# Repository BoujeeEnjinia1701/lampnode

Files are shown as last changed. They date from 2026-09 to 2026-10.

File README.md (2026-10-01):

# LampNode

     

**Area:** Smart Cities · **TRL:** 3 of 9 (proof of concept on paper) · **Value-engineering target:** about $150 USD · **Difficulty:** 3 of 5

An open streetlight controller that dims LED streetlights by schedule and presence, reports faults and hosts other city sensors on the lamp pole.

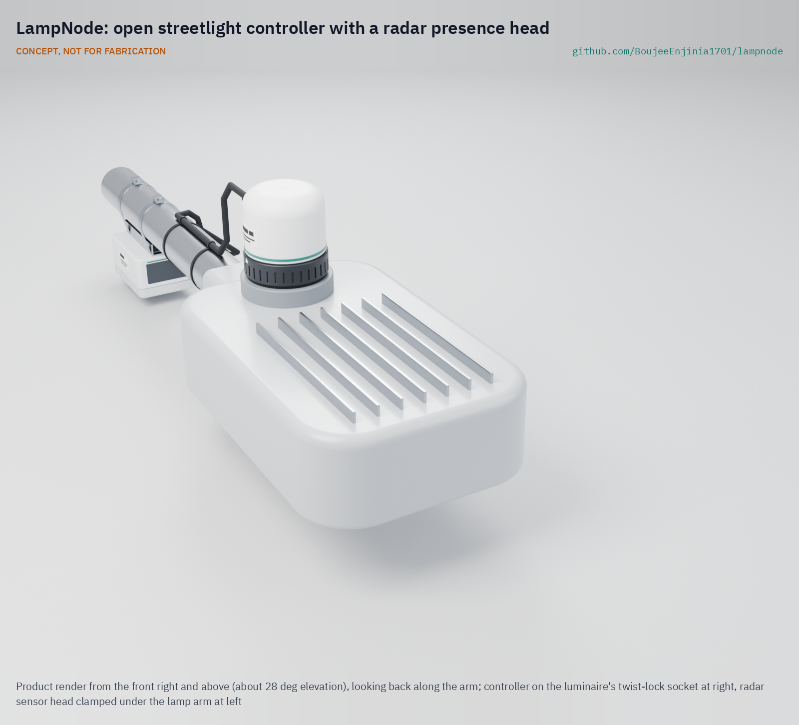
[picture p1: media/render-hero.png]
LampNode: open streetlight controller with a radar presence head, product render


[Exploded render](media/render-exploded.png) · [Detail render](media/render-detail.png) · [Interactive 3D model](media/viewer.html) · [Concept blueprint (PDF)](media/concept-blueprint.pdf) · [General arrangement LPN-DWG-001 (PDF)](cad/drawings/LPN-DWG-001.pdf) · [Sizing calculations](docs/04-calcs/01-sizing.md) · [Prototype build plan](docs/05-build-plan.md) · [Design decisions](docs/06-design-decisions.md) · [Review note](docs/REVIEW.md)

## Concept rationale

Many LED streetlights already have a twist-lock socket on top, built for a photocell, and the D4i driver standard supports both the NEMA/ANSI C136.41 and the Zhaga Book 18 sockets ([DALI Alliance](https://www.dali-alliance.org/d4i/)). A controller that plugs into that socket can dim the lamp, measure its energy and report faults without anyone opening the luminaire or the pole. LampNode uses that socket, the 0 to 10 V dimming input most LED drivers already have, and a small radar head under the arm that raises the light only when someone is coming. Because the controller already has mains power and a radio on the pole, the same head offers two powered ports for other city sensors, so a street can gain air, noise or traffic sensing without new wiring.

It is open and garage-buildable because the main problem with smart streetlights is not the electronics but lock-in: the controller, network and software usually come from one supplier. LampNode uses a standard socket, the same LoRaWAN radio as the lab's FieldNode, and a published message format, so a city, a utility or a campus can build, inspect or replace any part of it and read its data with any LoRaWAN server, including TwinKit and CityTwin.

## Burning platform

Streetlights mostly burn at full power all night, and cities often cannot see what they use: the US Energy Information Administration says it has no estimate of electricity use for public street and highway lighting ([EIA](https://www.eia.gov/tools/faqs/faq.php?id=99&t=3)). Yet the savings from dimming are large. On 14 LED-lit Swedish roads, a dimming schedule alone could save about 49 % of the energy ([Jägerbrand, 2016](https://www.mdpi.com/1996-1073/9/5/357)). Meanwhile citizen observations from 2011 to 2022 are consistent with the night sky brightening by 7 to 10 % per year ([Kyba et al., 2023, via GFZ](https://www.gfz.de/en/press/news/details/citizen-scientists-report-global-rapid-reductions-in-the-visibility-of-stars-from-2011-to-2022)).

Faults are still found by people. New York City maintains nearly 400,000 streetlights and asks residents to call 311 to report problems ([NYC DOT](https://www.nyc.gov/html/dot/html/infrastructure/streetlights.shtml)). Networked controllers exist, but the industry's own interoperability body describes its protocol as a way to "avoid vendor-lock-in" ([TALQ](https://www.talq-consortium.org/)), which is why an open device matters.

## Where it could be used

### By industry

| Industry | Use |
| --- | --- |
| Municipal street lighting and public works | Night dimming, fault lists for crews, and energy data per lamp on residential and collector roads |
| Electric utilities that own streetlights | Day-burner detection, measured energy per lamp, remote switching during grid events |
| Road and highway authorities | Adaptive lighting on low-traffic roads within the lighting class they set |
| Campuses, ports, car parks and industrial sites | Presence dimming on private roads and yards with their own LoRaWAN gateway |
| Smart city sensing | A powered, networked mount for air, noise and traffic sensors (AirStreet, NoiseMap, CurbCount) |
| Housing associations and private estates | Lower lighting bills and fault reports on private streets |

### By country or region

| Country or region | Why it matters there |
| --- | --- |
| United States | Large networks with faults still reported by residents: New York City maintains nearly 400,000 streetlights and asks residents to call 311 about problems ([NYC DOT](https://www.nyc.gov/html/dot/html/infrastructure/streetlights.shtml)); LampNode targets the NEMA/ANSI C136.41 socket, which D4i drivers also support ([DALI Alliance](https://www.dali-alliance.org/d4i/)) |
| Sweden and the Nordic countries | Long winter nights; a dimming schedule could save about 49 % on the Swedish roads studied ([Jägerbrand, 2016](https://www.mdpi.com/1996-1073/9/5/357)) |
| European Union | Luminaires with Zhaga Book 18 sockets and D4i drivers can power and host a module with no rewiring ([DALI Alliance](https://www.dali-alliance.org/d4i/)); a Zhaga variant of LampNode is an open question |
| India | By June 2024 the Street Lighting National Programme had installed more than 13 million LED streetlights in 29 states and union territories, saving an estimated 8,806 GWh a year ([PIB, 2024](https://www.pib.gov.in/PressReleasePage.aspx?PRID=2040102&reg=48&lang=2)); a retrofit controller could add presence dimming and fault reports to that installed base |
| Philippines | In Quezon City, street lighting made up 65 % of the city's electricity costs and 5 % of its overall budget ([World Bank, 2017](https://blogs.worldbank.org/en/energy/led-street-lighting-unburdening-our-cities); [case study](https://documents.worldbank.org/curated/en/842031477930270833/)), so every hour of dimming shows up in the city's accounts |
| Brazil | Public lighting uses about 4 % of the country's electricity and 10 to 40 % of municipal energy budgets; Belo Horizonte is upgrading 178,000 streetlights to LED under a 20-year PPP contract ([ESMAP](https://www.esmap.org/node/57541)), a term over which open, multi-vendor controllers would let a city change suppliers |

## What sparked the idea

The starting point was Detroit. By mid-2013 more than half of the city's 88,000 streetlights were estimated to be out; the relighting that began in April 2014 replaced them with 65,000 LED lights for $185 million ([US Department of Energy](https://www.energy.gov/eere/ssl/articles/detroit-street-lighting-report)) and was finished in December 2016 ([Michigan Public, 2016](https://www.michiganpublic.org/news/2016-12-16/detroit-celebrates-65-000-new-led-streetlights)). In May 2019 the city's Public Lighting Authority sued the manufacturer over about 20,000 of those fixtures, a third of the new system, that were dimming and burning out early ([Michigan Public, 2019](https://www.michiganpublic.org/law/2019-05-07/some-of-detroits-new-led-streetlights-are-burning-out-city-sues-manufacturer)). Even a brand-new, efficient network could degrade at scale before its owner had the data to see it. A small controller on each lamp that measures its power and reports a lamp that is out, cycling or drawing the wrong power would let the owner see such faults as they develop, and an open design would let any city fit, inspect and repair it without tying the network to one supplier.

## Problem

Streetlights burn at full power all night, faults are reported by residents, and proprietary controllers lock cities into one vendor.

## Concept

An open streetlight controller that dims LED streetlights by schedule and presence, reports faults and hosts other city sensors on the lamp pole.

A twist-lock controller replaces the photocell on the luminaire and drives its 0 to 10 V dimming input; a sensor head clamped under the arm carries a 24 GHz radar for presence and two powered M12 ports for other sensors; status and faults go out every 15 min over LoRaWAN.

TRL 3 calculations ([LPN-CAL-001](docs/04-calcs/01-sizing.md)) put a 100 W luminaire at 40° N at about 432 kWh a year under a photocell and 275 to 285 kWh with the reference presence profile, a saving of 34 to 36 % against a 35 % target. The controller draws 0.68 W on average, and the parts of the constructable design are estimated at USD 143, USD 7 under the USD 150 value-engineering target. No requirement is clearly missed, but four are at risk on paper: relay inrush, presence detection in rain and wind, the energy saving (kept at a 35 % target with the risk accepted) and the temperature margin in full sun. Power for hosted sensors is met on paper because the firmware limits the ports to 2.5 W above 50 °C inside. 347 V and 480 V circuits, DALI-2 D4i dimming and a TALQ bridge are later variants or sibling scope. The design choices were decided by Amish on 2026-09-25 ([LPN-DDR-001](docs/decisions/0001-trl2-review-decisions.md), [LPN-DDR-002](docs/decisions/0002-recommendations-accepted.md)); only the first co-design partner is still open. See the [requirements](docs/03-requirements.md).

Full design precis: [docs/02-concept.md](docs/02-concept.md)

## Key components

- Twist-lock base for the ANSI C136.41 7-contact receptacle
- 385 V class surge stage, isolated 12 V power supply and a normally closed (fail-on) relay closed at the voltage zero crossing
- Energy metering (indicative, not revenue grade), calibrated once at build
- STM32WL-class controller with LoRaWAN radio (shared with FieldNode), TCXO clock and tilt sensor
- 0 to 10 V dimming output and ambient light sensor
- Sensor head under the arm with a 24 GHz radar presence sensor with direction (I/Q) output
- Two sealed 5-pole M12 expansion ports, 12 V SELV, 3 W total (2.5 W above 50 °C inside)

The parametric model is in [cad/src/model.py](cad/src/model.py), with STEP and STL exports in `cad/step/` and `cad/stl/`. The working bill of materials is in [bom/bom.csv](bom/bom.csv).

## Building the prototype

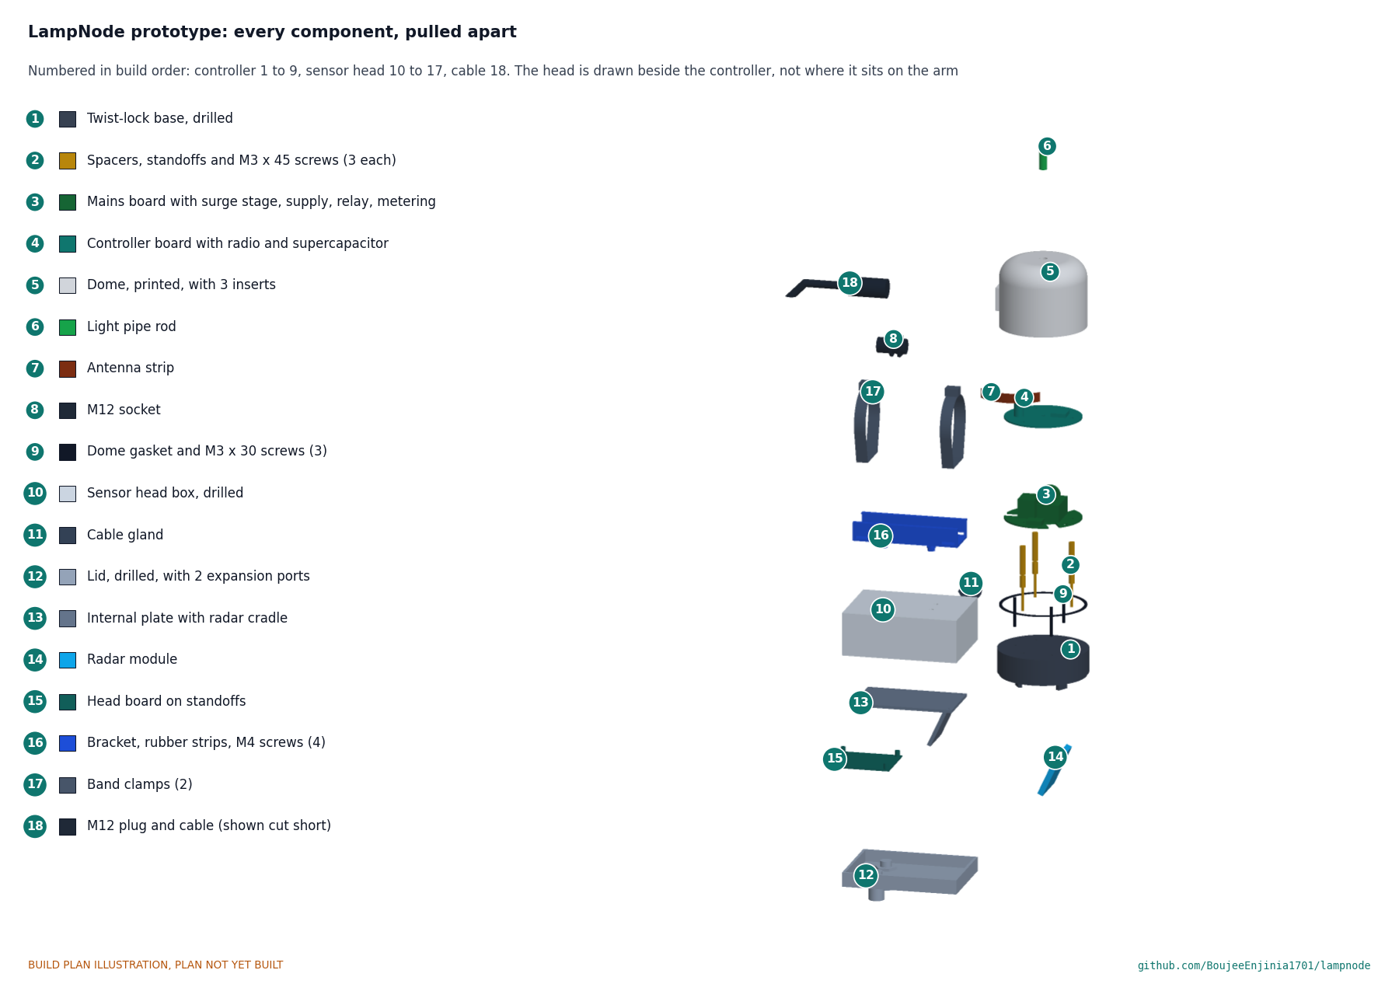
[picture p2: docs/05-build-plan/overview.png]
LampNode prototype: every component pulled apart and numbered in build order


The [prototype build plan](docs/05-build-plan.md) (LPN-BLD-001) shows, in pictures, how to make each of the eighteen components and put them together in eleven steps on a bench mock-up of a streetlight; nothing has been built yet. The made parts are a drilled twist-lock base, two round prototype boards, a printed dome with a light-pipe rod, a drilled sensor head box, a printed internal plate with a radar cradle and a folded aluminium bracket; the electronics are bought modules wired at block level. Writing the plan made the design buildable: the parts inside the controller and the head now sit on spacers, standoffs and bosses, the dome screws to the base, the M12 socket moved to a flat pad on the dome, and the bracket became a folded channel that the band clamps pass through (LPN-DDR-003, open for Amish's review). Every picture is drawn from the model, and the model checks that each part touches what it should and clears what it should not.

## Safety

> Mains wiring must be done or checked by a qualified electrician and follow local electrical code. LampNode connects to up to 277 V AC in the luminaire socket; a prototype must not go on a public lighting network until it has passed the tests the asset owner requires. Street furniture and pole mounts must be installed only with the asset owner's permission, by trained crews, with fall protection and traffic management as local rules require.
>
> A controller fault must never leave a street dark: the relay fails on, and light levels are set by the road owner, not by LampNode. The socket has no earth contact, so surge protection is line to neutral only. Privacy by design: the radar reports motion only; no images, audio recordings or personal identifiers leave the device.

## Repository layout

| Folder | Contents |
| --- | --- |
| `docs/` | Problem, concept, requirements, calculations and design decisions |
| `cad/src/` | build123d Python source, the source of truth for all geometry |
| `cad/step/`, `cad/stl/` | Exported models for FreeCAD, other CAD tools and printing |
| `cad/drawings/` | 2D sketches and dimensioned drawings |
| `bom/` | Bill of materials |
| `electronics/` | KiCad schematics and PCB layouts |
| `firmware/` | Microcontroller code |
| `media/` | Renders, perspectives and photos |
| `build-log/` | Dated prototyping notes |

## Documentation

Controlled documents follow the portfolio [documentation standard](.kit/STANDARDS.md). Each carries a document ID (LPN-PRC-001 for the precis), a version and a revision history. Branded PDFs are built with `python .kit/render.py` and attached to GitHub Releases when a document is tagged, for example `LPN-PRC-001/v1.0`.

## Credits

Designed by Amish Chadha. See [CONTRIBUTORS.md](CONTRIBUTORS.md) for roles. To cite this design, use [CITATION.cff](CITATION.cff) (GitHub shows it as "Cite this repository").

AI assistance (Claude) was used to accelerate concept renders, prototype documentation and first-pass sizing calculations. Design direction and all decisions are Amish Chadha's, recorded in this repository's decision records (`docs/decisions/`).

## Licenses

- **Hardware** (CAD, drawings, BOM, electronics): [CERN-OHL-S v2](LICENSE)
- **Software** (firmware, scripts, notebooks): [MIT](LICENSE-SOFTWARE)

A project of the [Design Molecule](https://designmolecule.com) lab.

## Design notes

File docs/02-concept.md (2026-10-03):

---
doc_id: LPN-PRC-001
title: LampNode design precis
project: LampNode
doc_type: Design precis
version: "0.7"
status: Draft
date: '2026-10-02'
author: Amish Chadha
license: CERN-OHL-S-2.0
revisions:
- version: "0.1"
  date: '2026-09-25'
  author: Amish Chadha
  change: Initial scaffold
- version: "0.2"
  date: '2026-09-25'
  author: Amish Chadha
  change: Concept for TRL 2, main components, first-order numbers, design choices, safety and open questions
- version: "0.3"
  date: '2026-09-25'
  author: Amish Chadha
  change: TRL 3 update. Design choices adopted for TRL 3 under Amish's 2026-09-25 instruction, open for his review (LPN-DDR-001); numbers replaced by LPN-CAL-001; relay, clock, surge stage, radar and port changes; parametric model and drawing LPN-DWG-001
- version: "0.4"
  date: '2026-09-25'
  author: Amish Chadha
  change: Recommendations accepted by Amish (DDR-002)
- version: "0.5"
  date: '2026-10-01'
  author: Amish Chadha
  change: Design made constructable (LPN-DDR-003); component descriptions, mass and cost updated; budget treated as a value-engineering target
- version: "0.6"
  date: '2026-10-02'
  author: Amish Chadha
  change: 'Decisions of 2026-10-02 (LPN-DEC-001): first partner and band, port pinout proposed to FieldNode'
- version: "0.7"
  date: '2026-10-02'
  author: Amish Chadha
  change: 'US915 airtime limit (400 ms dwell) added to the key figures; figures and pictures regenerated; no requirement status changed'
---

# LampNode design precis

## Summary

LampNode is a twist-lock controller that replaces the photocell on top of an LED streetlight, plus a small sensor head clamped under the lamp arm. The controller switches and dims the luminaire over its standard 0 to 10 V input, follows a night schedule held on the device, raises the light when the sensor head's radar sees someone approaching, measures the lamp's energy and reports faults over LoRaWAN. The sensor head also offers two powered, sealed ports for other city sensors.

The TRL 3 calculations (LPN-CAL-001) put the energy of a 100 W luminaire at 40° N at about 432 kWh a year under a photocell and about 275 to 285 kWh with the reference presence profile, a saving of **34.1 to 36.4 %** against the 35 % target of R7. The TRL 2 estimate of about 41 % assumed nights that were too uniform. The controller draws 0.68 W on average, and the parts are estimated at USD 143.00 against a USD 150 value-engineering target (USD 7.00 under it). Four requirements are at risk on paper (R3, R6, R7, R11); none is clearly not met. R13 is met on paper once the firmware limits the hosted ports to 2.5 W above 50 °C inside. The design choices below were decided by Amish on 2026-09-25 (LPN-DDR-001, LPN-DDR-002).

Figure 1 (`media/hero.png`) shows LampNode on a 7.8 m street pole with a 1.75 m person for scale; Figure 2 (`media/exploded.png`) numbers the parts to match `bom/bom.csv`; Figure 3 (`media/cutaway.png`) shows the inside of the controller; Figure 4 (`media/flow.png`) shows the annual energy; Figure 5 (`cad/drawings/LPN-DWG-001.pdf`) is the general arrangement at Rev P4, generated from `cad/src/model.py`. The design was made constructable on 2026-09-30 (LPN-DDR-003); how each part is made and fitted is in the prototype build plan, LPN-BLD-001 (`docs/05-build-plan.md`).

## How it works

1. **At dusk** the light sensor sees the light level fall below a set threshold, or the astronomical clock reaches dusk. The controller treats it as day only when both the clock and the light sensor say day, so a failed sensor or a wrong clock leaves the lamp on. The lamp starts at the level the road owner set; the default is full output.
2. **During the night** the controller steps the 0 to 10 V output through the road owner's schedule, for example full output until 22:00, then a lower floor.
3. **When someone approaches** the radar in the sensor head sees motion toward the lamp. The radar has I/Q (direction) output, so rain, which always moves away from a downward-looking beam, is ignored. The head tells the controller over the M12 cable, and the controller ramps the lamp to full output in about 0.63 s, holds it for a set time and ramps back down.
4. **Every 15 min** the controller sends a 24-byte LoRaWAN status message: energy, power, voltage, dimming level, presence count and fault flags. Schedules and settings come back as downlinks, and the network also sets the clock, but the lamp never depends on the network to run. A TCXO real-time clock keeps drift under 10 s a month without the network.
5. **When something goes wrong** the controller sends a fault message at once: lamp out, lamp burning in daylight, cycling, pole tilted or knocked down, or mains lost (a 0.22 F supercapacitor holds about 9 times the energy of a last message). A gateway such as TwinKit, or any LoRaWAN network server, flags a node that goes silent.
6. **When the dome gets hot** the controller limits the two expansion ports to 2.5 W in total while its interior is above 50 °C, so the 5 W supply stays within its derated output (LPN-DDR-002). Hosted sensors must tolerate the lower allowance.
7. **If the controller fails** the relay closes and the lamp stays on. The relay coil is driven through a charge pump that needs a toggling signal from the controller, so a stopped or hung controller drops the coil. An open 0 to 10 V line leaves typical drivers at full output.
8. **When the relay switches** it closes at a zero crossing of the mains voltage, timed from the metering IC, which cuts the LED driver inrush from about 72 A to about 20 A.

## Main components

Numbers match Figure 2 and `bom/bom.csv`.

| No. | Component | Role |
| --- | --- | --- |
| 1 | Twist-lock base, 7-contact | ANSI C136.41 plug: line, neutral and switched load blades; four low-voltage contacts for dimming and two auxiliary lines. There is no earth contact. Six countersunk screws from underneath hold the dome and the board stack |
| 2 | Dome cover | UV-stabilized ASA, 90 mm diameter, 72 mm tall on a 1 mm gasket, 97 mm tall with the base; three screw bosses, a flat pad for the M12 socket and an 8 mm light-pipe hole |
| 3 | Surge protection and fuse | Thermal fuse and a thermally protected 20 mm, 385 V class varistor line to neutral; TVS diodes on the low-voltage leads |
| 4 | Isolated power supply | 85 to 305 V AC in, 12 V out, 5 W; creates the SELV side that feeds the electronics, the dimming output and the expansion ports |
| 5 | Fail-on relay | Normally closed, 16 A, rated for 80 A inrush or better; coil (about 0.4 W) energized in daytime only |
| 6 | Energy metering | Single-phase metering IC with a 2 mΩ shunt on the mains side, linked to the controller through a digital isolator; one-point calibration at build |
| 7 | Controller and LoRaWAN radio | STM32WL-class module shared with FieldNode, TCXO real-time clock, accelerometer, 0 to 10 V output stage, charge-pump coil drive, 0.22 F supercapacitor for the last message |
| 8 | Antenna | Sub-GHz antenna inside the dome, above the luminaire's metal body |
| 9 | Light sensor and pipe | Ambient light sensor under a clear 8 mm rod sealed through the dome top, for dusk and dawn and for day-burner checks |
| 10 | M12 port and cable | 5-pole M12 socket in a flat pad on the pole side of the dome and about 1 m of cable along the arm to the sensor head: 12 V and a two-wire serial link |
| 11 | Sensor head enclosure | IP66 box 120 x 90 x 60 mm clamped under the arm, 470 mm from the receptacle toward the pole |
| 12 | 24 GHz radar presence sensor | Doppler module with I/Q output, tilted 25° below horizontal along the street; motion, speed and direction only |
| 13 | Sensor head board | Small microcontroller that turns the radar signal into presence events, and switches power to the expansion ports |
| 14 | Expansion ports (2) | Sealed 5-pole M12 sockets with the pinout proposed to FieldNode (pin 1 supply, pin 3 ground, pins 2 and 4 RS-485, pin 5 wake), 12 V SELV, 3 W total |
| 15 | Arm band clamps | Two stainless band clamps for 50 to 80 mm arms through slots in a folded aluminium bracket, with rubber strips where the arm rests; no drilling of the arm |
| 17 | Controller boards and fixings | Round mains board on three spacers carrying items 3 to 6, standoffs to the controller board, screws, inserts and the dome gasket |
| 18 | Head internal plate | Printed plate on the box bosses, carrying the head board and a 25° cradle for the radar |

The luminaire, its receptacle, the arm and the pole are existing street furniture and are not part of LampNode. The model shows the receptacle and a length of arm as grey reference parts.

## Numbers at TRL 3

All values come from LPN-CAL-001 and `docs/04-calcs/sizing.py`. They are calculations with typical part values, not measurements.

*Table 1. Annual energy for one 100 W luminaire at 40° N (4,323 h a year).*

| Case | Energy per year | Saving |
| --- | --- | --- |
| Photocell, full power | 432 kWh | |
| Schedule only (50 % from 23:00 to 05:00) | 324 kWh | 25.0 % |
| Reference presence profile with controller use, ideal driver | 275 kWh | 36.4 % |
| Same, dimmed driver model | 285 kWh | 34.1 % |

The saving depends mostly on traffic. With the dimmed driver model it is 40.4 % with no traffic, 34.4 % at 8 isolated passes an hour and 22.0 % at 30. At 60° N it falls to 31.8 %. The saving is of the same order as the 49 % that Jägerbrand estimated for a dimming schedule on Swedish roads ([Jägerbrand, 2016](https://www.mdpi.com/1996-1073/9/5/357)).

*Table 2. Other key figures.*

| Quantity | Value | Requirement |
| --- | --- | --- |
| Average draw from the mains | 0.68 W | R10 met |
| 12 V peak, ports limited to 2.5 W above 50 °C inside | 3.40 W against 3.57 W available at 64 °C (3.90 W against 3.55 W without the limit) | R13 met on paper |
| Inrush, 100 W driver at 277 V | 72 A at random closing, about 20 A at zero-cross closing | R3 at risk |
| Clock drift without the network, 30 days | 9.1 s with the TCXO clock (160 s at -10 °C with a plain crystal) | R5 met on paper |
| Radar | Beam covers 7.5 to 47.9 m for a walking person; 36 dB signal to noise at 15 m; 0.63 s to full | R6 at risk |
| Metering error | 1.65 % worst case with a one-point calibration | R8 met on paper |
| Status airtime | 267 ms per message, 25.7 s a day at SF9 (US915: inside the 400 ms dwell limit; SF9 or faster) | R15 |
| Interior temperature at 45 °C in sun | 63 to 65 °C | R11 at risk |
| Varistor energy at 5 kA | 118 J | R11 |
| Mass | Controller 0.33 kg; head with clamps and cable 0.42 kg | |
| Parts cost | USD 143.00 (controller USD 75.00, head USD 61.00, hardware USD 7.00) against the USD 150 value-engineering target | R16: USD 7.00 under the target |
| Payback on parts | 3.9 to 9.7 years at USD 0.25 to 0.10 per kWh, before labor | |

## Key design choices

Each choice below is **Decided by Amish, 2026-09-25: go with recommendation** (LPN-DDR-001, LPN-DDR-002).

1. **Socket:** ANSI C136.41 7-contact first, since it is the photocontrol socket widely used on existing roadway luminaires in North America and suits retrofits; a Zhaga Book 18 variant later for newer D4i luminaires.
2. **Presence sensor:** 24 GHz Doppler radar, which senses motion through a plastic cover, is not blinded by heat and cannot form an image; schedule-only operation stays as a firmware mode.
3. **Sensor head link:** a cable from the controller to a head under the arm, so one mains connection powers both.
4. **Radio:** LoRaWAN on the STM32WL-class module shared with FieldNode and TwinKit.
5. **Dimming:** 0 to 10 V only; DALI-2 D4i on the auxiliary contacts only if a partner's stock needs it.
6. **Fail-on relay:** normally closed contact, energized to turn the lamp off in daytime.
7. **Hosted sensor power:** 12 V SELV, 3 W total on two ports, limited by firmware to 2.5 W above 50 °C inside, whenever the luminaire feed is live. Sibling sensors such as AirStreet and NoiseMap stay on FieldNode solar and may use LampNode power as an option.
8. **Default policy:** the controller ships with photocell-equivalent behavior (full output all night); any dimming profile is set by the road owner.
9. **Mains range:** 120 to 277 V; a 347 V and 480 V variant later if a partner needs it.
10. **Interoperability:** open LoRaWAN and a published payload; a TALQ bridge belongs to CityTwin.

The TRL 3 calculations added engineering changes, also decided by Amish on 2026-09-25 (LPN-DDR-001 O4 to O8): the TCXO clock, the high-inrush relay with zero-cross closing, the 385 V surge stage without a gas discharge tube, the charge-pump coil drive and two-signal day logic, the I/Q radar and 5-pole M12 ports to match FieldNode. Amish also decided to keep R7 at 35 % with the reference profile and accept the risk until real traffic counts exist (O2), and to meet R13 at high temperature with the firmware port limit rather than a 10 W supply (O3).

## Safety

> **Safety:** LampNode connects to mains voltage (up to 277 V AC nominal, 305 V maximum) inside the luminaire's receptacle. Only qualified electricians may fit or remove it, with the circuit isolated where local rules require. The prototype must not be plugged into a public lighting network until it has passed the surge, insulation and safety tests that the asset owner requires.

> **Safety:** Work on streetlights is work at height beside traffic. Use a bucket truck or a suitable access platform, fall protection and traffic management as local rules require, and only with the asset owner's permission.

> **Safety:** A controller fault must never leave a street dark. The normally closed relay, the charge-pump coil drive and the open-line behavior of the 0 to 10 V driver must be checked on every driver model used. Light levels and dimming floors are the road owner's decision, not LampNode's.

> **Safety:** Surges on long street lighting feeders can destroy electronics and start fires. The socket has no earth contact, so LampNode clamps line to neutral only; the varistor must be thermally protected and fused, and the housing material flame-rated. Relay contacts welded by inrush would leave a lamp burning in daylight; the day-burner check must report it.

- **Privacy:** the radar reports motion, speed and direction only. No images, audio or personal identifiers are captured or leave the device. Check local data protection law before any deployment.
- **Radio:** 24 GHz radar and sub-GHz LoRa modules must be used within local radio regulations; use certified modules.
- **Expansion ports:** 12 V SELV only, fused per port, 2.5 W in total above 50 °C inside. Hosted devices must not connect to mains.
- **Heat:** in 45 °C sun the inside of the dome reaches about 65 °C; the supercapacitor and supply must be rated for it.

## Open questions after TRL 3

1. Radar false triggers from rain, wind-blown trees and passing traffic, and the real cross-section of a person seen from 7.7 m (R6). Needs a field trial.
2. A normally closed relay with an 80 A or better inrush rating, and the partner's driver inrush data (R3).
3. Surge level and test standard: ANSI C136.2 and the asset owner's specification (R11). The standard was not read in this session.
4. R7 shortfall: the risk is accepted by Amish's decision (LPN-DDR-002); real traffic counts from a first partner would settle it. The first partner is to be a US partner on the 915 MHz band; the first candidate to approach is a university campus or municipal utility in the Dallas-Fort Worth area that runs LED streetlights with ANSI C136.41 sockets (decided 2026-10-02, LPN-DEC-001).
5. Sensor port pinout: LampNode proposes to FieldNode pin 1 supply (12 V on LampNode), pin 3 ground, pins 2 and 4 a two-wire RS-485 pair, pin 5 a wake line; hosted sensors accept 5 to 12 V and regulate down themselves (decided 2026-10-02, LPN-DEC-001); FieldNode and the adopting teams still have to agree it (FieldNode O2).
6. Whether neighboring lamps should also brighten ahead of a pedestrian, which needs a lamp-to-lamp message path.
7. A DALI-2 D4i variant and a Zhaga Book 18 form, if a partner needs them.

## Key design decisions

Decisions are recorded in [decisions/](decisions/). [0001: TRL 2 review decisions](decisions/0001-trl2-review-decisions.md) (LPN-DDR-001) lists the TRL 2 recommendations and their status. [0002: Recommendations accepted](decisions/0002-recommendations-accepted.md) (LPN-DDR-002) records Amish's 2026-09-25 acceptance of every recommendation and the one item still open.

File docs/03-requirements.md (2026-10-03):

---
doc_id: LPN-REQ-001
title: LampNode requirements
project: LampNode
doc_type: Requirements
version: "0.7"
status: Draft
date: '2026-10-02'
author: Amish Chadha
license: CERN-OHL-S-2.0
revisions:
- version: "0.1"
  date: '2026-09-25'
  author: Amish Chadha
  change: Initial scaffold
- version: "0.2"
  date: '2026-09-25'
  author: Amish Chadha
  change: First measurable requirements for TRL 2, with status against the concept estimates
- version: "0.3"
  date: '2026-09-25'
  author: Amish Chadha
  change: R2, R4, R13 and R15 redefined per LPN-DDR-001 (adopted for TRL 3, open for Amish's review); reference case night hours from LPN-CAL-001; status column now gives the TRL 3 result
- version: "0.4"
  date: '2026-09-25'
  author: Amish Chadha
  change: Recommendations accepted by Amish (DDR-002)
- version: "0.5"
  date: '2026-10-01'
  author: Amish Chadha
  change: R16 reported against the value-engineering target for the constructable design (LPN-DDR-003)
- version: "0.6"
  date: '2026-10-02'
  author: Amish Chadha
  change: 'R13 states the port pinout proposed to FieldNode on 2026-10-02 (LPN-DEC-001); no status changed'
- version: "0.7"
  date: '2026-10-02'
  author: Amish Chadha
  change: R15 airtime restated for the US915 band (400 ms dwell limit; status at SF9 or faster); no status changed
---

# LampNode requirements

These are the requirements for the concept at TRL 3. Targets are proposals for review, not yet validated with a lighting authority or users, and will be revised after co-design (see LPN-PRB-001). R2, R4, R13 and R15 were redefined on 2026-09-25 to match the TRL 2 recommendations, which Amish accepted the same day (LPN-DDR-001, LPN-DDR-002). R13 was restated again to include the firmware port limit he decided (LPN-DDR-001 O3), and R7 is kept at 35 % with its risk accepted (O2). The status column gives the result of the TRL 3 calculations in LPN-CAL-001.

The **reference case** used throughout is a 100 W LED cobra-head luminaire with a 0 to 10 V driver, its arm about 7.8 m above a residential street at 40° N, lit from sunset to sunrise: 4,323 h a year, 11.84 h a night on average (LPN-CAL-001; TRL 2 assumed about 4,100 h).

Table 1. Requirements

| ID | Requirement | Target | Verification | TRL 3 status (LPN-CAL-001) |
| --- | --- | --- | --- | --- |
| R1 | Fit the existing socket | Plugs into an ANSI C136.41 7-contact twist-lock receptacle; replaces a photocontrol with no tools and no luminaire rewiring in 5 min or less at height | Dimensional check against the standard; fit trial on a donor luminaire | Not verifiable at TRL 3: representative base in the model |
| R2 | Mains supply range | 120 to 277 V AC nominal, 50 or 60 Hz, operating from 100 to 305 V. 347 V and 480 V circuits are a later variant, out of scope until a partner needs them (redefined, LPN-DDR-001 D9) | Power supply datasheet; design review | Met (design review): 85 to 305 V supply, 385 V class varistor |
| R3 | Switch the luminaire | Switch LED luminaire loads up to 400 W at 277 V, with a relay rated for the driver's inrush current, for 100,000 or more cycles | Relay datasheet against driver inrush data | **At risk:** 72 A inrush per 100 W driver at random closing; about 20 A with zero-cross closing |
| R4 | Dim the luminaire | 0 to 10 V dimming output, 10 to 100 % in 1 % steps, sinking at least 10 mA, isolated from mains. DALI-2 D4i is a later variant, added only if a partner's stock needs it (redefined, LPN-DDR-001 D5) | Circuit review; bench check at TRL 4 | Met (design review): 2.44 mV steps, 5 drivers per output |
| R5 | Schedule without the network | Astronomical clock (dusk and dawn from latitude and longitude) and at least 8 dimming steps per night; keeps running with no network for 30 days or more, clock drift 2 min or less | Firmware sketch review; clock drift calculation | Met on paper with the TCXO clock: 9.1 s in 30 days (a plain crystal drifts 160 s at -10 °C) |
| R6 | Detect presence | Detect a walking pedestrian at 15 m or more and a cyclist or car at 25 m or more along the street; raise the lamp to full within 1 s; hold for a set time (default 60 s) | Radar calculation; field trial | **At risk:** 36 dB signal to noise at 15 m and 0.63 s to full, but rain, trees and clutter unverified |
| R7 | Save energy | 35 % or more annual energy reduction versus photocell full-power operation in the reference case, controller use included. Target and reference profile kept, risk accepted until real traffic counts exist (LPN-DDR-002, O2) | Energy calculation (LPN-CAL-001) | **At risk:** 36.4 % with an ideal driver, 34.1 % with the dimmed driver model |
| R8 | Measure energy | Active power within ±2 % from 10 to 400 W; also voltage, current, power factor and cumulative energy; reported every 15 min | Error budget; calibration method | Met on paper: 1.65 % worst case, with a one-point calibration of each unit |
| R9 | Report faults | Detect lamp out, day burning, cycling, tilt or knock-down, and loss of mains; report within 30 min; the server flags a node silent for 1 h | Fault logic review; last-gasp energy | Met (design review): 1.32 J stored against 0.144 J needed |
| R10 | Low self-consumption | 1.0 W or less average from the mains, sensor head included, expansion ports unloaded | Power budget | Met on paper: 0.68 W |
| R11 | Survive the environment | IP66; operate from -30 to +70 °C; UV-stable housing; proposed surge target 10 kV / 5 kA combination wave, final level taken from ANSI C136.2 | Datasheets, thermal and surge calculations; tests at TRL 4 | **At risk:** 63 to 65 °C inside at 45 °C in sun; 118 J in the varistor at 5 kA; IP66 and surge need tests |
| R12 | Fail safe | Lamp on at night if the controller, firmware or network fails; lamp on within 2 s of power-up at dusk without the network; open 0 to 10 V line gives full output | Circuit and firmware review | Met (design review): normally closed relay, toggling coil drive; driver open-line behavior to be confirmed |
| R13 | Host other sensors | Two sealed 5-pole M12 expansion ports with the FieldNode sensor port pinout (as proposed to FieldNode on 2026-10-02, LPN-DEC-001: pin 1 supply, pin 3 ground, pins 2 and 4 a two-wire RS-485 pair, pin 5 a wake line; hosted sensors accept 5 to 12 V), 12 V SELV, 3 W total, limited by firmware to 2.5 W total when the controller interior is above 50 °C (LPN-DDR-002, O3), cable up to 10 m, whenever the luminaire feed is live. Hosted sensors that need power around the clock on cabinet-switched feeders bring their own storage, such as a FieldNode core (redefined, LPN-DDR-001 D7) | Power budget; design review | Met on paper with the firmware port limit: 3.40 W peak against 3.57 W at 64 °C (3.90 W against 3.55 W without it) |
| R14 | Privacy | Presence only: no images, audio or personal identifiers are captured or leave the device; optional 15 min presence counts | Design review; open firmware | Met (design review) |
| R15 | Secure and open | LoRaWAN 1.0.4 or later with AES-128 session keys; signed firmware; published payload format; works with any LoRaWAN network server. A TALQ bridge belongs to CityTwin, not to LampNode (redefined, LPN-DDR-001 D10) | Firmware sketch review | Met (design review): US915 band; 25.7 s of airtime a day at SF9, with every message inside the 400 ms dwell limit per channel (status at SF9 or faster) |
| R16 | Affordable | Controller and one sensor head $150 or less in parts at prototype quantities | Priced BOM (`bom/bom.csv`) | USD 143.00 for the constructable design, USD 7.00 under the USD 150 value-engineering target |

Summary: 0 not met, 4 at risk (R3, R6, R7, R11), 11 met on paper, by design review or under the value-engineering target, 1 not verifiable at TRL 3 (R1). The `budget_usd` figure behind R16 is a value-engineering target, not a spending limit.

## Requirements at risk

- **R3:** relay inrush. A normally closed relay with an 80 A inrush rating has to be found, and several drivers on one relay need zero-cross closing.
- **R6:** the signal budget and timing are met, but false triggers from rain, trees and traffic can only be settled in the field. The radar needs I/Q output to reject rain.
- **R7:** the saving sits close to the target and depends on traffic and driver behavior. Amish decided to keep the 35 % target and the reference profile and accept the risk until real traffic counts exist (LPN-DDR-002).
- **R11:** thermal margin in sun is about 5 to 7 K; surge and IP66 need tests.

## Assumptions

- Lit from sunset to sunrise at 40° N: 4,323 h a year (LPN-CAL-001 section 2). At 60° N it is 4,277 h. Photocells switch within minutes of sunset; the exact threshold changes the hours slightly.
- Luminaire power is either proportional to light output (ideal) or 6 % of rated plus 94 % times the light level (dimmed driver model). Real drivers vary.
- Reference dimming profile (for estimates only): full output from dusk to 22:00, then a 30 % floor with presence boosts to full from 22:00 to 06:00, and full output from 06:00 to dawn when dawn is later. Presence boosts are assumed to occupy 15 % of the dimmed hours, about 7.8 isolated passes an hour.
- For comparison, a schedule-only profile (full output except 50 % from 23:00 to 05:00) is also calculated in LPN-CAL-001.
- LampNode ships with photocell-equivalent full output (LPN-DDR-001 D8). The road owner sets the floor level and hold time. Nothing here proposes a light level for any road.

> **Safety:** LampNode connects to mains voltage and is installed at height beside traffic. Any requirement change that affects fail-safe behavior (R12) or light levels must be reviewed with the road owner.

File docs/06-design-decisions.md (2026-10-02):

---
doc_id: LPN-DEC-001
title: LampNode design decisions register
project: LampNode
doc_type: Design decisions register
version: "0.2"
status: Draft
date: '2026-10-02'
author: Amish Chadha
license: CERN-OHL-S-2.0
revisions:
  - version: "0.1"
    date: '2026-10-01'
    author: Amish Chadha
    change: Register opened with the open decisions, items to confirm, value engineering and decisions made; budget treated as a value-engineering target
  - version: "0.2"
    date: '2026-10-02'
    author: Amish Chadha
    change: 'Amish approved the recommendations for all six open decisions on 2026-10-02 (LPN-DDR-003 accepted); moved to decisions made; tables renumbered'
---

# LampNode design decisions register

Every design decision still to be made, and every decision made, in one place. Each decision is argued in full in its decision record under `docs/decisions/`; this register is the index Amish works from. The build plan (`docs/05-build-plan.md`) describes the design as it stands and does not list open decisions.

## Open decisions

None. All open decisions were decided on 2026-10-02.

## To confirm when parts are bought

*Table 1. Assumed sizes and ratings to check against the real parts.*

| # | What to confirm | Why it matters | Source |
| --- | --- | --- | --- |
| 1 | The base kit has solid material or bosses at the six screw positions on the 60 mm circle, and its blades have crimp or solder terminals inside | The dome and board stack screw through it | LPN-DDR-003, P2, P7 |
| 2 | The head box's four internal bosses are 94 x 54 mm apart and 6 mm long, and its lid is 15 mm deep | They set the internal plate holes and the radar height | LPN-DDR-003, P8 |
| 3 | The supply module fits 23 x 38 x 18 mm and the relay 18 x 24 x 20 mm, with an inrush rating of 80 A or more | The mains board layout and the notches depend on these sizes; R3 needs the rating | LPN-DDR-003, P6; LPN-CAL-001 |
| 4 | The M12 panel socket's thread suits a 6 mm wall and a 16.2 mm hole | The dome pad is 6 mm thick | LPN-DDR-003, P3 |
| 5 | The radar module fits 50 x 44 mm and has two mounting holes | The cradle holes are drilled to suit | LPN-DDR-003, P8 |
| 6 | The band clamp size: the band loop is about 190 mm for a 50 mm arm, 220 mm for a 60 mm arm and 280 mm for an 80 mm arm (worm-drive clamps of about 60 to 90 mm nominal range) | One clamp size may not cover 50 to 80 mm arms | LPN-DDR-003, P10 |
| 7 | The flexible antenna's datasheet allows sticking it to 3 mm of plastic | Range and tuning | LPN-DDR-003, P5 |
| 8 | The driver model's inrush and its open-line dimming behaviour (full output with the 0 to 10 V line open) | Fail-on behaviour (R12) and relay sizing (R3) | LPN-CAL-001; LPN-PRC-001 |

## Value engineering

Value-engineering target: USD 150 (a hypothetical control target, not a limit). Estimated cost of the constructable design: USD 143.00 (USD 7.00 under the target). Main cost drivers and savings worth trying:

- The largest lines are the controller board with its LoRaWAN module, clock and coil drive (USD 25), the 24 GHz radar (USD 18), the twist-lock base kit (USD 10), the M12 socket and cordset (USD 10), and the supply and head board (USD 8 each).
- Making the design constructable added line 17, the controller boards and fixings (USD 7), and line 18, the printed head plate (USD 4), and raised lines 15 and 16 by USD 1 each; the total rose from USD 130 to USD 143.
- Savings worth trying: one laid-out board carrying both the mains and controller sides would replace two prototype boards, the harness and most of line 17; a cable glanded straight into the dome would save the M12 socket and plug (about USD 6) but make the head harder to swap; radar module prices fall steeply above prototype quantities.

## Decisions made

*Table 2. Decisions made, with Amish's words where recorded.*

| Date | Decision | Decided by | Record |
| --- | --- | --- | --- |
| 2026-09-25 | TRL 2 review items D1 to D10: ANSI C136.41 socket first, 24 GHz Doppler radar, cable to a head under the arm, LoRaWAN on the STM32WL-class module, 0 to 10 V dimming, fail-on normally closed relay, sibling sensors on FieldNode solar, photocell-equivalent default, 120 to 277 V, TALQ bridge in CityTwin | Amish: "i accept all your recommendations, go with them across all repos." | LPN-DDR-001, LPN-DDR-002 |
| 2026-09-25 | R7 kept at 35 % with the reference profile and its risk accepted (O2); firmware port limit of 2.5 W above 50 °C inside (O3) | Amish, same instruction | LPN-DDR-002 |
| 2026-09-25 | Engineering changes O4 to O8: TCXO clock, 80 A inrush relay with zero-cross closing, 385 V surge stage without a gas discharge tube, charge-pump coil drive and two-signal day logic, I/Q radar, 5-pole M12 ports | Amish, same instruction | LPN-DDR-002 |
| 2026-09-30 | Make the design physically buildable while drawing the build plan | Amish: "If you are realising that the design cannot be built as per concept - fix the design assumptions to match and be physically feasible as you draw the illustrations." | LPN-DDR-003 (accepted on 2026-10-02, below) |
| 2026-10-01 | `budget_usd` is a value-engineering target, not a limit | Amish: "the budgets are a hypothethical control target to ensure we are thinking along a value engineering lens. its ok to ensure wording reflects that the hypothesis budget was x - the real cost being accrued is y" | This register; LPN-CAL-001 v0.3 |
| 2026-10-02 | Design for construction accepted: the changes P1 to P11 and their knock-on changes, as made | Amish: "i approve your recommendations for all 555 open decisions." | LPN-DDR-003 |
| 2026-10-02 | Mains board of the first prototype: hand-wired boards (option a) on strict terms: bench only, powered only through an isolating transformer and an RCD with the dome on, the 6 mm gap between mains and low voltage checked before first power, and a laid-out board before any outdoor or luminaire-powered test | Amish: "i approve your recommendations for all 555 open decisions." | LPN-DDR-003, A1 |
| 2026-10-02 | M12 socket on the dome pad accepted (option a); the appearance model and renders are to be updated on Amish's Mac | Amish: "i approve your recommendations for all 555 open decisions." | LPN-DDR-003, A2 |
| 2026-10-02 | First co-design partner and region: a US partner on the 915 MHz band; first candidate to approach: a university campus or municipal utility in the Dallas-Fort Worth area that runs LED streetlights with ANSI C136.41 sockets | Amish: "i approve your recommendations for all 555 open decisions." | LPN-DDR-001, O1 |
| 2026-10-02 | Sensor port pinout proposed to FieldNode: pin 1 supply (12 V on LampNode), pin 3 ground, pins 2 and 4 a two-wire RS-485 pair, pin 5 a wake line; hosted sensors accept 5 to 12 V and regulate down themselves | Amish: "i approve your recommendations for all 555 open decisions." | LPN-DDR-002 cross-repo actions; FieldNode O2 |
| 2026-10-02 | Appearance model: items 1, 5 and 6 accepted for the renders only; items 2, 3 and 4 (cable route, band clamps, bracket) are to be redrawn to the constructable design of P10 and P11 when the renders are next made | Amish: "i approve your recommendations for all 555 open decisions." | `docs/REVIEW.md`, session 2026-09-26 |

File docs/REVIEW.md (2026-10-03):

# Review note: LampNode

## Session 2026-10-01: build plan and design for construction (kit 1.7.0)

On 2026-09-30 Amish approved the build plan format and asked for it across all repos, with outstanding decisions kept in a separate design decisions register, and wrote: "If you are realising that the design cannot be built as per concept - fix the design assumptions to match and be physically feasible as you draw the illustrations." On 2026-10-01 he asked for budgets to be treated as value-engineering targets. This session ran the `/build-plan` work on LampNode. This section is placed at the top to keep this note's newest-first order.

### What was done

- Kit 1.7.0 installed (`.kit/`, `.claude/commands/`); `CLAUDE.md` now matches `.kit/CLAUDE.md`.
- Constructability review of every part with build123d: `cad/src/model.py` rebuilt as `build_components()` with every part as made or bought and fixed to its neighbours, and 80 constructability checks (`python cad/src/model.py --check`), all passing.
- `docs/decisions/0003-design-for-construction.md` (LPN-DDR-003 v0.1, Draft): the eleven changes below, made under Amish's 2026-09-30 instruction to make the design physically buildable; open for his review.
- `bom/bom.csv`: lines 17 (controller boards and fixings) and 18 (head internal plate) added; lines 15 and 16 repriced; specifications updated. `bom/bom-notes.md` updated.
- Calculations rerun: LPN-CAL-001 v0.3 (mass, cost and R16 against the value-engineering target); `docs/04-calcs/results.csv` regenerated. LPN-PRC-001 v0.5 and LPN-REQ-001 v0.5 updated to match.
- STEP and STL regenerated; general arrangement LPN-DWG-001 bumped to Rev P3; concept media regenerated (`media/hero.png`, `exploded.png`, `cutaway.png`, `flow.png`, `concept-blueprint.*`, `model.glb`).
- `cad/src/build_plan_media.py`: overview, eight making sketches (LPN-DWG-101 to 108), two layouts (base drilling, mains board), eight joint close-ups, eleven step pictures and a wiring diagram.
- `docs/05-build-plan.md` (LPN-BLD-001 v0.1) and `docs/06-design-decisions.md` (LPN-DEC-001 v0.1) written; both added to `trl_evidence`; `design_state: constructable` in `project.yaml`; README links and a "Building the prototype" section added.

### Design changes made for construction (LPN-DDR-003)

1. **P1, board stack.** The supply, relay, surge parts and controller board no longer float: an 80 mm mains board on three 12 mm spacers and an 80 mm controller board on three 30 mm standoffs, clamped by three M3 x 45 screws from under the base. Controller board centre 69.4 mm (was 66).
2. **P2, dome fixing.** Three printed bosses with M3 heat-set inserts, three M3 x 30 screws from under the base, a 1 mm EPDM gasket; the dome body is 71 mm on the gasket, so the controller stays 97 mm tall. The mains board is notched for the bosses.
3. **P3, M12 socket.** Moved from the curved side of the bought base to a flat printed pad on the pole side of the dome, between the boards.
4. **P4, light window.** An 8 mm clear rod sealed through an 8.2 mm hole replaces the open 16 mm window.
5. **P5, antenna.** A flexible strip stuck inside the dome wall replaces the rod on the board, matching BOM line 8.
6. **P6, part envelopes.** Supply 23 x 38 x 18 mm (a real 5 W module size); one standing 20 mm varistor with the thermal fuse.
7. **P7, base.** Six holes on a 60 mm circle between the blades, inside the gasket ring, countersunk from below.
8. **P8, sensor head inside.** Box and 15 mm lid; a printed internal plate on the four box bosses carrying the head board and a 25° radar cradle. Radar centre 34.2 mm below the box top (was 30).
9. **P9, ports and gland.** Ports through the lid with nuts inside and plug-in leads; an M16 cable gland on the side wall.
10. **P10, bracket.** A folded 2 mm aluminium channel 110 mm long (the concept block was 130 mm, longer than the box), rubber strips on the flanges, band slots; the bands pass over the arm, through the slots and across the web; four M4 screws with sealing washers into the box top.
11. **P11, cable route.** Level out of the dome, past the luminaire, along the top of the arm with ties; about 0.7 m of the 1 m cordset used.

### Key results

- Value-engineering target: USD 150. Estimated cost of the constructable design: USD 143.00 (USD 7.00 under the target); the concept was USD 130.00. `budget_usd` unchanged.
- Mass: controller 0.33 kg (was 0.34 kg); sensor head with clamps and cable 0.42 kg (was 0.45 kg).
- Requirement status unchanged: 0 not met, 4 at risk (R3, R6, R7, R11), 11 met on paper, by design review or under the value-engineering target, 1 not verifiable at TRL 3 (R1).
- Energy, power, inrush, radar, metering, surge and thermal results unchanged.

### Proposed, awaiting Amish

All open items are in the design decisions register (`docs/06-design-decisions.md`): accept LPN-DDR-003 (recommended); the hand-wired mains board for bench work only (A1, recommended); the M12 socket on the dome and the renders (A2, recommended); the first partner (O1, no recommendation); the port pinout with FieldNode; and the 2026-09-26 appearance-model differences.

### Stale media

The photoreal renders `media/render-*.png`, `media/card.png` and `media/social-preview.png`, and the appearance model `cad/src/product_model.py`, still show the concept: the M12 socket on the base, the solid bracket block and the 16 mm window. They are made on Amish's Mac and were not regenerated here. (The render files referenced by the README are not present in this cloud copy.)

### Safety

The design changes do not touch the fail-on relay, the surge stage or the isolation between the mains and 12 V sides. The build plan keeps the first prototype on the bench: unpowered checks, an insulation check, first power only through an isolating transformer and an RCD with the dome on, dummy loads only, and no street installation of the hand-wired board (safety stops S1 to S7).

### Recommended next step

Amish reviews LPN-DDR-003 and the register. TRL 4 (buying parts, building and testing to the plan) stays on hold.

## Session 2026-09-26: product appearance model and photoreal renders

Amish chose this repo for the first batch of product renders on 2026-09-26. This section is placed at the top to keep this note's newest-first order.

### What was added

`cad/src/product_model.py` exposes `product_parts()` (58 parts: 11 shell, 18 internal, 23 accessory, 6 context), `TITLE` and `RENDER_VIEWS` (hero from the front right looking back along the arm, exploded, and a detail view of the controller alone from the front left). It reuses PARAMS, LV_ANGLES, head_frame() and the reference receptacle from `cad/src/model.py`, in the same local frame; every main dimension and interface (twist-lock base, blades and contacts, gasket, dome, window, M12 socket position, board height, sensor head position and size, radar tilt, port pitch, clamp pitch) is as model.py. It adds:

- Controller base: fillets, grip grooves, a raised orientation mark, tin-plated power blades, gold low-voltage pads, a separate rubber gasket, and a hex M12 panel socket with a knurled plug and overmold.
- Dome: filleted top and foot, a teal accent band, a raised label with print, and a clear window over the light pipe.
- Controller internals in the model.py envelopes: surge carrier with two varistors and the thermal fuse; encapsulated supply with a label; fail-on relay with a label; metering carrier and IC; controller board with the shielded radio module, dimming stage and clock ICs, the supercapacitor with a sleeve band, the antenna, the light pipe and the light sensor.
- Sensor head: filleted housing with a parting line to a 15 mm lid (face down), a dark radar-transparent window on the +X face with a teal accent line, a label, four lid screws, the cable gland on the +Y side, the tilted radar module with patch antennas and front-end IC, the head board and components, two M12 expansion sockets with caps (one teal), a folded bracket with bolts, and two band clamps with rubber liners and worm housings.
- M12 cable along the arm with two cable ties.
- Context (existing street furniture, not in the BOM): a compact LED luminaire head with heat-sink fins and lens, the receptacle from model.py, and a 500 mm section of the lamp arm.

`README.md` now shows `media/render-hero.png` and links `media/render-exploded.png`; the orchestrator produces both files.

### Differences from model.py (Proposed, awaiting Amish)

1. **Luminaire head.** concept_media.py uses a 650 x 320 mm cobra head; the appearance model uses a compact 390 x 250 mm LED head with fins and a neck round the arm, so the 94 mm controller is not lost in the hero render. The receptacle position and height are unchanged. Proposed, awaiting Amish. Recommendation: accept for the product renders only; the concept media and drawing keep the reference head.
2. **M12 cable route.** model.py runs the cable diagonally from the socket face; here it leaves straight through the plug, drops to the arm, and wraps diagonally round to the +Y side before the drop to the head gland, instead of right-angle steps. The socket, gland side and end points are unchanged. Proposed, awaiting Amish. Recommendation: accept; the route is not fixed at TRL 3.
3. **Band clamps.** model.py shows each clamp as one 5 mm by 20 mm ring. The appearance model splits it into a 1.5 mm rubber liner (20 mm wide) and a 1.5 mm stainless band (14 mm wide) with a worm housing, as BOM line 15 describes. The outer radius is 2 mm smaller than the model.py envelope. Proposed, awaiting Amish. Recommendation: accept.
4. **Bracket.** model.py shows a solid 130 x 30 x 15 mm block; the appearance model is a folded channel with saddles under the clamps and four bolts, inside the same envelope. Proposed, awaiting Amish. Recommendation: accept, matching "folded aluminum bracket" on BOM line 15.
5. **Added appearance details.** Grip grooves, orientation mark, accent band and labels, the M12 plug, port caps and cable ties are not separate BOM lines; they fall under BOM lines 1, 2, 10, 14 and 16. No new BOM lines are implied. No lit indicator was added, because the design has none. Proposed, awaiting Amish. Recommendation: accept.
6. **Render groups.** The sensor head, bracket, clamps, plug and cable are in the "accessory" group so the detail view shows the controller alone. Rendering choice only.

### Status

This is an appearance model only: no tolerances, no fabrication detail, nothing past TRL 3. `trl: 3` and `trl_target: 3` are unchanged, and TRL 4 remains on hold. model.py, the BOM and the other documents were not edited.

## Session 2026-09-26: sources strengthened

Amish asked on 2026-09-26 to fix the weaker sources. README changes only; no controlled document changed.

| Where | Old source | New source |
| --- | --- | --- |
| What sparked the idea (Detroit relighting) | The Detroit News, 2016 | [US Department of Energy, Detroit street lighting report](https://www.energy.gov/eere/ssl/articles/detroit-street-lighting-report) and [Michigan Public, 2016](https://www.michiganpublic.org/news/2016-12-16/detroit-celebrates-65-000-new-led-streetlights) |
| What sparked the idea (2019 lawsuit) | WXYZ Detroit, 2019 | [Michigan Public, 2019](https://www.michiganpublic.org/law/2019-05-07/some-of-detroits-new-led-streetlights-are-burning-out-city-sues-manufacturer); the unverified "excessive number of calls" detail was removed, and "40 % dark" became the DOE figure of more than half of 88,000 lights out by mid-2013 |
| Country row: United States | LA Bureau of Street Lighting (link redirects, could not be verified) | Los Angeles figure removed; row now cites [NYC DOT](https://www.nyc.gov/html/dot/html/infrastructure/streetlights.shtml) and [DALI Alliance](https://www.dali-alliance.org/d4i/) |
| Country row: India and South Asia | None | Replaced by India, citing [PIB, 2024](https://www.pib.gov.in/PressReleasePage.aspx?PRID=2040102&reg=48&lang=2) (Street Lighting National Programme) |
| Country row: Sub-Saharan Africa | None | Replaced by Philippines (Quezon City), citing the [World Bank](https://blogs.worldbank.org/en/energy/led-street-lighting-unburdening-our-cities) and its [case study](https://documents.worldbank.org/curated/en/842031477930270833/) |
| Country row: Latin America | None | Replaced by Brazil (Belo Horizonte PPP), citing [ESMAP](https://www.esmap.org/node/57541) |

INSPIRATIONS.md line for LampNode updated to the new sources. No verified source for an African example was found within this session's search budget, so the region table no longer has an African row; worth adding one when a primary source is found.

## Session 2026-09-25: recommendations accepted

On 2026-09-25 Amish wrote: "i accept all your recommendations, go with them across all repos." Every LampNode item with a recommendation is now **decided by Amish, 2026-09-25: go with recommendation**, recorded in `docs/decisions/0002-recommendations-accepted.md` (LPN-DDR-002 v0.1). LPN-DDR-001 moved to v0.2 with the new status on D1 to D10 and O2 to O8.

### Decisions applied and what changed

- **D1 to D10** (socket, radar, head link, LoRaWAN, 0 to 10 V, fail-on relay, hosted power policy, default output, mains range, TALQ in CityTwin): decided. These were already built into the TRL 3 design, so only the status wording changed.
- **O2, R7 shortfall:** option (c). R7 stays at 35 % with the reference profile; the risk is accepted until real traffic counts exist. Numbers unchanged (34.1 to 36.4 %, at risk).
- **O3, R13 at high temperature:** option (a), firmware limits the two ports to 2.5 W in total above 50 °C inside the dome (no 10 W supply). 12 V peak against derated supply: before 3.90 W against 3.55 W at 65 °C (at risk); after 3.40 W against 3.57 W at 64.3 °C, margin 0.17 W (met on paper). R13 restated in LPN-REQ-001 v0.4; limited case added to `docs/04-calcs/sizing.py` and LPN-CAL-001 v0.2 section 11; firmware rule added to LPN-PRC-001 v0.4; drawing note changed, so LPN-DWG-001 moved from Rev P1 to P2 (geometry unchanged). No BOM change.
- **O4 to O7** (TCXO clock, 80 A inrush normally closed relay with zero-cross closing, 385 V varistor with TVS diodes and no gas discharge tube, charge-pump coil drive, two-signal day logic, I/Q radar): confirmed. Already in `bom/bom.csv`; wording updated in `bom/bom-notes.md`, LPN-PRC-001 and LPN-CAL-001. Checks on real parts (driver inrush, surge, fail-on behavior) are TRL 4 work, decided but on hold.
- **O8, 5-pole M12 ports:** confirmed; pinout is a cross-repo action with FieldNode.
- Budget: no recommendation touched it. `budget_usd` stays at 150; BOM $130.00. Pitch and problem unchanged.
- Documents bumped: LPN-DDR-001 v0.2, LPN-REQ-001 v0.4, LPN-PRC-001 v0.4, LPN-PRB-001 v0.4 (status wording), LPN-CAL-001 v0.2. README concept summary, key components and "What sparked the idea" updated. The new inspiration is Detroit: 40 % of its streetlights were dark before the 2014 to 2016 relighting, and in 2019 the city sued over about 20,000 early-failing LED fixtures first noticed through resident calls.
- All generated files re-rendered for the domain change (docs PDFs, LPN-DWG-001, all of `media/`), and model, sheet, media and CAL scripts re-run.

### Requirement status now (LPN-CAL-001 v0.2, Table 6)

0 not met, 4 at risk, 11 met on paper or by design review, 1 not verifiable at TRL 3 (before: 5 at risk, 10 met).

| ID | Status | Key number |
| --- | --- | --- |
| R3 Switch the luminaire | At risk | 72 A inrush per 100 W driver at random closing; about 20 A with zero-cross closing |
| R6 Detect presence | At risk | 36 dB signal to noise at 15 m; rain, trees and clutter need a field trial |
| R7 Save energy | At risk (accepted by Amish) | 34.1 to 36.4 % against 35 % |
| R11 Environment | At risk | 63 to 65 °C inside at 45 °C in sun against 70 °C; IP66 and surge need tests |
| R1 Fit the socket | Not verifiable at TRL 3 | Representative base only |
| R13 Host other sensors | Met on paper (firmware port limit) | 3.40 W peak against 3.57 W at 64 °C |
| R2, R4, R5, R8, R9, R10, R12, R14, R15, R16 | Met on paper or by design review | Unchanged from the TRL 3 session |

### Still awaiting Amish

1. **O1, first partner** (city, utility or campus) and region for co-design. No recommendation was made, so no choice is recorded.

### Cross-repo actions

Recorded here only; no other repo was edited.

- **FieldNode:** agree the 5-pole M12 port pinout (FieldNode O2) and the port supply voltage (FieldNode 3.3, 5 or 12 V at build; LampNode 12 V only).
- **AirStreet and NoiseMap:** mention LampNode 12 V ports as an optional power source, FieldNode solar staying the default (D7). Hosted sensors must accept 2.5 W total on hot days.
- **CityTwin:** add a TALQ bridge to CityTwin scope (D10).

### TRL 4

TRL 4 remains on hold by Amish's instruction. `trl: 3` and `trl_target: 3` unchanged. No part selection against datasheets, bench build, test, firmware beyond the documented rule, or purchasing was started.

## Session 2026-09-25: TRL 3

On 2026-09-25 Amish asked for this batch of repos to go through the usual process with the instruction "you know the drill, nothing gets past TRL 3". He has not reviewed LampNode's TRL 2 items one by one, so every item that carried a recommendation is adopted as recommended for TRL 3 under Amish's 2026-09-25 instruction, open for his review. Nothing is recorded as decided or approved by him. This session ran `/advance-trl3` on that basis and stopped at TRL 3.

### What was done

- `docs/decisions/0001-trl2-review-decisions.md` (LPN-DDR-001 v0.1, status proposed): ten items adopted as recommended for TRL 3 (D1 to D10), open for Amish's review, and eight left open (O1 to O8).
- `docs/04-calcs/01-sizing.md` (LPN-CAL-001 v0.1), `docs/04-calcs/sizing.py` and `docs/04-calcs/results.csv`: night hours and energy, self-consumption, relay inrush and zero-cross closing, 0 to 10 V output, clock drift, radar geometry, signal and Doppler, metering error budget, LoRaWAN airtime and last gasp, surge energy, dome temperature in sun, hosted power, mass and cost, with a status for every requirement (Table 6). The script imports the model, reads the BOM and `project.yaml`, and prints every number the note quotes.
- `cad/src/model.py`: parametric build123d model of the controller (base with three blades and four low-voltage contacts, gasket, dome with window, surge stage, supply, relay, metering, board with supercapacitor, antenna, light pipe, M12 port) and the sensor head (enclosure, tilted radar, board, two ports, band clamps and bracket, cable), with the receptacle and a length of arm as grey reference parts. Exports `cad/step/` and `cad/stl/` for `lampnode-assembly`, `lampnode-controller`, `lampnode-sensor-head` and `lampnode-installed-reference`; the clash check finds none.
- `cad/src/sheets.py` and `cad/drawings/LPN-DWG-001.svg`, `.pdf`, `.png`: general arrangement at Rev P1, 1:5, marked "CONCEPT, NOT FOR FABRICATION" and "PRELIMINARY, NOT FOR FABRICATION". LPN-DWG-001 was free because the concept blueprint is LPN-DWG-010.
- `bom/bom.csv` (16 lines, every line priced with a supplier or supplier type, $130.00 against the $150 budget) and `bom/bom-notes.md`.
- `cad/src/concept_media.py` now builds from the model. All of `media/` was re-rendered (hero, blueprint, cutaway, exploded, flow, `model.glb`, `viewer.html`) and every image checked; temporary `media/_views*` folders deleted. The controller internals were rearranged so the cutaway shows the surge stage and metering.
- LPN-PRB-001, LPN-PRC-001 and LPN-REQ-001 revised to v0.3 (R2, R4, R13 and R15 redefined per D9, D5, D7 and D10). `README.md` (TRL badge, links, TRL 3 summary, key components, safety) and `project.yaml` (`trl: 3`, `trl_target: 3`, evidence list) updated. Pitch, problem and `budget_usd` unchanged. PDFs rebuilt in `docs/pdf/`.

### Requirement status (LPN-CAL-001, Table 6)

0 not met, 5 at risk, 10 met on paper or by design review, 1 not verifiable at TRL 3.

| ID | Status | Key number |
| --- | --- | --- |
| R3 Switch the luminaire | At risk | 72 A inrush per 100 W driver at random closing, 289 A for four; about 20 A with zero-cross closing; a normally closed relay rated 80 A inrush still to be found |
| R6 Detect presence | At risk | Beam covers 7.5 to 47.9 m; 36 dB signal to noise at 15 m; 0.63 s to full; rain, trees and clutter need a field trial |
| R7 Save energy | At risk | 36.4 % with an ideal driver, 34.1 % with the dimmed driver model, target 35 % |
| R11 Environment | At risk | 63 to 65 °C inside at 45 °C in sun against a 70 °C rating; 118 J in the varistor at 5 kA; IP66 and surge need tests |
| R13 Host other sensors | At risk | 3.90 W peak against about 3.55 W from the 5 W supply at 65 °C |
| R1 Fit the socket | Not verifiable at TRL 3 | Representative base only |
| R2, R4, R9, R12, R14, R15 | Met (design review) | 85 to 305 V supply; 2.44 mV dimming steps; 1.32 J stored for a 0.144 J last gasp; toggling coil drive; 25.7 s airtime a day at SF9 |
| R5, R8, R10 | Met on paper | 9.1 s drift in 30 days with the TCXO clock; 1.65 % metering error with a one-point calibration; 0.68 W average |
| R16 Affordable | Met | $130.00 against $150 |

Corrections to TRL 2 numbers: lit hours 4,100 to 4,323 h a year at 40° N; photocell energy 410 to 432 kWh; presence saving about 41 % to 34.1 to 36.4 %; schedule-only saving 27 % to 25.0 %; self-consumption 0.6 to 0.68 W (coil 0.40 W, not 0.24 W); airtime 0.2 s to 267 ms per message and 20 to 25.7 s a day; controller mass 0.25 to 0.34 kg; parts $124 to $130; payback 3 to 7 years to 3.5 to 8.8 years. The TRL 2 plan to calibrate metering "possibly with CalRig" does not work: CalRig is a climate chamber for air sensors; a bench power meter is needed.

Design changes found by the calculations (engineering proposals, in the BOM, awaiting Amish's confirmation): TCXO clock (a plain crystal drifts 160 s in a cold month against 2 min); normally closed relay rated for 80 A inrush, closed at the zero crossing; 385 V class varistor with TVS diodes and no gas discharge tube (the socket has no earth contact); charge-pump coil drive and a day decision that needs both clock and light sensor; I/Q radar to reject rain; 5-pole M12 ports to match FieldNode.

### Decisions recorded (LPN-DDR-001)

*Status update, 2026-09-25: every item below that carries a recommendation is now decided by Amish, 2026-09-25: go with recommendation (LPN-DDR-002). Only the first partner (O1, item 11 at TRL 2) remains proposed, awaiting Amish.*

Adopted as recommended for TRL 3 under Amish's 2026-09-25 instruction, open for his review: D1 ANSI C136.41 socket first, Zhaga Book 18 later; D2 24 GHz Doppler radar, schedule-only as a firmware mode; D3 cable to a head under the arm; D4 LoRaWAN on the STM32WL-class module; D5 0 to 10 V only, D4i if a partner needs it; D6 fail-on normally closed relay; D7 siblings stay on FieldNode solar, LampNode power optional, hosted sensors on cabinet-switched feeders bring storage; D8 ships at photocell-equivalent full output; D9 120 to 277 V now, 347 V and 480 V later; D10 TALQ bridge is CityTwin scope. No budget, pitch or problem change was recommended, so none was made.

### Still awaiting Amish

*Status update, 2026-09-25: every item below that carries a recommendation is now decided by Amish, 2026-09-25: go with recommendation (LPN-DDR-002). Only the first partner (O1, item 11 at TRL 2) remains proposed, awaiting Amish.*

1. **O1, first partner** (city, utility or campus) and region. No recommendation was made.
2. **O2, R7 shortfall.** Options: relax R7 to 30 %; move the reference floor start to 21:00; or keep both and accept the risk until traffic counts exist. Recommendation: keep both and accept the risk. Not applied.
3. **O3, R13 at high temperature.** Options: firmware limits the ports to 2.5 W above 50 °C inside, or a 10 W supply (about +$3). Recommendation: the firmware limit. Not applied.
4. **O4 to O7, engineering proposals** listed above (TCXO clock, relay and zero-cross closing, surge stage, coil drive and day logic, I/Q radar). Applied in the BOM and precis for TRL 3 work, awaiting his confirmation.
5. **O8, 5-pole M12 ports** to match FieldNode; the pinout itself waits on FieldNode O2.

### Cross-repo consistency

- FieldNode (FND-DDR-001): STM32WL-class module, LoRaWAN, 15 min interval and TwinKit first all match. FieldNode uses two M12 5-pin ports; LampNode's 4-pole ports were changed to 5-pole to match (O8). Conflict noted, FieldNode not edited: FieldNode ports carry one of 3.3, 5 or 12 V chosen at build, while LampNode ports carry 12 V only, so a FieldNode-pinout sensor built for 3.3 or 5 V needs its own regulator on a LampNode pole. FieldNode's 100 to 115 mW sensor allowance is far below LampNode's 3 W, so no conflict there.
- TwinKit (TWK REVIEW): 8-channel LoRaWAN gateway; LampNode's 96 messages a day at 267 ms (SF9) are a light load. TwinKit's adaptive data rate proposal suits LampNode too. No conflict.
- CalRig (CLR REVIEW): a climate chamber for air sensors; it cannot calibrate power metering. LampNode no longer cites it.
- CityTwin: D10 puts a TALQ bridge in CityTwin scope, but CityTwin's review does not mention TALQ. Noted here; CityTwin not edited.
- AirStreet and NoiseMap stay on FieldNode solar (D7); NoiseMap's review already notes LampNode power as an option. No other repo was edited.

### Safety concerns

- Mains up to 277 V nominal (305 V maximum) in the receptacle; the socket has no earth contact, so LampNode clamps only line to neutral. The varistor must be thermally protected and fused; a failing varistor is a fire risk on the luminaire top.
- Fail-on behavior depends on the coil drive dropping out when the controller stops, and on each driver giving full output with an open 0 to 10 V line. Both need checking on real parts.
- Relay contacts welded by inrush would leave a lamp burning by day; the day-burner check must report it.
- About 65 °C inside the dome in 45 °C sun leaves little margin for the supercapacitor and the supply.
- Work at height beside traffic; radio compliance for the 24 GHz radar and the sub-GHz module; privacy (motion, speed and direction only).

### Gaps and notes

- Citations: the TRL 2 note flagged no unchecked citations (it left out figures from pages that could not be read). No WebFetch checks were run this session and no figure was added to the README. ANSI C136.2 surge levels and ANSI C136.10 and C136.41 dimensions were not read; the model's base geometry is representative.
- Assumptions only tests can settle: driver inrush and dimmed efficiency, radar false triggers, luminaire top temperature, supply derating, relay release-time spread.
- The kit's cutaway cutter is centered on X = Z = 0. The model's local frame already puts the controller at the origin, so no shift is needed any more; the street-scene hero places the model on the pole with a transform. The metering part (item 6) is small and sits under its callout in the exploded view.
- Existing material beyond TRL 3: `build-log/README.md` (scaffold) is present, untouched and not extended. `electronics/` and `firmware/` are empty. No test, build, purchasing or firmware material was created.

### Recommended next step

TRL 4 is on hold by Amish's instruction; this repo stops at TRL 3. The next step is Amish's review of LPN-DDR-001 (D1 to D10), a choice on O1 to O3 and confirmation of the engineering proposals O4 to O8, plus agreement of the port pinout with FieldNode. For the record only, TRL 4 would need: named parts with datasheets (normally closed relay with its inrush rating, supply with its derating curve, radar module, metering IC); a bench build of the controller on a donor luminaire; a lab test report (TST, `environment: lab`) covering fail-on behavior, zero-cross inrush, metering accuracy against a bench meter, dome temperature under a sun lamp and self-consumption; and build log entries. None of this has been started.

## Session 2026-09-25: /populate to a strong TRL 2

### What was done

- `docs/01-problem.md` (LPN-PRB-001 v0.2): problem with cited facts, users, operating environment, constraints, out of scope, prior work (ANSI C136.41, Zhaga Book 18, D4i, TALQ), open questions; co-design checklist kept.
- `docs/03-requirements.md` (LPN-REQ-001 v0.2): 16 measurable requirements (R1 to R16) with targets, verification and a TRL 2 status column, a reference case and assumptions.
- `docs/02-concept.md` (LPN-PRC-001 v0.2): how it works, 15 numbered components, annual energy, self-consumption, radio airtime, presence geometry, cost and payback, proposed design choices, safety, open questions.
- `cad/src/concept_media.py`: massing model of the twist-lock controller (base, dome, surge stage, power supply, relay, metering, controller board, antenna, light pipe) and the sensor head under the arm (enclosure, radar, board, two ports, clamps, cable), with the luminaire, arm and 7.8 m pole as grey context.
- `media/`: `hero.png` (street scene with the 1.75 m figure and a labeled close-up inset), `concept-blueprint` (PNG, PDF, SVG), `exploded.png` and `cutaway.png` with callouts matching the BOM, `flow.png` (annual energy, estimates), `model.glb` and `viewer.html` (controller, sensor head and luminaire head).
- `bom/bom.csv`: 16 lines with indicative USD prices, numbered to match the exploded view; `bom/bom-notes.md` updated.
- `README.md`: hero image and links line; Concept rationale, Burning platform, Where it could be used (6 industries, 6 regions), What sparked the idea, Concept and Key components expanded; Safety extended.
- `docs/pdf/`: branded PDFs of the three controlled documents.
- `project.yaml` unchanged: the pitch and problem still match the numbers found.

### Key results (estimates, to be checked at TRL 3)

| Quantity | Estimate | Requirement |
| --- | --- | --- |
| Annual energy, 100 W luminaire, photocell | about 410 kWh | |
| Schedule only (50 % from 23:00 to 05:00) | about 300 kWh (about 27 % saving) | |
| Schedule and presence (30 % floor 22:00 to 06:00), controller included | about 243 kWh (about 41 % saving, about 167 kWh per year) | R7 met |
| Controller self-consumption | about 0.6 W (0.8 W used with margin) | R10 met |
| LoRaWAN airtime, 96 status messages per day | about 20 s per day, about 0.02 % | R15 |
| Radar beam center on the ground | about 16.5 m along the street from 7.7 m height at 25° tilt | R6 at risk |
| Parts cost, controller and one sensor head | about $124 (controller about $62, head about $56) | R16 met, $150 budget |
| Payback on parts at $0.10 to $0.25 per kWh | about 3 to 7 years, before labor | |
| Mass | controller about 0.25 kg; head with clamps about 0.45 kg | |

Requirements not met or at risk:

- **R2 not met** for 347 V and 480 V lighting circuits (120 to 277 V only).
- **R4 partly met:** 0 to 10 V only; no DALI-2 D4i in the base design.
- **R6 at risk:** presence detection range and false triggers from 7.7 m are unverified.
- **R13 not met in daytime** on cabinet-switched feeders: hosted sensors lose power when the lamp circuit is off.
- **R15 partly met:** open LoRaWAN and payload, but no TALQ bridge.
- **R8 and R11 unverified:** metering accuracy at low dimmed power, and the surge level.

### Proposed, awaiting Amish

*Status update, 2026-09-25: every item below that carries a recommendation is now decided by Amish, 2026-09-25: go with recommendation (LPN-DDR-002). Only the first partner (O1, item 11 at TRL 2) remains proposed, awaiting Amish.*

1. **Socket.** Options: (a) ANSI C136.41 7-contact; (b) Zhaga Book 18; (c) both from the start. Recommendation: (a) first for retrofits, (b) as a later variant.
2. **Presence sensor.** Options: (a) 24 GHz Doppler radar; (b) PIR; (c) no presence, schedule only. Recommendation: (a), keeping (c) as a firmware mode.
3. **Sensor head link.** Options: (a) cable from the controller to a head under the arm; (b) Zhaga bottom-socket module; (c) solar FieldNode head linked by radio. Recommendation: (a).
4. **Radio.** Options: (a) LoRaWAN on the FieldNode STM32WL-class module; (b) an IEEE 802.15.4 mesh such as Wi-SUN. Recommendation: (a), for portfolio consistency with FieldNode and TwinKit.
5. **Dimming interface.** Options: (a) 0 to 10 V only; (b) 0 to 10 V plus DALI-2 D4i on the auxiliary contacts. Recommendation: (a) now, (b) at TRL 3 if a partner's stock needs it.
6. **Fail-on relay** (normally closed, coil energized in daytime), rather than a latching relay. Recommendation: fail-on, accepting about 0.13 W average coil power.
7. **Hosted sensor power.** LampNode would offer 12 V SELV, 3 W, from the luminaire socket. AirStreet and NoiseMap currently state that they run only on FieldNode solar and never tap pole mains. Options: (a) keep siblings on FieldNode, with LampNode power as an option for them; (b) make LampNode the default host; (c) drop the power ports and host by radio only. Recommendation: (a), and coordinate the wording with those repos rather than changing them here.
8. **Default policy.** Ship with photocell-equivalent full output; the 30 % floor profile is for estimates only. Recommendation: yes, the road owner sets any dimming.
9. **Mains range.** 120 to 277 V now; a 347 V and 480 V variant later. Recommendation: defer until a partner needs it.
10. **Interoperability.** Add a TALQ bridge in TwinKit or CityTwin at TRL 3, or leave it to users. Recommendation: note it as TRL 3 scope for CityTwin.
11. **First partner** (city, utility or campus) and region for co-design.

### Safety concerns

- Mains voltage (up to 277 V AC, 305 V maximum) in the receptacle; surges on long feeders; fire risk from a failed surge stage.
- Work at height beside traffic for fitting and removal.
- A failed controller or bad setting could leave a street dark; fail-on behavior must be checked on each driver model, and light levels stay with the road owner.
- Radio compliance for the 24 GHz radar and sub-GHz LoRa modules.
- Privacy: motion only, no images or audio; check local data protection law.

### Problems and notes

- The kit's `cutaway_parts()` builds its cutter around X = Z = 0, so parts 7.9 m up a pole were missed. `concept_media.py` shifts the parts to the origin before rendering. A kit fix may help other pole-mounted repos (suggestion only; `.kit/` not changed).
- `render_all()` frames the parts it is given, so the street-scene hero is composed separately in `make_hero()`; the cutaway is re-rendered with callouts.
- Sources: pages that could not be read this session (for example a Europe PMC query, which was rate limited, and several US DOE and ESMAP pages that returned errors) were left out. The India, sub-Saharan Africa and Latin America rows in the README carry no cited figures for that reason.
- The legacy `cad/src/model.py` placeholder is untouched (TRL 3 work).

### Recommended next step

Review this note and the media, then decide items 1, 2, 3 and 7. If approved, run `/advance-trl3` to check the energy, radar range, relay inrush, surge and thermal estimates by calculation and produce the parametric model and drawing sheet.

## Session 2026-09-27: kit 1.5.0 and image quality

- Kit 1.5.0 synced: STANDARDS v1.5 (sections 12 to 15: product renders, storefront images and image quality, public release, authorship and signing), `.kit/cards.py`, `.kit/image_qc.py`, `.kit/release_gate.py`, issue templates, and the `/render-product` and `/release` commands. `CLAUDE.md` now matches `.kit/CLAUDE.md`.
- Every `media/render-*.png` recaptioned from its original render with the new layout: the title, concept label and repository sit in a band above the render and the view note in a band below it, each line wrapped to the image width, so no text overlaps other text or the render or runs off the image. `media/card.png` and `media/social-preview.png` regenerated with the same rules.
- `python .kit/image_qc.py` and `python .kit/release_gate.py` pass. trl stays 3.

## Session 2026-10-02: open-decision recommendations approved

Amish, 2026-10-02: "i approve your recommendations for all 555 open decisions." This approves the recommendation for every open decision in the design decisions register. 6 decisions were recorded: each moved to Decisions made, dated 2026-10-02, with the approved recommendation and its record. trl stays 3; no build or test work was done, and the CAD model, BOM quantities and prices, and pictures were not changed.

### Documents changed

- `docs/06-design-decisions.md` (LPN-DEC-001 v0.2): the six open decisions moved to Decisions made; Open decisions now reads none; tables renumbered
- `docs/decisions/0003-design-for-construction.md` (LPN-DDR-003 v0.2): status accepted with Amish's words; A1 accepted on strict bench-only terms, A2 accepted; safety note updated
- `docs/decisions/0001-trl2-review-decisions.md` (LPN-DDR-001 v0.3): O1 (first partner and region) decided
- `docs/decisions/0002-recommendations-accepted.md` (LPN-DDR-002 v0.2): O1 decided; the FieldNode cross-repo action records the pinout LampNode proposes
- `docs/03-requirements.md` (LPN-REQ-001 v0.6): R13 states the pinout proposed to FieldNode; no status changed
- `docs/02-concept.md` (LPN-PRC-001 v0.6): expansion port pinout, first partner and band stated as decided
- `docs/01-problem.md` (LPN-PRB-001 v0.5): first partner and port pinout stated as decided
- `docs/05-build-plan.md` (LPN-BLD-001 v0.2): antenna band set to 915 MHz for the US partner; no design change
- `bom/bom-notes.md`: 915 MHz antenna and US915 band, and the port pinout, noted; no quantity or price changed
- PDFs regenerated with `python3 .kit/render.py`; superseded PDF versions removed by the render.

### Follow-up actions to carry approved decisions into the design

1. Decision 3 (pictures): Update `cad/src/product_model.py`, the photoreal renders, `media/card.png` and `media/social-preview.png` with the M12 socket on the dome pad (on Amish's Mac)
2. Decision 6 (pictures): When the renders are next made, redraw appearance items 2, 3 and 4 (cable route, band clamps, folded bracket with EPDM strips) to the constructable design of P10 and P11; items 1, 5 and 6 stay as render-only details
3. Decision 4 (bom): Change the description of BOM line 8 from "868 or 915 MHz" to a 915 MHz antenna, and set the LoRaWAN module order for US915
4. Decision 4 (calcs): Recheck the time on air and duty limits in LPN-CAL-001 for the US915 band (FCC dwell time of 400 ms per channel) instead of the EU868 duty cycle
5. Decision 5 (drawings): Mark the port pinout (pin 1 supply, pin 3 ground, pins 2 and 4 RS-485, pin 5 wake) on the block-level wiring diagram (build plan Figure 8) and the head board making sketch
6. Decision 5 (docs): Propose the pinout to FieldNode (its O2) in the FieldNode repo; it was not edited from here

### Points found in the review

- The render files referenced by the README are not present in this cloud copy. The appearance model and render scenes were updated later on 2026-10-02 (see "Approved follow-ups carried out" below); the photoreal renders themselves are still to be made on Amish's Mac.

## Session 2026-10-02: approved follow-ups carried out

Amish approved on 2026-10-02 that every follow-up action from the open-decision sign-off be carried out. trl stays 3; no build or test work was done. `budget_usd` is unchanged.

### Follow-ups

1. Done (decision 3, pictures): `cad/src/product_model.py` now shows the M12 socket in the flat pad on the pole side of the dome. The photoreal renders, `media/card.png` and `media/social-preview.png` are not regenerated here: they are made on Amish's Mac next from the exported scenes.
2. Done (decision 6, pictures): the appearance model redraws the cable route (P11), the folded bracket with band slots and rubber strips, and the band clamps through the slots (P10), using the model shapes. Items 1, 5 and 6 of the 2026-09-26 differences stay as render-only details.
3. Done (decision 4, BOM): `bom/bom.csv` line 8 is a 915 MHz antenna and line 7 is ordered for US915; prices unchanged, with the basis given in the notes.
4. Done (decision 4, calculations): LPN-CAL-001 section 9 and `sizing.py` now check the US915 400 ms dwell limit. Result: the 24-byte status message is inside the limit at SF9 (267 ms) or faster and over it at SF10 (494 ms, 94 ms over). The largest payload inside 400 ms is 11 bytes at SF10, 53 at SF9, 125 at SF8 and 242 at SF7. The 6-byte fault message is 330 ms at SF10. The last-gasp energy is unchanged. No requirement status changed.
5. Done (decision 5, drawings): the pin numbers are on the wiring figure (build plan Figure 8, with a pinout panel), in the notes of the lid sketch LPN-DWG-106 (Rev P2) and the head internal plate sketch LPN-DWG-107 (Rev P2), and in the general arrangement notes.
6. Not done here, cross-repo: propose the pinout to FieldNode (see Cross-repo actions).

### Results

- The model needed no change: it already carries the dome-pad socket, the folded bracket and the cable route; all 80 constructability checks still pass. STEP and STL regenerated.
- Cost: Value-engineering target: USD 150. Estimated cost of the constructable design: USD 143.00 (USD 7.00 under the target). Mass unchanged: controller 0.33 kg, head 0.42 kg.
- Requirement status changes: none (0 not met, 4 at risk: R3, R6, R7, R11; 11 met on paper; R1 not verifiable at TRL 3).
- Pictures regenerated: general arrangement LPN-DWG-001 (Rev P4), concept media (hero, exploded, cutaway, flow, concept blueprint, model.glb), wiring figure, and sketches LPN-DWG-106 and 107.
- Appearance model: 64 parts. Render scenes exported to `/home/claude/renders/lampnode` for the views hero, exploded and detail, with `lampnode__jobs.json`.

### Documents changed

- `docs/04-calcs/01-sizing.md` (LPN-CAL-001 v0.4), `docs/03-requirements.md` (LPN-REQ-001 v0.7), `docs/02-concept.md` (LPN-PRC-001 v0.7), `docs/05-build-plan.md` (LPN-BLD-001 v0.3), `bom/bom.csv`, `bom/bom-notes.md`, `docs/04-calcs/sizing.py`, `docs/04-calcs/results.csv`, `cad/src/sheets.py`, `cad/src/build_plan_media.py`, `cad/src/product_model.py`.

### Cross-repo actions

- FieldNode: publish the sensor port pinout (pin 1 supply, pin 3 ground, pins 2 and 4 RS-485, pin 5 wake; hosted sensors accept 5 to 12 V) as its O2 decision. FieldNode was not edited from here.
- Any repo that cites a LoRaWAN band or duty cycle for a US partner should use the US915 400 ms dwell limit; LampNode's status message needs SF9 or faster.

### Recommended next step

Render the three views on Amish's Mac, then run the card script.

## 2026-10-02: photoreal renders redone on the constructable design

Rendered with Blender Cycles on Amish's Mac from the updated appearance model; captioned with `.kit/photo_caption.py`; `media/card.png` and `media/social-preview.png` regenerated with `.kit/cards.py`. Views: hero, exploded, detail. image_qc passes. Appearance deviations are those logged above as proposed, awaiting Amish.

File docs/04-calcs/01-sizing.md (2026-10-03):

---
doc_id: LPN-CAL-001
title: LampNode sizing calculations
project: LampNode
doc_type: Calculation note
version: "0.4"
status: Draft
date: '2026-10-02'
author: Amish Chadha
license: CERN-OHL-S-2.0
revisions:
- version: "0.1"
  date: '2026-09-25'
  author: Amish Chadha
  change: First TRL 3 sizing note (energy, self-consumption, switching and inrush, dimming, clock, radar, metering, radio and last gasp, surge, temperature, hosted power, mass, cost) with a status for every requirement
- version: "0.2"
  date: '2026-09-25'
  author: Amish Chadha
  change: Recommendations accepted by Amish (DDR-002). Firmware port limit (2.5 W above 50 °C inside) added to section 11; R13 now met on paper; engineering changes confirmed
- version: "0.3"
  date: '2026-10-01'
  author: Amish Chadha
  change: Mass and cost updated for the constructable design (LPN-DDR-003); budget reported as a value-engineering target
- version: "0.4"
  date: '2026-10-02'
  author: Amish Chadha
  change: Radio section rechecked for the US915 band decided on 2026-10-02 (400 ms dwell limit per channel instead of the EU868 duty cycle); SF12 row replaced by SF8; no requirement status changed
---

# LampNode sizing calculations

On paper, LampNode meets eleven of its sixteen requirements, and none is clearly not met. Four are **at risk**: R3 (relay inrush), R6 (presence detection), R7 (energy saving) and R11 (environment). R13 (hosted sensor power) moved from at risk to met on paper with the firmware port limit decided by Amish on 2026-09-25 (LPN-DDR-002). R1 (socket fit and a 5 min change at height) cannot be verified until a base is tried on a real receptacle.

The largest correction to TRL 2 is the energy saving. Integrating the reference profile over real night lengths at 40° N gives **34.1 to 36.4 %**, not about 41 %, against the 35 % target of R7. The TRL 2 estimate assumed every night had 8 dimmed hours and 3.2 h at full output; in fact the dimmed window 22:00 to 06:00 averages 7.52 h a night, summer nights are shorter than it, and the photocell baseline runs 4,323 h a year, not 4,100 h. The calculations also found three design changes, now in `bom/bom.csv` and decided by Amish on 2026-09-25 (LPN-DDR-002): a temperature-compensated (TCXO) real-time clock, since an ordinary 32 kHz crystal drifts 160 s in a cold month against the 2 min limit of R5; a normally closed relay rated for 80 A inrush and closed at the voltage zero crossing; and a 385 V class surge stage without a gas discharge tube, because the twist-lock socket has no earth contact.

Every number here is printed by `docs/04-calcs/sizing.py` (run from the repo root: `python docs/04-calcs/sizing.py`), which also writes `docs/04-calcs/results.csv`. The script reads geometry and part volumes from `cad/src/model.py`, costs from `bom/bom.csv` and the budget from `project.yaml`. All values are first-principles estimates with typical part values; nothing is measured and no part has been chosen from a datasheet.

## 1. Assumptions

*Table 1. Inputs. All are assumptions for a paper design.*

| Input | Value | Basis |
| --- | --- | --- |
| Reference luminaire | 100 W LED cobra head, 0 to 10 V driver, arm at 7.80 m | LPN-REQ-001 reference case |
| Location and switching | 40° N; lamp on from sunset to sunrise (sun center at -0.833°); clock in local solar time | Mid-latitude city; photocells switch within minutes of sunset |
| Reference dimming profile | Full to 22:00, 30 % floor from 22:00 to 06:00 with full output 15 % of that time, full from 06:00 to dawn | LPN-REQ-001 assumptions (for estimates only; the road owner sets any profile) |
| Driver when dimmed | Ideal (input proportional to light), or input = 6 % of rated + 94 % x light level | Typical drivers lose efficiency when dimmed |
| 12 V loads | Controller, clock, accelerometer and light sensor 0.05 W; metering 0.05 W; relay coil 0.40 W by day only; radar 0.20 W and head board 0.03 W by night only | Typical parts |
| Power supply | 5 W module, 0.10 W no-load input, 72 % incremental efficiency at light load, 80 % near full load; full output to 50 °C, falling linearly to 60 % at 70 °C | Typical encapsulated 5 W modules |
| Hosted sensors | 3 W total on two ports, limited to 2.5 W above 50 °C inside; 0.40 W radio transmit transient | LPN-REQ-001 R13, LPN-DDR-002 |
| Driver inrush | 60 A cold-start peak at 230 V for a typical 100 W outdoor driver, 47 µF bulk capacitor | Typical driver datasheets; no driver chosen |
| Radar | 24.125 GHz; 8 dBm, 11 dBi each way; half-power elevation half-width 17°; walking person 0.5 m²; 35 dB effective noise figure at low Doppler, 10 Hz bins, 15 dB detection threshold | Typical low-cost K-band modules |
| Tariff | $0.10 to $0.25 per kWh | Typical public lighting rates |

## 2. Energy (R7)

At 40° N the lamp is lit **4,323 h a year** (11.84 h a night on average, from 8.99 h at midsummer to 14.68 h at midwinter). The 100 W lamp then uses **432 kWh a year** under a photocell.

*Table 2. Annual energy for one 100 W luminaire.*

| Case | Energy per year | Saving |
| --- | --- | --- |
| Photocell, full power | 432 kWh | |
| Schedule only (50 % from 23:00 to 05:00) | 324 kWh | 25.0 % |
| Reference presence profile, ideal driver, with 5.9 kWh of controller use | 275 kWh | **36.4 %** |
| Same, dimmed driver model | 285 kWh | **34.1 %** |

The dimmed window covers 2,745 h a year, 7.52 h a night on average. With an ideal driver R7 is met with 1.4 points to spare; with the dimmed driver model it is missed by 0.9 points. **R7 is at risk.** Amish decided on 2026-09-25 to keep the 35 % target and the reference profile and accept this risk until real traffic counts exist (LPN-DDR-002, from LPN-DDR-001 O2). The TRL 2 method, applied to the same inputs, reproduces its own 236 kWh, so the difference comes from the night lengths and not from an arithmetic slip. The energy saved is **148 kWh a year** with the dimmed driver model.

The presence assumption matters more than the driver. An isolated pedestrian keeps the lamp at full for about 70 s (8.6 s from detection at 15 m to the pole, a 60 s hold and 1 s of ramps), so the 15 % boost equals about 7.8 isolated passes an hour. With random arrivals and the dimmed driver model, the saving is 40.4 % with no traffic, 37.3 % at 4 events an hour, 34.4 % at 8, 29.3 % at 16 and 22.0 % at 30. At 60° N the lamp runs 4,277 h and uses 428 kWh, and the saving falls to 31.8 %, because long winter evenings before 22:00 stay at full output.

## 3. Self-consumption and supply loading (R10, R13)

The lamp is lit for 0.493 of the year. The relay coil averages 0.203 W, the radar and head board 0.113 W, and the 12 V side 0.416 W in all. The shunt adds 0.8 mW. From the mains LampNode draws **0.68 W** on average, against 1.0 W: R10 is met. The TRL 2 figure (about 0.6 W) used a 0.24 W coil; a typical 16 A relay coil is 0.40 W.

With both hosted ports at 3 W the 12 V side carries 3.50 W by day (coil on) and 3.33 W at night (radar on), or **3.90 W** at peak with a radio transmission: 78 % of the 5 W rating at 25 to 50 °C. Section 11 shows the problem at high temperature and the firmware port limit that solves it.

## 4. Switching and inrush (R3)

The steady current at 400 W, 100 V and PF 0.90 is 4.44 A (0.93 A for the reference lamp at 120 V), well inside a 16 A contact. The problem is inrush. A typical 100 W outdoor driver takes about 72 A for a few hundred microseconds when switched at a random point of the 277 V wave, and four such drivers on one relay would take about 289 A. Relays made for LED loads are rated for about 80 A inrush, and most are normally open; a normally closed contact with that rating must be found.

Closing at the voltage zero crossing cuts the inrush sharply. The metering IC gives the zero crossing; the relay release time is learned and the coil released early by that amount. With a 0.5 ms timing error the peak falls to about 17 A at 50 Hz and 20 A at 60 Hz for one driver. Contact life is not a concern: two switchings a day for 20 years are 14,600 cycles against 100,000. **R3 is at risk** until a normally closed relay with an 80 A or better inrush rating is found and the partner's driver inrush is known; 400 W from several drivers needs zero-cross closing.

## 5. Dimming output (R4)

A 12-bit PWM filtered to 0 to 10 V gives 2.44 mV steps against the 100 mV needed for 1 % steps. A 10 mA sink serves 5 drivers at 2 mA of control current, the high end for 0 to 10 V drivers, and dissipates at most 0.10 W. R4 is met by design review for 0 to 10 V; DALI-2 D4i is a later variant (LPN-DDR-001 item 5).

## 6. Clock without the network (R5)

A 32 kHz tuning-fork crystal (±20 ppm, falling 0.034 ppm/K² away from 25 °C) drifts 52 s in 30 days at 25 °C, **160 s at -10 °C** and 318 s at -30 °C (230 s at 70 °C). The 2 min limit of R5 is therefore not met in a cold month. A TCXO real-time clock (±3.5 ppm from -40 to 85 °C) drifts at most **9.1 s** in 30 days. The TCXO clock is now in `bom/bom.csv` line 7 (+$3), so R5 is met on paper; the change was decided by Amish on 2026-09-25 (LPN-DDR-002). When the network is up, the controller also sets its clock from the LoRaWAN network time.

## 7. Presence detection (R6)

**Geometry.** The model puts the radar 7.72 m above the road; tilted 25° down, its beam center reaches the road 16.6 m along the street. A pedestrian (target center 1.0 m up) at 15 m is 24.1° below horizontal and a car or cyclist (0.7 m) at 25 m is 15.7° below, both inside the half-power beam, which covers a walking person from 7.5 to 47.9 m along the street.

**Signal.** A walking person at 15 m is 16.4 m from the radar in a straight line. With the Table 1 values the echo is -93 dBm against a -129 dBm noise floor: **36 dB** of signal to noise. The 15 dB threshold is reached at 56 m on the beam axis, or 40 m at the beam edge. Range is therefore not limited by signal strength.

**Motion and clutter.** An approaching pedestrian at 1.4 m/s gives a 205 Hz Doppler tone, a cyclist at 5 m/s 774 Hz and a car at 50 km/h 2,151 Hz. Falling rain gives 136 Hz (drizzle, 2 m/s) to 476 Hz (heavy rain, 7 m/s), which overlaps walkers and cyclists. Because the beam points down, rain always moves away from the radar, while people coming toward the lamp move toward it, so a radar with I/Q (direction) output can ignore receding targets. `bom/bom.csv` line 12 now calls for I/Q output. Trees moving in wind produce echoes in both directions and cannot be rejected by direction alone.

**Timing.** Two 128 ms detection frames, the serial link, the 0 to 10 V output and a 0.3 s driver response give **0.63 s** to full output, inside 1 s. A pedestrian detected at 15 m reaches the pole 10.7 s later.

**R6 is at risk.** The signal budget and timing are met, but rain, wind-blown trees and the real radar cross-section of a person at this angle can only be settled in the field.

## 8. Metering (R8)

The current ranges from 66 mA (10 W at 305 V and PF 0.5) to 4.44 A (400 W at 100 V). A 2 mΩ shunt gives 0.131 mV at the low end, 169 times below the metering IC's full scale and inside its 1000:1 range; it dissipates 0.040 W at 4.44 A.

*Table 3. Active power error budget (percent of reading).*

| Term | Error |
| --- | --- |
| Metering IC over 1000:1 | 0.50 |
| Shunt temperature coefficient, 50 ppm/K over 50 K | 0.25 |
| Voltage divider temperature coefficient | 0.10 |
| Phase error of 0.1° at PF 0.5 | 0.30 |
| Bench reference used for a one-point calibration | 0.50 |
| **Worst-case sum (RSS 0.81)** | **1.65** |

With a one-point calibration at build the worst case is 1.65 %, inside ±2 %. Without it (1 % shunt and 0.2 % divider tolerances) the worst case is 2.35 %. **R8 is met on paper, provided each unit is calibrated once** against a bench power meter. CalRig, which the TRL 2 note suggested, is a climate chamber for air sensors and cannot do this.

## 9. Radio, faults and last gasp (R9, R15)

*Table 4. Time on air of a 24-byte status message (13 bytes of LoRaWAN overhead, 125 kHz, coding rate 4/5).*

| Spreading factor (US915 data rate) | Per message | 96 per day | Inside 400 ms dwell limit |
| --- | --- | --- | --- |
| SF7 (DR3) | 82 ms | 7.9 s | Yes |
| SF8 (DR2) | 144 ms | 13.8 s | Yes |
| SF9 (DR1) | 267 ms | 25.7 s | Yes |
| SF10 (DR0) | 494 ms | 47.4 s | **No**, 94 ms over |

The first partner is a US partner on the 915 MHz band (decided 2026-10-02), so the radio limits are those of the US915 plan, not the EU868 1 % duty cycle that this note used before. US915 has no duty cycle, but the FCC limits a transmission to 400 ms on one channel. The largest message that fits inside 400 ms is 11 bytes at SF10 (DR0), 53 bytes at SF9 (DR1), 125 bytes at SF8 and 242 bytes at SF7. The 24-byte status message therefore has to go at SF9 (DR1) or faster, where it takes 267 ms and 25.7 s of airtime a day (TRL 2 gave about 0.2 s and 20 s a day before the full 13 bytes of LoRaWAN overhead were counted). A lamp that can only reach its gateway at SF10 (DR0) cannot send the 24-byte status in one message: it would have to send a status of 11 bytes or fewer, or be given a closer gateway. The 6-byte fault message fits at every rate (330 ms at SF10). SF11 and SF12 do not exist at 125 kHz in US915. On a public network with a 30 s daily fair-use limit, lamps at SF10 or slower need a longer interval, as FieldNode found; on a private TwinKit gateway only the dwell limit applies. A 6-byte fault message takes 185 ms at SF9.

For the last message after mains loss, one transmission at SF10 and 22 dBm with two receive windows needs about 0.144 J. A 0.22 F supercapacitor discharged from 5.0 to 3.6 V gives 1.32 J, a margin of 9 times, and recharges in 55 s at 20 mA. R9 is met by design review. R15 is met by design review with the TALQ bridge moved to CityTwin (LPN-DDR-001 item 10).

## 10. Surge (R11)

The twist-lock socket has no earth contact, so LampNode can clamp only line to neutral; common-mode surges are the luminaire's job. A gas discharge tube to earth, as listed at TRL 2, has nowhere to connect and is dropped. An 8/20 µs surge carries 23.5 µs of charge per ampere of peak current. At 5 kA a 385 V class metal oxide varistor clamping at about 1,000 V absorbs **118 J**, within a 20 mm disc's single-surge rating; at 10 kA it absorbs 271 J, which is beyond it. The 320 V class chosen at TRL 2 has only 5 % of margin over the 305 V maximum line voltage; the 385 V class has 26 %. The surge level required by ANSI C136.2 was not read this session and stays to be confirmed. The surge part of R11 is not verifiable without tests.

## 11. Temperature in the sun (R11, R13)

At 45 °C ambient, with the sun 60° above the horizon, the dome and base present 99 cm² to the sun and absorb 3.46 W at an absorptance of 0.35. Their 338 cm² surface loses heat at 12.4 W/(m² K) in still air. With 0.79 W dissipated inside by day, and the luminaire top 20 K above ambient under the base, the shell rises 13.3 K; allowing 5 K from shell to parts, the inside reaches **63 °C** with the ports unloaded and **65 °C** with 3 W on the ports. That is inside the 70 °C rating, with little margin for a dark dome or a hotter luminaire. **R11 is at risk** (temperature margin, surge and IP66 all unverified).

At 65 °C the derated supply gives about 3.55 W, against the 3.90 W peak with both ports at 3 W, so without a limit R13 would be at risk at the hot end. Amish decided on 2026-09-25 (LPN-DDR-002, from LPN-DDR-001 O3) that the firmware limits the two ports to 2.5 W in total whenever the interior is above 50 °C, rather than fitting a 10 W supply. With the limit, the internal dissipation falls slightly and the interior reaches 64.3 °C; the derated supply gives 3.57 W against a 3.40 W peak, a margin of 0.17 W. **R13 is met on paper** with the firmware port limit. Hosted sensors must tolerate the lower allowance on hot days. The voltage drop is not a problem: one port at 3 W over 10 m of 0.34 mm² cable loses 0.25 V (2.1 %), and the 1 m cable to the head, at 0.27 A, loses 0.027 V.

## 12. Mass

*Table 5. Mass estimate for the constructable design (LPN-DDR-003).*

| Assembly | Mass | Basis |
| --- | --- | --- |
| Controller | 0.33 kg | Dome from the model volume in ASA (0.077 kg), base at 35 % of its solid envelope in PC plus brass blades (0.092 kg), mains board, spacers, standoffs and screws (0.033 kg), estimates for the parts inside |
| Sensor head with clamps and 1 m cable | 0.42 kg | Box and lid from the model volume in PC (0.156 kg); folded aluminium bracket, rubber strips and two band clamps (0.084 kg); printed internal plate at 60 % infill (0.018 kg); estimates for the rest |

TRL 2 gave 0.25 kg for the controller; the concept model gave 0.34 kg and 0.45 kg. The constructable design is a little lighter because the solid bracket block of the concept became a folded 2 mm channel and the power supply envelope is a real 5 W module size. No requirement sets a mass.

## 13. Cost (R16)

Value-engineering target: USD 150 (`budget_usd`, a hypothetical control target, not a limit). Estimated cost of the constructable design: USD 143.00 (USD 7.00 under the target). `bom/bom.csv` has 18 lines, all priced: USD 75.00 for the controller (items 1 to 9 and 17), USD 61.00 for the sensor head, cable and ports (items 10 to 15 and 18) and USD 7.00 of hardware. Making the design constructable added line 17, the controller boards and fixings (USD 7.00), and line 18, the printed head plate (USD 4.00), and repriced line 15, the folded bracket (USD 6.00 to 7.00), and line 16, sealing washers and cable ties (USD 6.00 to 7.00); the total rose from USD 130.00. At 148 kWh a year the parts pay back in 3.9 years at USD 0.25 per kWh and 9.7 years at USD 0.10 per kWh, before installation labor.

## 14. Results

*Table 6. Requirement status at TRL 3.*

| ID | Requirement | Result | Status |
| --- | --- | --- | --- |
| R1 | Fit the socket | Representative ANSI C136.41 base in the model; fit and a 5 min change cannot be checked on paper | Not verifiable at TRL 3 |
| R2 | Mains supply range | Supply 85 to 305 V; 385 V class varistor; scope 120 to 277 V (LPN-DDR-001 item 9) | Met (design review) |
| R3 | Switch the luminaire | 4.44 A steady at 400 W; inrush 72 A per 100 W driver, 289 A for four; about 20 A with zero-cross closing | **At risk** |
| R4 | Dim the luminaire | 2.44 mV steps; 10 mA sink serves 5 drivers | Met (design review) |
| R5 | Schedule without the network | Crystal 160 s at -10 °C and 318 s at -30 °C in 30 days; TCXO clock 9.1 s | Met on paper with the TCXO clock |
| R6 | Detect presence | Beam covers 7.5 to 47.9 m; 36 dB at 15 m; 0.63 s to full; rain, trees and cross-section unverified | **At risk** |
| R7 | Save energy | 36.4 % ideal driver, 34.1 % dimmed driver model, target 35 % | **At risk** |
| R8 | Measure energy | 1.65 % worst case with a one-point calibration (2.35 % without) | Met on paper, calibration required |
| R9 | Report faults | 0.144 J last gasp against 1.32 J stored | Met (design review) |
| R10 | Low self-consumption | 0.68 W average | Met on paper |
| R11 | Survive the environment | Inside 63 to 65 °C at 45 °C in sun (70 °C rating); 118 J in the varistor at 5 kA; IP66 and surge need tests | **At risk** |
| R12 | Fail safe | Normally closed relay; open 0 to 10 V line gives full output; coil drive needs a toggling signal; day needs both clock and light sensor | Met (design review) |
| R13 | Host other sensors | 0.25 V drop at 10 m; ports limited to 2.5 W above 50 °C inside: 3.40 W peak against 3.57 W at 64 °C (3.90 W against 3.55 W without the limit) | Met on paper (firmware port limit) |
| R14 | Privacy | Doppler radar, no image; presence counts only | Met (design review) |
| R15 | Secure and open | LoRaWAN 1.0.4, US915, published payload; 25.7 s a day at SF9, inside the 400 ms dwell limit; TALQ in CityTwin | Met (design review) |
| R16 | Affordable | USD 143.00 against the USD 150 value-engineering target | Under the target by USD 7.00 |

Summary: 0 not met, 4 at risk, 11 met on paper or by design review, 1 not verifiable at TRL 3.

## 15. Limits of this note

- No part is chosen. Every load, inrush, efficiency and derating figure is typical, and each must be replaced by datasheet values before TRL 4.
- The radar model says nothing about false triggers from trees, rain intensity or traffic. Only a field trial can settle R6.
- The thermal model is a single node with a fixed film coefficient; the luminaire top temperature is assumed.
- The energy results depend on the reference profile, which is an estimate only. LampNode ships with photocell-equivalent output (LPN-DDR-001 item 8); the road owner sets any dimming.

> **Safety:** LampNode connects to mains voltage (up to 277 V AC nominal, 305 V maximum) and is installed at height beside traffic. The fail-on behavior in R12 depends on the coil drive dropping out when the controller stops, and on each driver model giving full output with an open 0 to 10 V line; both must be checked on real parts. Relay contacts welded by inrush would leave a lamp burning in daylight, not dark, but the fault must still be reported. Only qualified electricians may fit or remove the controller.

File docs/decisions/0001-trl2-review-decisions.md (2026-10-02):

---
doc_id: LPN-DDR-001
title: LampNode TRL 2 review decisions
project: LampNode
doc_type: Design decision record
version: "0.3"
status: Draft
date: '2026-10-02'
author: Amish Chadha
license: CERN-OHL-S-2.0
revisions:
- version: "0.1"
  date: '2026-09-25'
  author: Amish Chadha
  change: Record the TRL 2 review recommendations adopted for TRL 3 work under Amish's 2026-09-25 instruction, open for his review, and the items that remain open
- version: "0.2"
  date: '2026-09-25'
  author: Amish Chadha
  change: Recommendations accepted by Amish (DDR-002)
- version: "0.3"
  date: '2026-10-02'
  author: Amish Chadha
  change: 'O1 (first partner and region) decided by Amish on 2026-10-02'
---

# 0001: TRL 2 review decisions

- **Date:** 2026-09-25
- **Status:** D1 to D10 and O2 to O8 decided by Amish, 2026-09-25: go with recommendation (see LPN-DDR-002). O1 had no recommendation; it was decided by Amish on 2026-10-02 as recommended in LPN-DEC-001.

## Context

The TRL 2 review note (`docs/REVIEW.md`, session of 2026-09-25) listed eleven LampNode design questions as "Proposed, awaiting Amish", ten of them with a recommendation. On 2026-09-25 Amish asked for this batch of repos to be taken through the usual process with the instruction "you know the drill, nothing gets past TRL 3". He has not reviewed the LampNode items one by one. Under that instruction, every item that carried a recommendation is adopted as recommended for TRL 3, open for his review. Items without a recommendation stay open. Later on 2026-09-25 Amish wrote "i accept all your recommendations, go with them across all repos", so every item below that carries a recommendation is now decided by Amish (LPN-DDR-002). TRL 4 is on hold by his instruction.

## Options considered

The options for each item are in `docs/REVIEW.md` (TRL 2 session) and LPN-PRC-001 v0.2. They are not repeated here.
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

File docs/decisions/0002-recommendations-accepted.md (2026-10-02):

---
doc_id: LPN-DDR-002
title: LampNode recommendations accepted
project: LampNode
doc_type: Design decision record
version: "0.2"
status: Draft
date: '2026-10-02'
author: Amish Chadha
license: CERN-OHL-S-2.0
revisions:
- version: "0.1"
  date: '2026-09-25'
  author: Amish Chadha
  change: Record Amish's acceptance of all recommendations in LPN-DDR-001 and docs/REVIEW.md, what changed in the repo, and the items still open
- version: "0.2"
  date: '2026-10-02'
  author: Amish Chadha
  change: 'O1 (first partner) decided and the pinout to propose to FieldNode recorded, 2026-10-02'
---

# 0002: Recommendations accepted

- **Date:** 2026-09-25
- **Status:** accepted. Every item with a recommendation is decided by Amish; one item without a recommendation stays open.
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

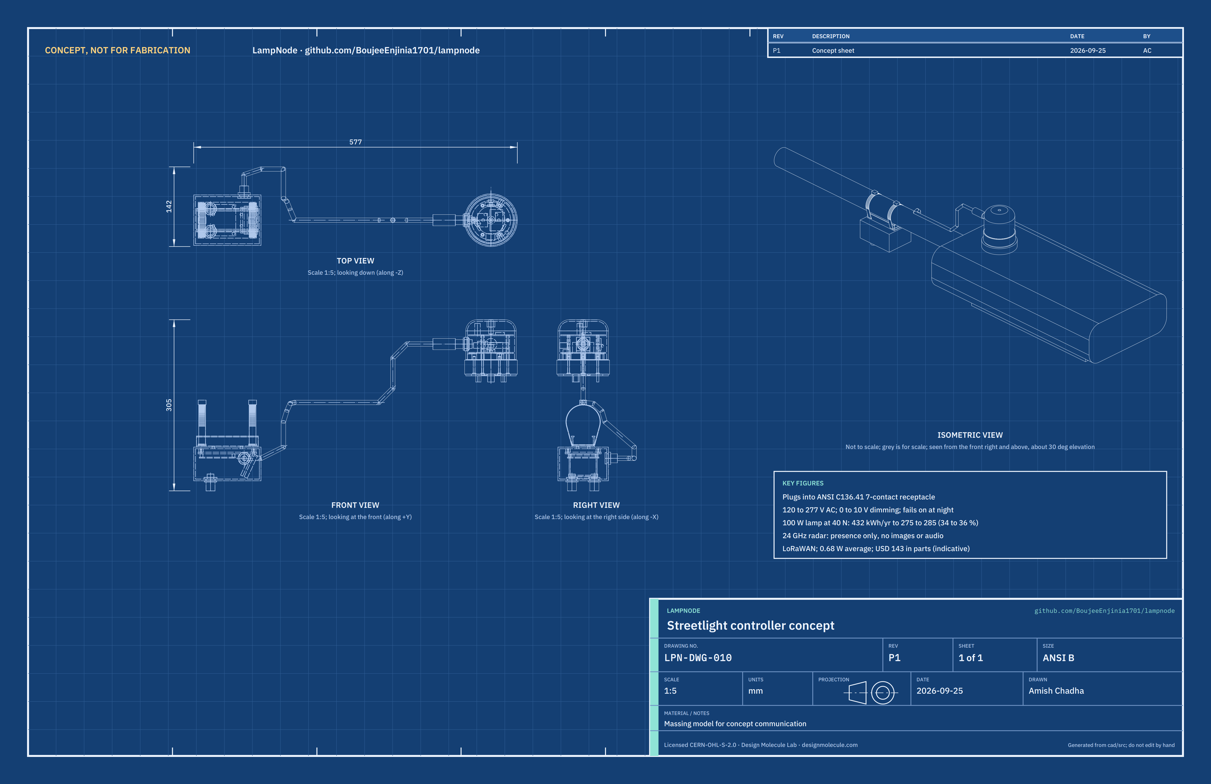
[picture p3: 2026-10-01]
media/concept-blueprint.png

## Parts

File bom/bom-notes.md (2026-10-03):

# BOM notes

- Item numbers match the callouts in `media/exploded.png` and `media/cutaway.png`. Item 16 has no callout. Item 6 (metering) is small and sits under its callout in the exploded view.
- All costs are indicative USD prices for single prototype quantities, with a supplier or supplier type on every line. No supplier quotes have been obtained; replace them before any purchase decision.
- Total for the constructable design: **USD 143.00** for 18 lines: controller (items 1 to 9 and 17) USD 75.00, sensor head, cable and ports (items 10 to 15 and 18) USD 61.00, hardware (item 16) USD 7.00. Value-engineering target: USD 150 (`budget_usd` in `project.yaml`, a hypothetical control target, not a limit, unchanged); the estimate is USD 7.00 under it. `docs/04-calcs/sizing.py` reads this file and checks the total (LPN-CAL-001 section 13).
- Changes for construction (LPN-DDR-003, from USD 130.00): line 17 controller boards and fixings added (USD 7.00), line 18 printed head internal plate added (USD 4.00), line 15 folded bracket with band slots and rubber strips (USD 6.00 to 7.00), line 16 sealing washers and cable ties (USD 6.00 to 7.00). Specifications of lines 1 to 4, 6 to 11 and 13 now match the model. Items 17 and 18 have callouts in the exploded view.
- Changes from TRL 2 ($124): TCXO real-time clock and charge-pump relay coil drive in line 7 (+$3); normally closed relay rated for 80 A inrush in line 5 (+$2); 385 V class varistor with TVS diodes and no gas discharge tube in line 3 (+$1), because the twist-lock socket has no earth contact. The M12 connectors in lines 10 and 14 are now 5-pole to match FieldNode (same price); the radar in line 12 now needs I/Q output (same price). These engineering changes from LPN-CAL-001 were decided by Amish on 2026-09-25 (LPN-DDR-001 O4 to O8, LPN-DDR-002). The firmware port limit decided under O3 needs no BOM change.
- The luminaire, its receptacle, the arm and the pole are existing street furniture and are not costed.
- Installation labor (bucket truck, electrician, traffic management) is not included.
- Metering is indicative, not revenue grade; each unit needs a one-point calibration against a bench power meter (R8).
- Decisions of 2026-10-02 (LPN-DEC-001): the first partner is in the US, so line 8 is the 915 MHz antenna and the LoRaWAN module is set up for the US915 band. The expansion port leads (line 14) are to be wired to the pinout proposed to FieldNode: pin 1 supply, pin 3 ground, pins 2 and 4 RS-485, pin 5 wake. No quantity or price was changed. Basis of the line 8 price: a 915 MHz flexible strip antenna at the usual indicative figure for a stick-on part; basis of the line 7 price: the US915 variant of the same STM32WL-class module, at the same indicative figure.

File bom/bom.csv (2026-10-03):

item | qty | spec | supplier | unit_cost_usd | make_buy | notes
1 Twist-lock base | 1 | ANSI C136.41 7-contact photocontrol base: three power blades, four low-voltage contact pads (dimming +, dimming -, two auxiliary), gasket; drilled through for six M3 countersunk screws on a 60 mm circle between the blades | Photocontrol component supplier (twist-lock base kits sold to controller makers) | 10.00 | buy | Indicative price; socket adopted for TRL 3 (LPN-DDR-001 item 1); dimensions to be checked against ANSI C136.10 and C136.41; drilled for the dome and board-stack screws (LPN-DDR-003)
2 Dome cover | 1 | UV-stabilized ASA dome, 90 mm diameter, 71 mm tall on a 1 mm gasket, 3 mm wall; three screw bosses with M3 heat-set inserts; flat pad 24 x 24 x 6 mm for the M12 socket; 8.2 mm hole and sleeve for the light pipe; printed for the prototype | Local 3D printing service | 4.00 | make | Indicative material cost; molded or bought housing later; bosses, pad and light-pipe sleeve added for construction (LPN-DDR-003)
3 Surge protection and fuse | 1 | Thermal fuse, thermally protected 20 mm class MOV line to neutral (385 V class, about 1,000 V clamp at 5 kA), standing on the mains board; TVS diodes on the dimming and auxiliary leads; no earth contact on the socket | Electronics distributor (for example Digi-Key or Mouser) | 5.00 | buy | Indicative price; was 320 V MOVs and a GDT at TRL 2; 10 kV / 5 kA target (LPN-CAL-001 section 9)
4 Isolated power supply | 1 | PCB-mount encapsulated AC/DC module about 23 x 38 x 18 mm, 85 to 305 V AC in, 12 V 5 W out, reinforced isolation, no-load input 0.1 W or less | Electronics distributor (for example Digi-Key or Mouser) | 8.00 | buy | Indicative price; derating above about 50 C puts R13 at risk (LPN-CAL-001 section 10)
5 Fail-on relay | 1 | Normally closed (form B) power relay about 18 x 24 x 20 mm, 16 A, 277 V AC, 12 V coil about 0.4 W, rated 80 A inrush or better; closed at the voltage zero crossing | Electronics distributor (for example Digi-Key or Mouser) | 6.00 | buy | Indicative price; was $4 for a general-purpose relay; inrush rating per driver model to be confirmed (R3)
6 Energy metering | 1 | Single-phase metering IC (1000:1 dynamic range class), 2 mOhm shunt, 0.1 % voltage divider, digital isolator; bought as a module about 16 x 12 mm for the prototype | Electronics distributor (for example Digi-Key or Mouser) | 5.00 | buy | Indicative price; indicative metering only; not revenue grade; one-point calibration at build (R8)
7 Controller and LoRaWAN radio | 1 | STM32WL-class LoRaWAN module (as FieldNode) ordered for the US915 band (902 to 928 MHz, 915 MHz antenna matching), TCXO real-time clock (3.5 ppm), 3-axis accelerometer, isolated 0 to 10 V output stage, charge-pump relay coil drive, 0.22 F 5.5 V supercapacitor, on an 80 mm round board (plated-hole prototype board for the prototype, 2-layer PCB later) | Electronics distributor and PCB service (for example JLCPCB) | 25.00 | buy | Indicative price (module about $10; PCB and parts about $15); was $22 before the TCXO clock and coil drive (R5 and R12); price unchanged for the US915 variant of the same module (indicative)
8 Antenna | 1 | 915 MHz (US915 band) flexible PCB antenna about 70 x 10 mm with adhesive back and u.FL lead, stuck inside the dome wall | Electronics distributor (for example Digi-Key or Mouser) | 3.00 | buy | Indicative price; basis: a 915 MHz flexible strip antenna at the usual indicative figure for a stick-on part; band set by the US partner decision of 2026-10-02 (LPN-DEC-001)
9 Light sensor and pipe | 1 | Ambient light sensor IC; 8 mm clear acrylic rod about 26 mm long as the light pipe, sealed into the dome top | Electronics distributor (for example Digi-Key or Mouser) | 2.00 | buy | Indicative price
10 M12 port and cable | 1 | 5-pole A-coded M12 panel socket (M16 thread, front mounting, for walls up to 6 mm) in the dome pad, and 1 m UV-rated single-ended M12 cordset to the sensor head | Industrial connector supplier (for example an M12 cordset maker's distributor) | 10.00 | buy | Indicative price; 5-pole to match FieldNode (FND-DDR-001 D5)
11 Sensor head enclosure | 1 | IP66 polycarbonate box 120 x 90 x 60 mm with a 15 mm deep lid, four moulded internal bosses and a radar-transparent end wall; one M16 nylon cable gland; drilled for the gland, four bracket screws and two ports in the lid | Electronics distributor (for example Digi-Key or Mouser) | 6.00 | buy | Indicative price
12 24 GHz radar presence sensor | 1 | 24 GHz Doppler radar module with I/Q (direction) output, about 34 degree elevation beam, motion and speed only | Sensor distributor | 18.00 | buy | Indicative price; I/Q output needed to reject rain (R6 at risk)
13 Sensor head board | 1 | Small microcontroller, IF amplifier, 12 V to 3.3 V regulator, two fused high-side switches for the ports; on a 65 x 56 mm board (prototype board with bought modules for the prototype) | Electronics distributor and PCB service (for example JLCPCB) | 8.00 | buy | Indicative price
14 Expansion ports | 2 | Sealed 5-pole A-coded M12 panel sockets with the sensor port pinout proposed to FieldNode on 2026-10-02 (pin 1 supply, pin 3 ground, pins 2 and 4 RS-485, pin 5 wake), 12 V SELV, PTC fused | Industrial connector supplier (for example an M12 cordset maker's distributor) | 4.00 | buy | Indicative price; FieldNode still has to agree the pinout (its O2)
15 Arm band clamps | 1 | Two stainless worm-drive band clamps, 12 mm band, sized for 50 to 80 mm arms; bracket folded from 2 mm aluminium sheet (110 mm channel, 40 mm web, two flanges with band slots); two EPDM strips 5 x 1.5 mm | Local hardware shop and sheet-metal fabricator | 7.00 | make | Indicative price; no drilling of the arm; was $6 for clamps and a solid bracket; bracket redesigned as a folded channel with band slots (LPN-DDR-003)
16 Hardware and consumables | 1 | Four M4 x 12 pan-head screws with bonded sealing washers and nuts (bracket), screws, conformal coating, potting compound, UV-stable cable ties | Local hardware shop | 7.00 | buy | Indicative price; no exploded-view callout; sealing washers and cable ties added (LPN-DDR-003)
17 Controller boards and fixings | 1 | Mains board: 80 mm round plated-hole FR4 prototype board with three notches; three 12 mm nylon spacers; three M3 x 30 female-female brass standoffs; three M3 brass heat-set inserts; three M3 x 30 and three M3 x 45 countersunk screws; 1 mm EPDM gasket ring for the dome; pluggable terminal blocks and wire for the board-to-board harness | Electronics distributor (for example Digi-Key or Mouser) and local hardware shop | 7.00 | buy | Indicative price; added for construction (LPN-DDR-003)
18 Head internal plate | 1 | Printed ASA plate 104 x 64 x 3 mm with a 25 degree radar cradle, on the four box bosses; M3 standoffs for the head board, nylon spacers for the radar, pluggable leads for the two ports | Local 3D printing service and electronics distributor | 4.00 | make | Indicative price; added for construction (LPN-DDR-003)

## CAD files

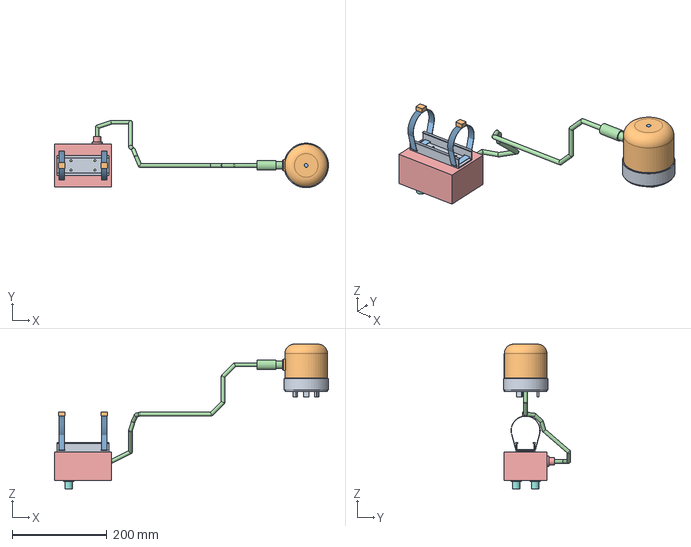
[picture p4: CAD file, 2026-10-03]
cad/step/lampnode-assembly.step
577.0 x 142.0 x 305.0 mm

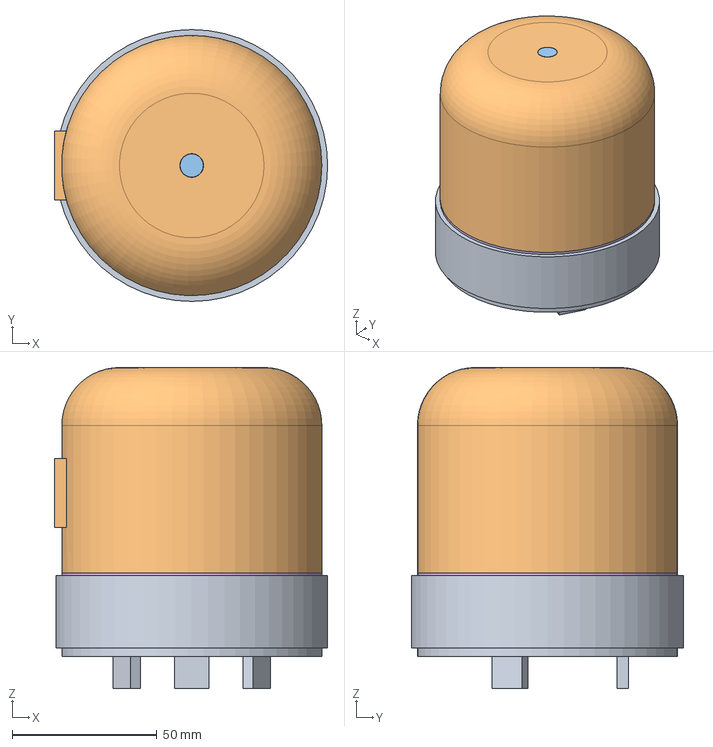
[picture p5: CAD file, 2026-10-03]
cad/step/lampnode-controller.step
94.5 x 94.0 x 111.0 mm

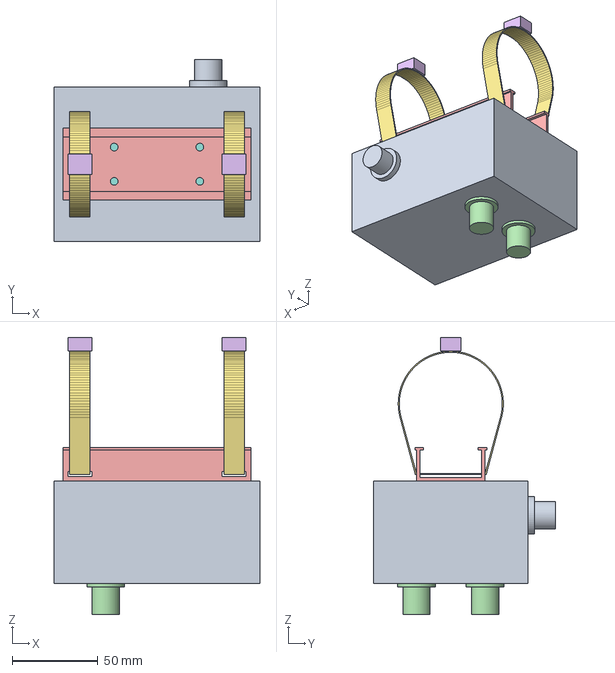
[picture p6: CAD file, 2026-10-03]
cad/step/lampnode-sensor-head.step
120.0 x 106.0 x 161.7 mm

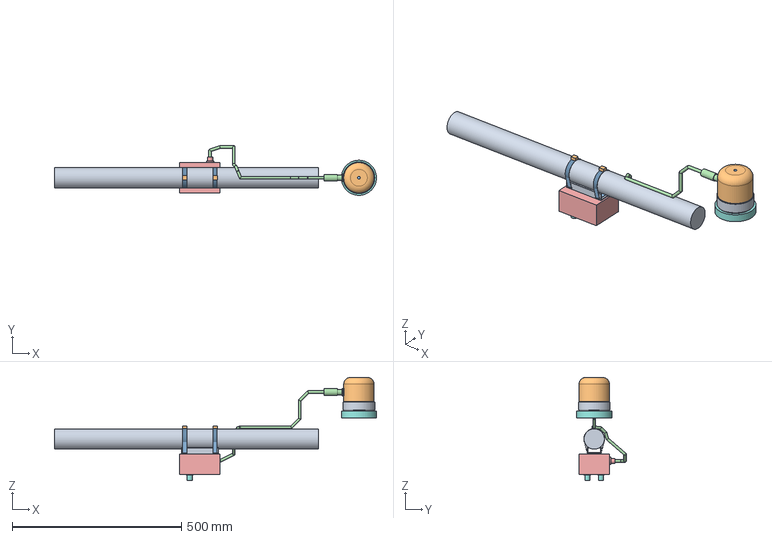
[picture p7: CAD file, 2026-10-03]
cad/step/lampnode-installed-reference.step
952.0 x 147.0 x 305.0 mm

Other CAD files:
cad/stl/lampnode-assembly.stl
cad/stl/lampnode-controller.stl
cad/stl/lampnode-installed-reference.stl
cad/stl/lampnode-sensor-head.stl

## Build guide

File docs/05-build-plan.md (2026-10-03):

---
doc_id: LPN-BLD-001
title: LampNode prototype build plan
project: LampNode
doc_type: Build plan
version: "0.3"
status: Draft
date: '2026-10-02'
author: Amish Chadha
license: CERN-OHL-S-2.0
revisions:
  - version: "0.1"
    date: '2026-10-01'
    author: Amish Chadha
    change: First build plan, with pictures by component and step; design made constructable (LPN-DDR-003)
  - version: "0.2"
    date: '2026-10-02'
    author: Amish Chadha
    change: 'Antenna band set to 915 MHz by the first-partner decision of 2026-10-02 (LPN-DEC-001); no design change'
  - version: "0.3"
    date: '2026-10-02'
    author: Amish Chadha
    change: 'M12 pin numbers added to the wiring figure and the head board steps; picture revision note (general arrangement Rev P4); no design change'
---

# LampNode prototype build plan

**Plan, not yet built.** How to build the first proof-of-concept prototype, component by component. Building and testing to it is TRL 4 work. Decisions still to be made are kept in the design decisions register ([docs/06-design-decisions.md](06-design-decisions.md)), not here.

## 1. What you are building

Figure 1. Every component, pulled apart and numbered in build order

*Figure 1. Every component pulled apart and numbered in build order: the controller (1 to 9), the sensor head (10 to 17) and the cable that joins them (18). The head is drawn beside the controller; on the street it hangs under the arm 470 mm toward the pole.*

The prototype is one LampNode on a bench mock-up of a streetlight: a twist-lock controller that plugs into a luminaire's photocontrol socket, and a small sensor head clamped under a short length of 60 mm tube that stands in for the lamp arm, joined by a 1 m cable. The controller is a bought twist-lock base with two round boards stacked on it and a printed dome over them; the head is a bought plastic box holding a printed plate with a radar module and a small board, screwed to a folded aluminium bracket. Figure 1 shows the 18 components in the order you make or fit them. Ten are made or worked in a small workshop: the drilled base, the two boards, the printed dome with its gasket and light pipe, the drilled box and lid, the printed internal plate, and the folded bracket with its rubber strips. Everything else is bought and fitted. The work is drilling plastic, cutting and folding thin aluminium sheet, two 3D prints, cutting prototype board and wiring bought modules onto it. The parts cost about USD 143 from the bill of materials.

> **Safety:** The controller works at mains voltage, up to 277 V AC nominal and 305 V at most. Build and check both boards unpowered. The first power-up is only through an isolating transformer and a residual current device, with the dome screwed on, at the safety stops of section 6. Never fit the prototype to a streetlight: that needs a laid-out circuit board, tests, a qualified electrician and the asset owner's permission. Cut aluminium and cut circuit board have sharp edges, and cutting circuit board makes glass-fibre dust: cut it wet or with extraction and wear a dust mask. Printing ASA gives off fumes; print in a ventilated space. Heat-set insert tools run at about 230 °C.

## 2. What changed to make it buildable

The concept showed what LampNode does; most of the parts inside it floated with nothing holding them, and some fixings could not be made as drawn. Each change below keeps what LampNode does, and all of them are recorded in decision record LPN-DDR-003, open for Amish's review.

*Table 1. Changes from the concept.*

| Component | The concept had | The buildable design has | Why |
| --- | --- | --- | --- |
| Parts inside the controller | Supply, relay and boards floating at different heights | Two round boards: the mains board on three 12 mm spacers carrying the surge parts, supply, relay and metering; the controller board on three 30 mm standoffs above it (Figure 7) | Every part now sits on something and is held |
| Dome to base | No fixing, no seal | Three bosses inside the dome foot with brass inserts, three screws from under the base, a 1 mm rubber ring under the dome (Figure 11) | No screw shows outside or passes through a seal |
| Base | Solid, undrilled | Six holes on a 60 mm circle between the blades, countersunk from below (Figure 3) | The only place inside the base gasket and clear of the contacts |
| M12 socket | On the curved side of the bought base | On a flat printed pad on the pole side of the dome (Figure 12) | A panel socket needs a flat face to seal on |
| Light window | An open 16 mm hole above the light pipe | An 8 mm clear rod sealed through the dome top, ending just above the light sensor (Figure 13) | One part is window and pipe, and rain stays out |
| Antenna | A rod standing on the board | A flexible strip stuck inside the dome wall (Figure 10) | Matches the part bought |
| Supply and surge parts | A large supply block and two small varistor discs | A real 5 W module size and one standing 20 mm varistor (Figure 6) | Room for the bosses, standoffs and socket |
| Inside the sensor head | A closed box with the board and radar floating | Box and lid; a printed plate on the box's own bosses, carrying the board and a 25° cradle for the radar (Figure 17) | Uses the bosses a stock box already has |
| Ports and gland | Hanging under the box, no holes or nuts | Ports through the lid and a gland in the side wall, each with a nut inside (Figure 17) | Every opening is sealed |
| Bracket and clamps | A solid block longer than the box, fused to two thick rings | A folded aluminium channel with rubber strips and band slots; the bands go over the arm and through the slots (Figure 19) | A channel centres itself on arms from 50 to 80 mm, and nothing is drilled in the arm |
| Cable route | Through the luminaire body and into the arm | Level out of the dome, past the luminaire, then along the top of the arm with cable ties | Clears everything, with a slack loop for the quarter turn |

## 3. Making the components

Make and check each component before the assembly step that needs it. Sizes are in millimetres. "Street side" means toward the luminaire end of the arm and "pole side" toward the pole; "left" and "right" are as seen standing at the pole looking along the arm. Angles round the controller are counted from the street side, anticlockwise seen from above. Workshop tolerance is 0.5 mm unless a step says otherwise; drawings do not carry tolerances before TRL 4.

### 3.1 Twist-lock base, drilled

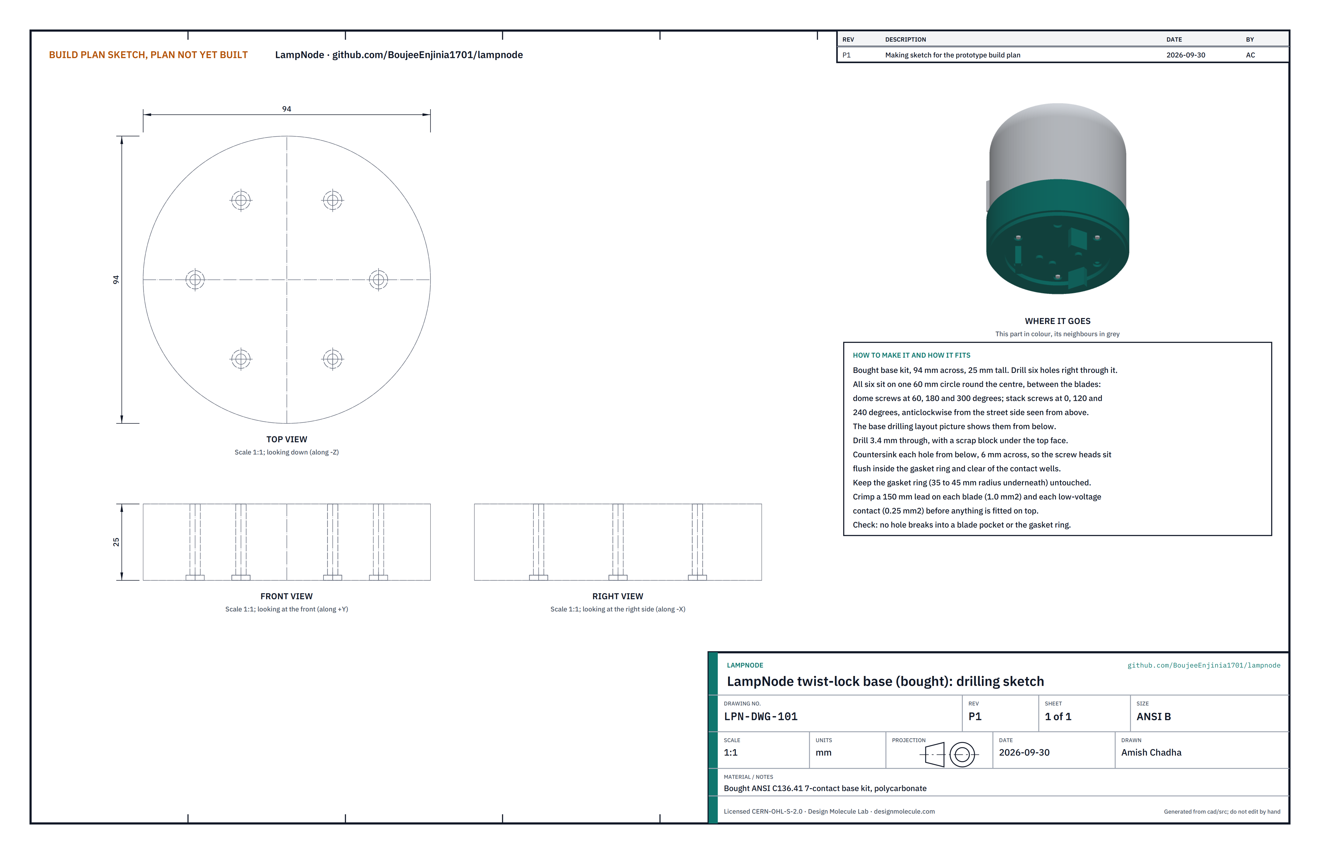
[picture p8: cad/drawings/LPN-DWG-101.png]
Figure 2. Drilling sketch of the twist-lock base


*Figure 2. Twist-lock base drilling sketch (LPN-DWG-101).*

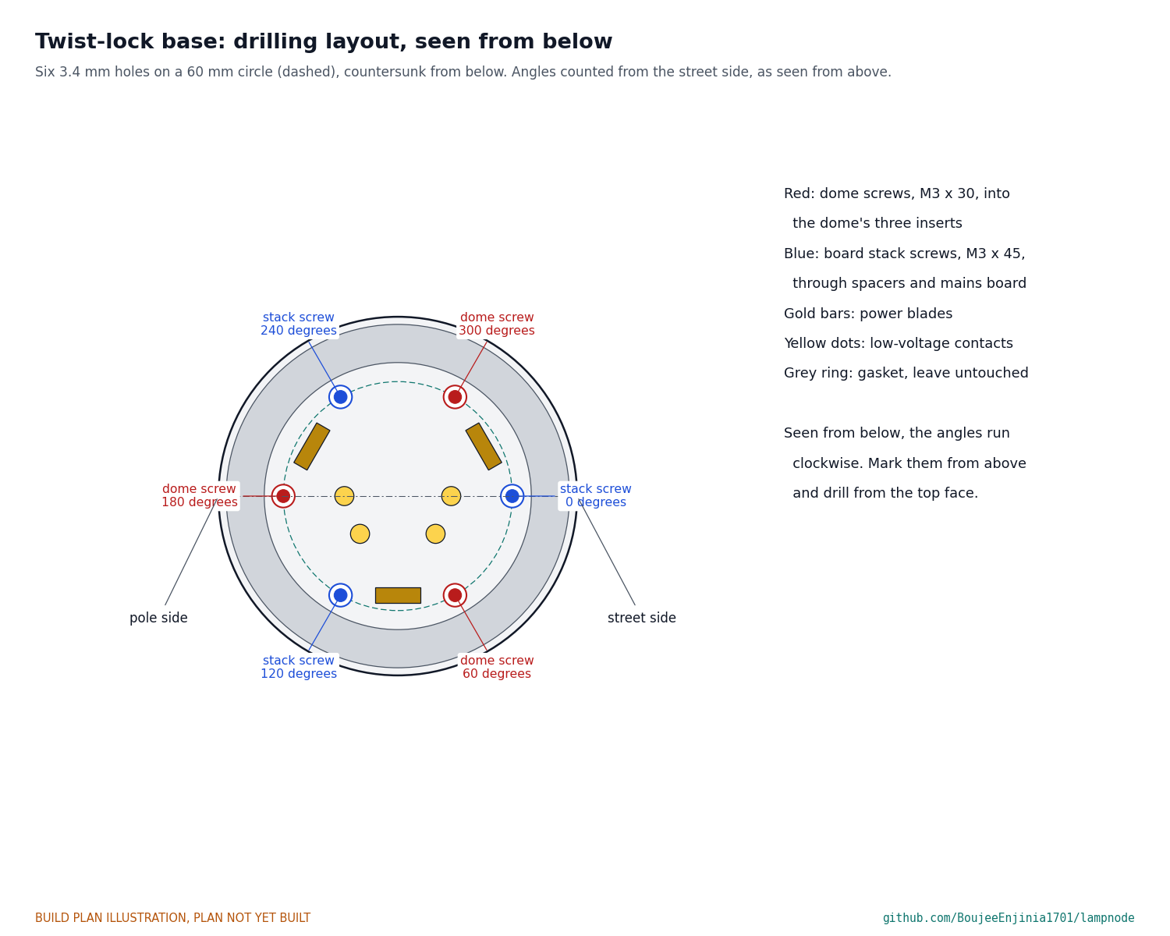
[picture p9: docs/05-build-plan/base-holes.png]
Figure 3. Base drilling layout, seen from below


*Figure 3. The six holes, seen from below: red for the dome screws, blue for the board stack screws.*

**What it is and what it is made from.** The bought plug that turns into the luminaire's socket: a polycarbonate disc 94 across and 25 tall, with three power blades, four low-voltage contact pads and a gasket on its underside. Six holes are drilled through it.

**How to make it.**

1. Mark a 60 mm circle on the top face, centred. Mark the pole side (the side the M12 socket will face) and call it 180°.
2. Mark six points on the circle: the dome screws at 60°, 180° and 300°, and the stack screws at 0°, 120° and 240°. Each lies half way between two blades.
3. Support the top face on a scrap block and drill 3.4 mm through at each point.
4. Turn the base over and countersink each hole to 6 mm across, so the screw heads sit flush. Do not touch the gasket ring, which runs from 35 to 45 mm out from the centre.
5. Crimp or solder a 150 mm lead to the inside terminal of each power blade (1.0 mm², 18 AWG) and of each low-voltage contact (0.25 mm², 24 AWG), and label them.

**How it fits the parts next to it.**

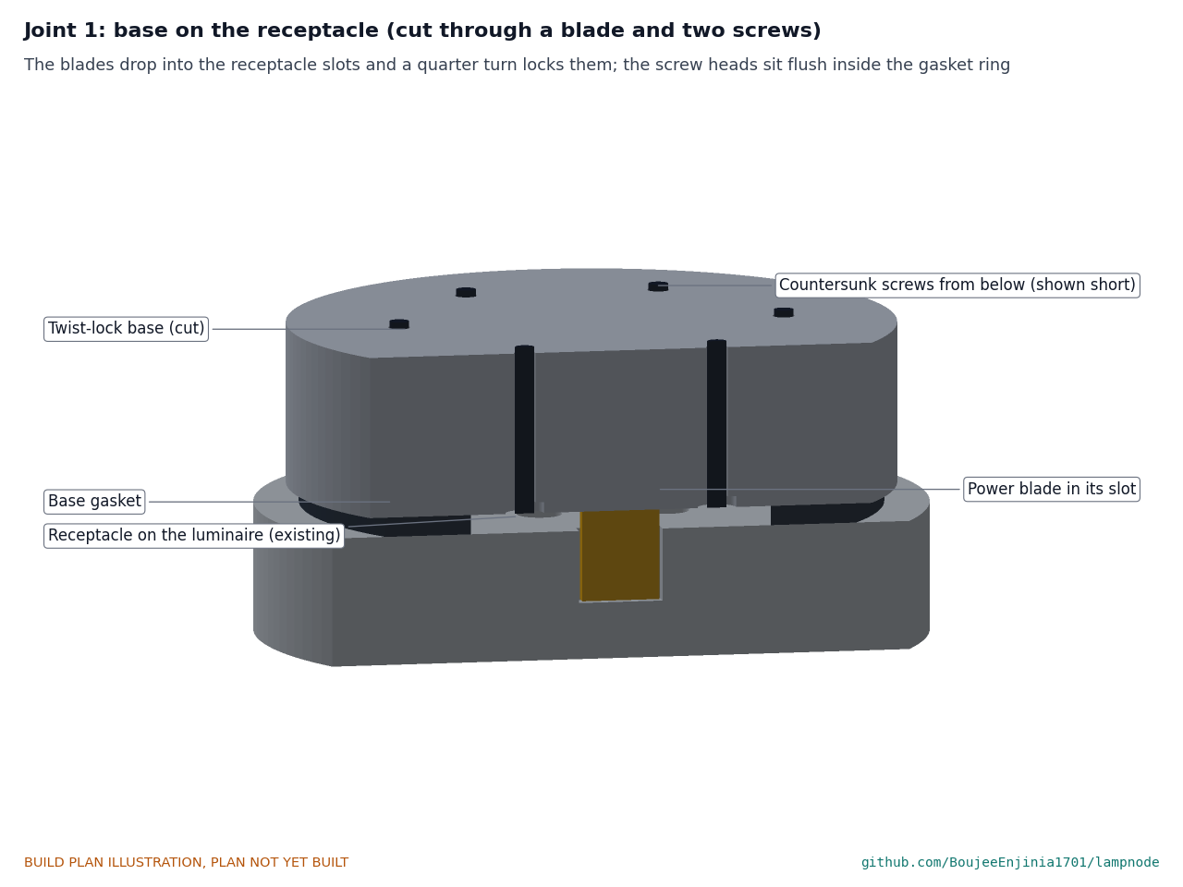
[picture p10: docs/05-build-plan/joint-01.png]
Figure 4. Joint 1: base on the receptacle


*Figure 4. The blades drop into the receptacle slots; a quarter turn locks them, and the base gasket seals against the receptacle top.*

The blades and contacts fit the luminaire's ANSI C136.41 receptacle with no change to it. The six countersunk heads sit inside the gasket ring, so the seal is untouched. The mains board stack and the dome screw onto the top face (Figures 7 and 11).

**Check before moving on.** No hole breaks into a blade pocket, a contact well or the gasket ring; every screw head sits flush or just below the underside.

### 3.2 Mains board

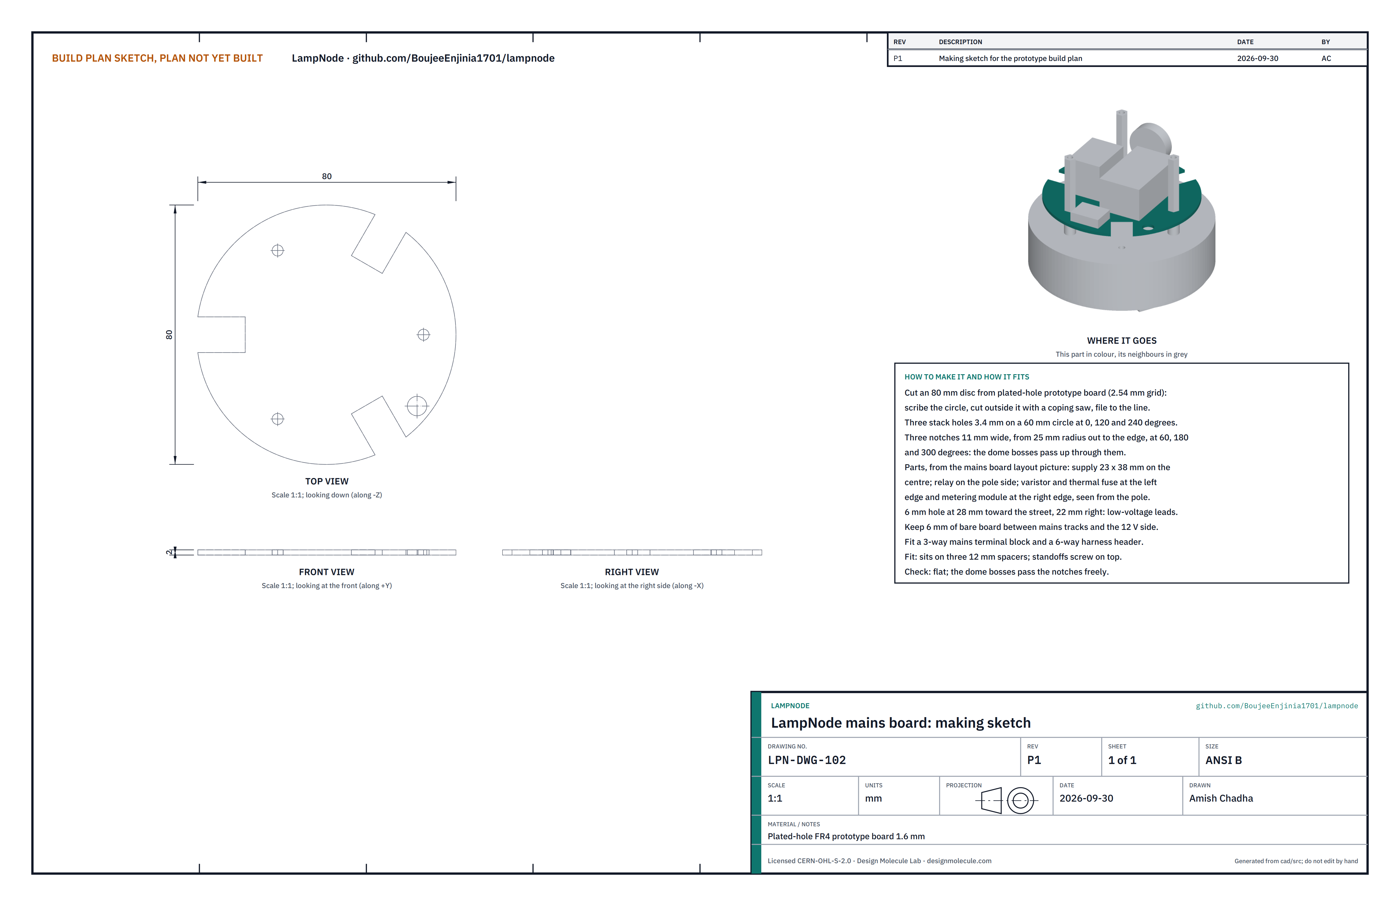
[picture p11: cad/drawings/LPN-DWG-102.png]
Figure 5. Making sketch of the mains board


*Figure 5. Mains board making sketch (LPN-DWG-102).*

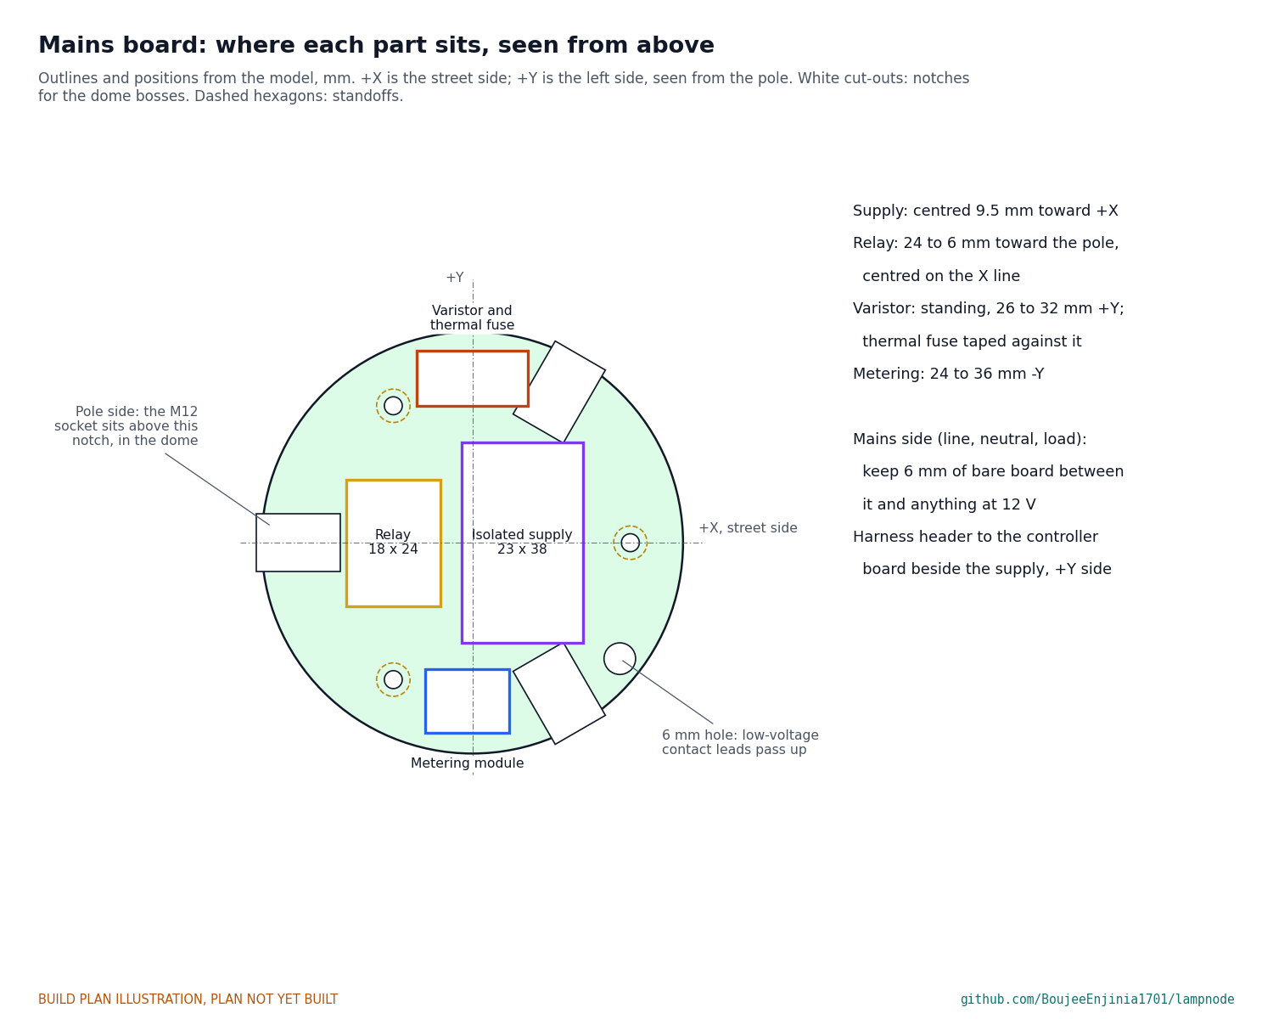
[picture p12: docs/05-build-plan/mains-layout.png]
Figure 6. Where each part sits on the mains board


*Figure 6. Parts on the mains board, seen from above, with the three notches and the three stack holes.*

**What it is and what it is made from.** The lower board, which carries everything at mains voltage: the thermal fuse and varistor, the relay that switches the lamp, the metering module, and the isolated supply that makes 12 V for everything else. An 80 mm disc of plated-hole glass-fibre prototype board, 1.6 mm thick.

**How to make it.**

1. Scribe an 80 mm circle on the board and cut just outside it with a coping saw, wet or with extraction. File to the line.
2. Drill the three stack holes 3.4 mm on a 60 mm circle at 0°, 120° and 240°.
3. Cut three notches 11 wide from 25 mm out to the edge at 60°, 180° and 300°: saw the sides and snap out the middle. The dome bosses pass up through them.
4. Drill a 6 mm hole 28 toward the street side and 22 to the right of centre, for the low-voltage contact leads to pass up to the controller board.
5. Place the parts as Figure 6 shows: the supply on the centre, the relay on the pole side, the varistor standing at the left edge with the thermal fuse taped against it, and the metering module at the right edge. Keep 6 mm of bare board between anything at mains voltage and anything at 12 V.
6. Fit a 3-way terminal block for the base leads (line, neutral, load) and a 6-way pluggable header for the harness to the controller board.
7. Wire the board as Figure 8 shows (section 3.2.1).

**How it fits the parts next to it.**

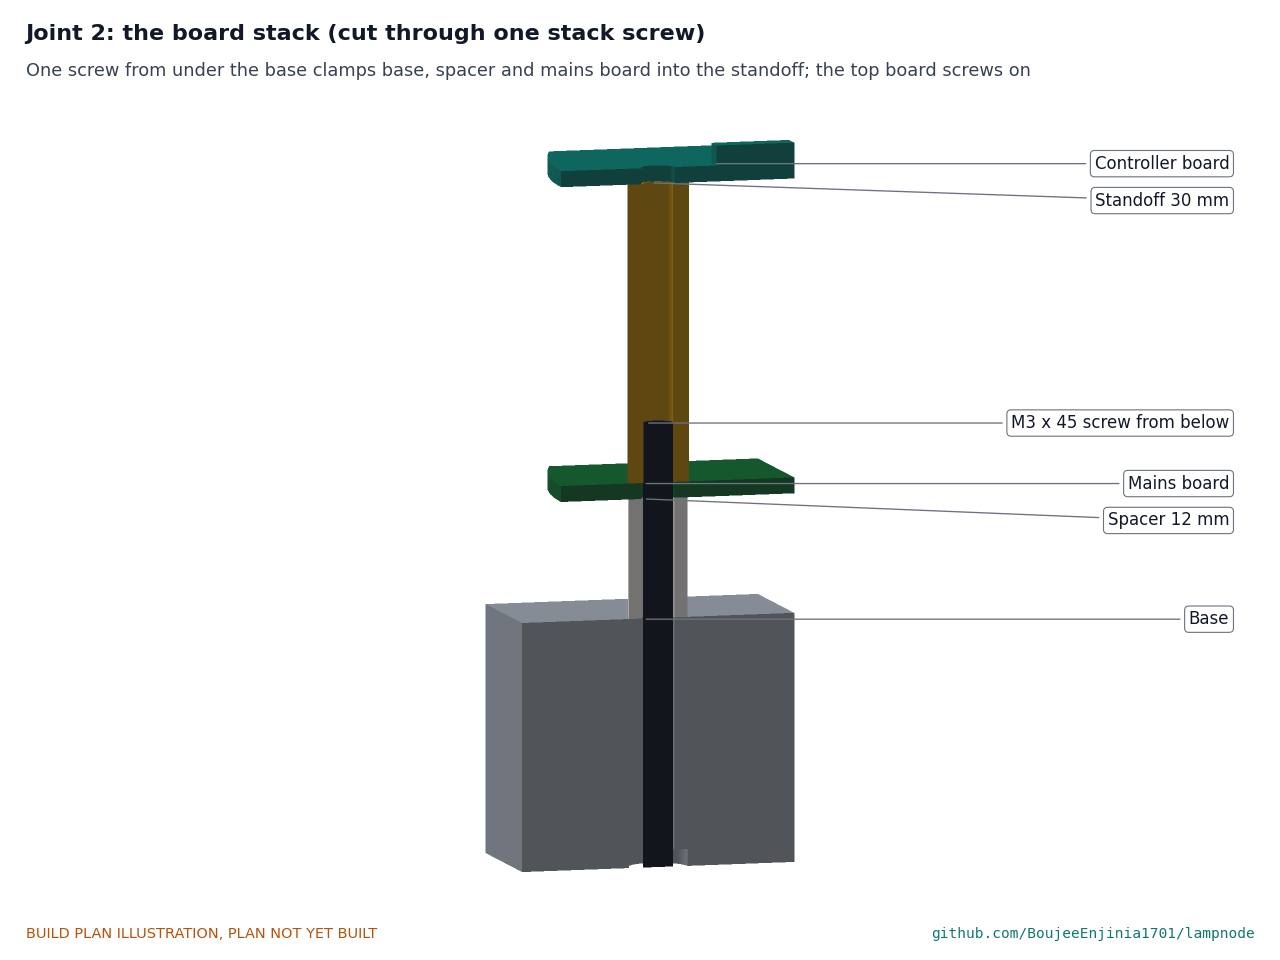
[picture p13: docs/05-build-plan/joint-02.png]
Figure 7. Joint 2: the board stack


*Figure 7. At each of the three stack points one screw from under the base clamps base, spacer and mains board into a standoff; the controller board screws on top.*

The board sits on three nylon spacers 12 tall, its underside 12 above the base. At each stack point an M3 x 45 countersunk screw goes up through the base, the spacer and the board into a 30 mm brass standoff. The dome bosses pass through the notches with 1 mm to spare.

**Check before moving on.** The board sits flat; the parts stand no taller than 22 mm; every mains joint is soldered and inspected under a lamp.

#### 3.2.1 Wiring

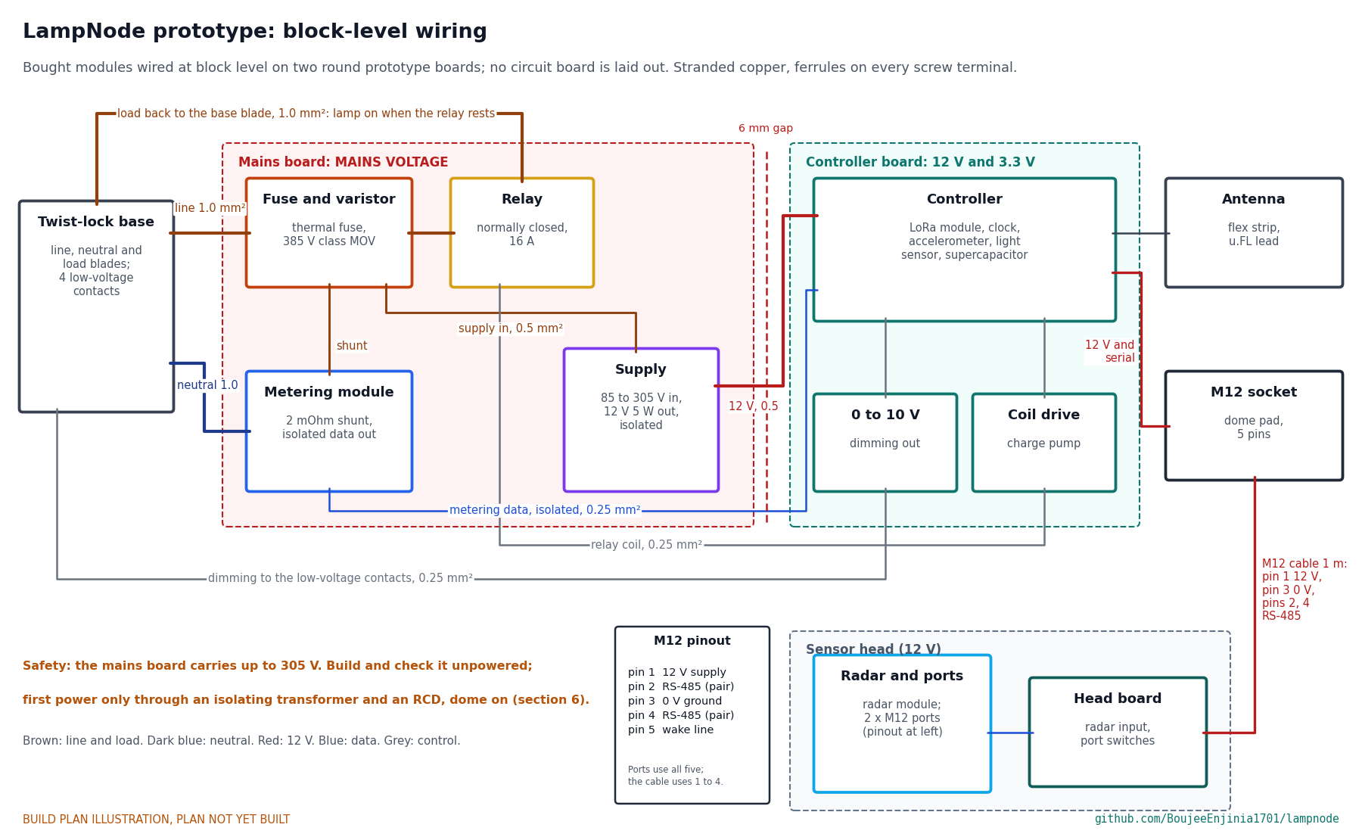
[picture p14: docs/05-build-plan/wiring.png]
Figure 8. Block-level wiring


*Figure 8. Block-level wiring with wire sizes, and the M12 pin numbers. No circuit board is laid out at this stage; bought modules on prototype board stand in for it.*

**M12 pin numbers.** Every M12 socket and plug in the prototype uses the same five pins. Pin 1 carries the 12 V supply, pin 3 is ground, pins 2 and 4 are the two wires of the serial data pair (RS-485), and pin 5 is a wake wire. The cable between the controller and the head uses pins 1 to 4 and leaves pin 5 spare. The two expansion ports on the head use all five. Number the pins on the lead plugs with a marker as you wire them, and check each one with a meter before the dome goes on.

The mains and controller circuits in the bill of materials will become laid-out boards at TRL 4. For this prototype, buy modules that meet this specification and wire them on the two round boards:

*Table 2. Modules for the two boards.*

| Module | What to buy |
| --- | --- |
| Supply | Encapsulated board-mount AC to DC module, 85 to 305 V AC in, 12 V 5 W out, reinforced isolation, no larger than 23 x 38 x 18 mm |
| Relay | Normally closed power relay, 16 A at 277 V AC, 12 V coil, rated for 80 A inrush or more, no larger than 18 x 24 x 20 mm |
| Surge parts | 20 mm class varistor of 385 V class with a thermal fuse, and transient voltage suppressor diodes for the low-voltage leads |
| Metering | Single-phase metering IC module with a 2 mΩ shunt and an isolated serial output, about 16 x 12 mm |
| Controller | STM32WL-class LoRaWAN module on its maker's breakout, temperature-compensated clock, accelerometer and ambient light sensor breakouts, a 0 to 10 V output stage, a charge-pump relay coil drive and a 0.22 F 5.5 V supercapacitor |

Wire it like this, with stranded copper and a ferrule on every screw terminal:

1. Base line lead to the terminal block, through the thermal fuse, to the varistor and the relay's common contact: 1.0 mm² (18 AWG).
2. Base neutral lead to the terminal block, the varistor and the supply input: 1.0 mm².
3. Relay normally closed contact back through the metering shunt to the base load lead: 1.0 mm². With the relay at rest the lamp is on.
4. Supply input from line and neutral after the fuse: 0.5 mm² (20 AWG).
5. Supply 12 V output to the harness header: 0.5 mm².
6. Metering module isolated data and the relay coil to the harness header: 0.25 mm² (24 AWG).
7. Low-voltage contact leads up through the 6 mm hole to the controller board's dimming output: 0.25 mm², twisted.
8. The antenna lead and the M12 socket leads plug into the controller board when the dome goes on (step 4).

**Check before moving on.** With nothing powered: every wire continues end to end; line, neutral and load read open to every 12 V point; the relay contact reads closed (lamp on) with the coil unpowered.

### 3.3 Controller board

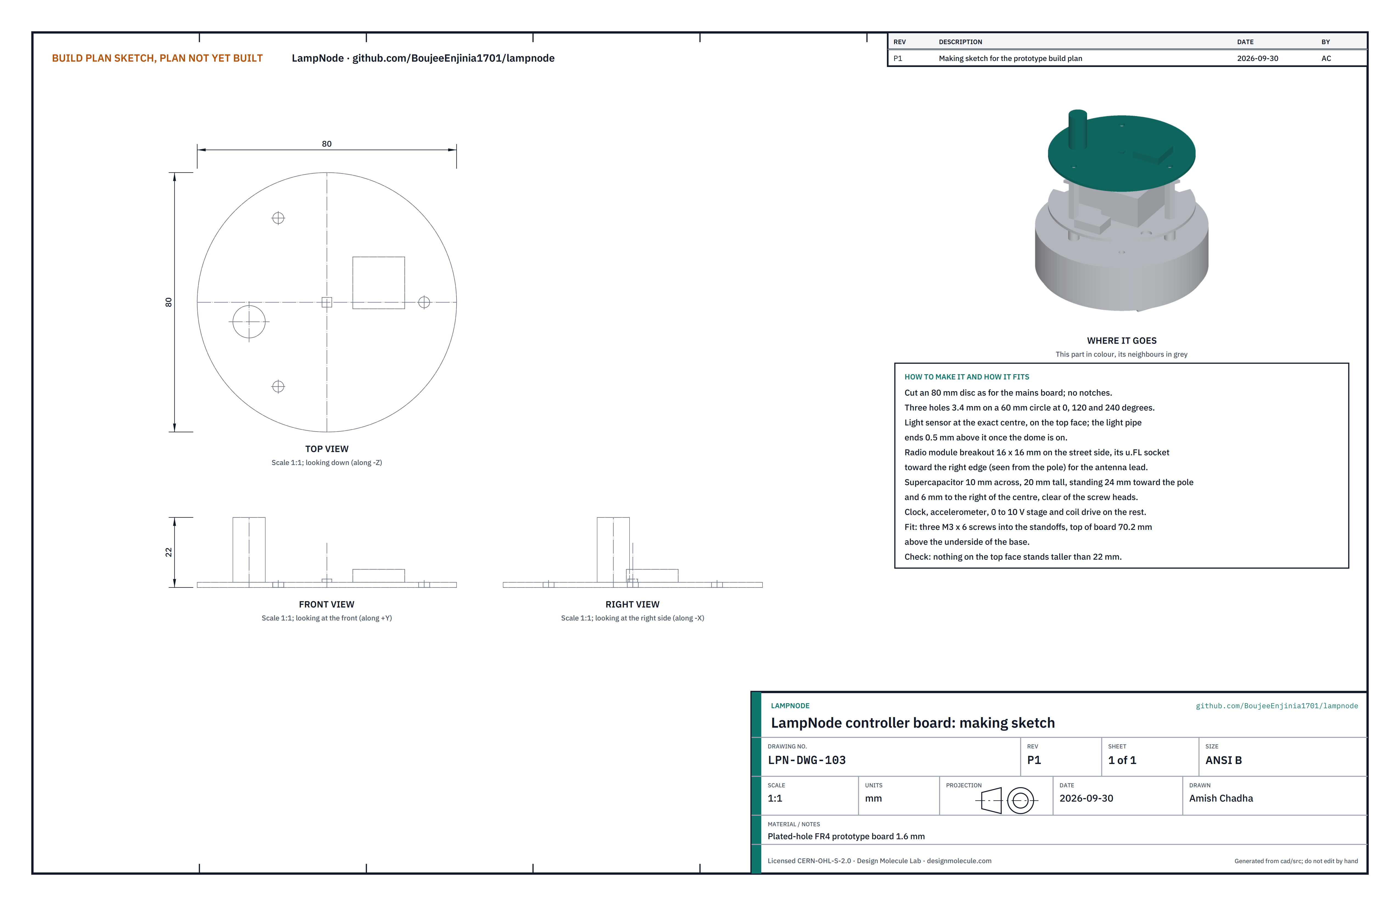
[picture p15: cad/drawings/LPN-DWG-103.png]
Figure 9. Making sketch of the controller board


*Figure 9. Controller board making sketch (LPN-DWG-103).*

**What it is and what it is made from.** The upper board: the radio, clock, light sensor, dimming output and relay drive, all at 12 V and below. An 80 mm disc of the same prototype board, with no notches.

**How to make it.**

1. Cut the disc as in section 3.2 and drill the three stack holes 3.4 mm at 0°, 120° and 240°.
2. Fit the light sensor at the exact centre of the top face. The light pipe will end 0.5 mm above it.
3. Fit the radio breakout on the street side, its antenna socket toward the right edge.
4. Stand the supercapacitor 24 toward the pole and 6 to the right of centre, clear of the screw heads.
5. Fit the clock, accelerometer, dimming stage and coil drive on the rest of the board, and the matching 6-way harness plug.

**How it fits the parts next to it.** Three M3 x 6 screws hold it on the standoffs, its top face 70.2 above the underside of the base and 23.8 below the inside of the dome top (Figure 7). Nothing on its top may stand taller than 22 mm.

**Check before moving on.** The harness plugs in without strain; the board drops onto the standoffs with the holes lined up.

### 3.4 Dome, with its gasket, light pipe, antenna and M12 socket

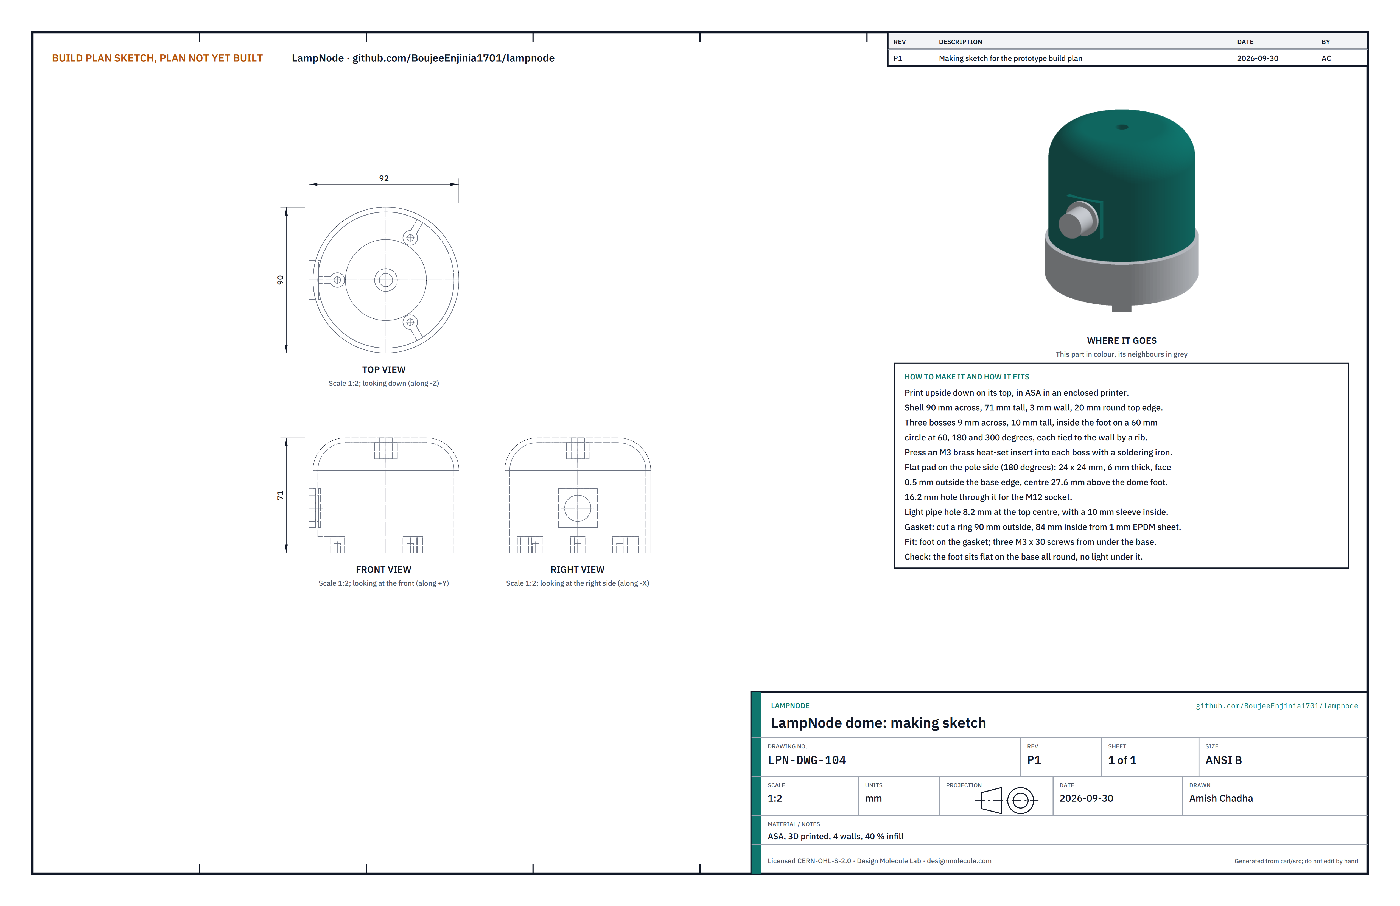
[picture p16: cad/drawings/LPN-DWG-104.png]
Figure 10. Making sketch of the dome


*Figure 10. Dome making sketch (LPN-DWG-104).*

**What it is and what it is made from.** The weatherproof cover: a printed shell 90 across and 71 tall in ASA, which resists sunlight. It carries the light pipe in its top, the antenna on its inside wall and the M12 socket in a flat pad on the pole side.

**How to make it.**

1. Print the dome upside down, standing on its top, in an enclosed printer: 4 walls, 40 % infill. Let it cool on the bed.
2. Press an M3 brass heat-set insert into each of the three bosses with a soldering iron and insert tip, square to the foot.
3. Cut the gasket: a ring 90 outside and 84 inside, from 1 mm EPDM rubber sheet, with a sharp knife against a printed or cut template.
4. Light pipe: cut 8 mm clear acrylic rod 25.3 long, polish both ends, push it into the hole in the top flush with the outside, and seal it with a thin bead of clear UV-stable silicone round the outside.
5. Antenna: clean the inside wall on the right side, between 20 and 30 above the foot, and stick the flexible antenna strip there, centred on the right-hand side, its lead pointing up.
6. M12 socket: fit it from outside through the 16.2 mm hole in the pad, with its seal outside and its nut inside, to the maker's torque. Solder a 120 mm lead set to it with a plug for the controller board.

**How it fits the parts next to it.**

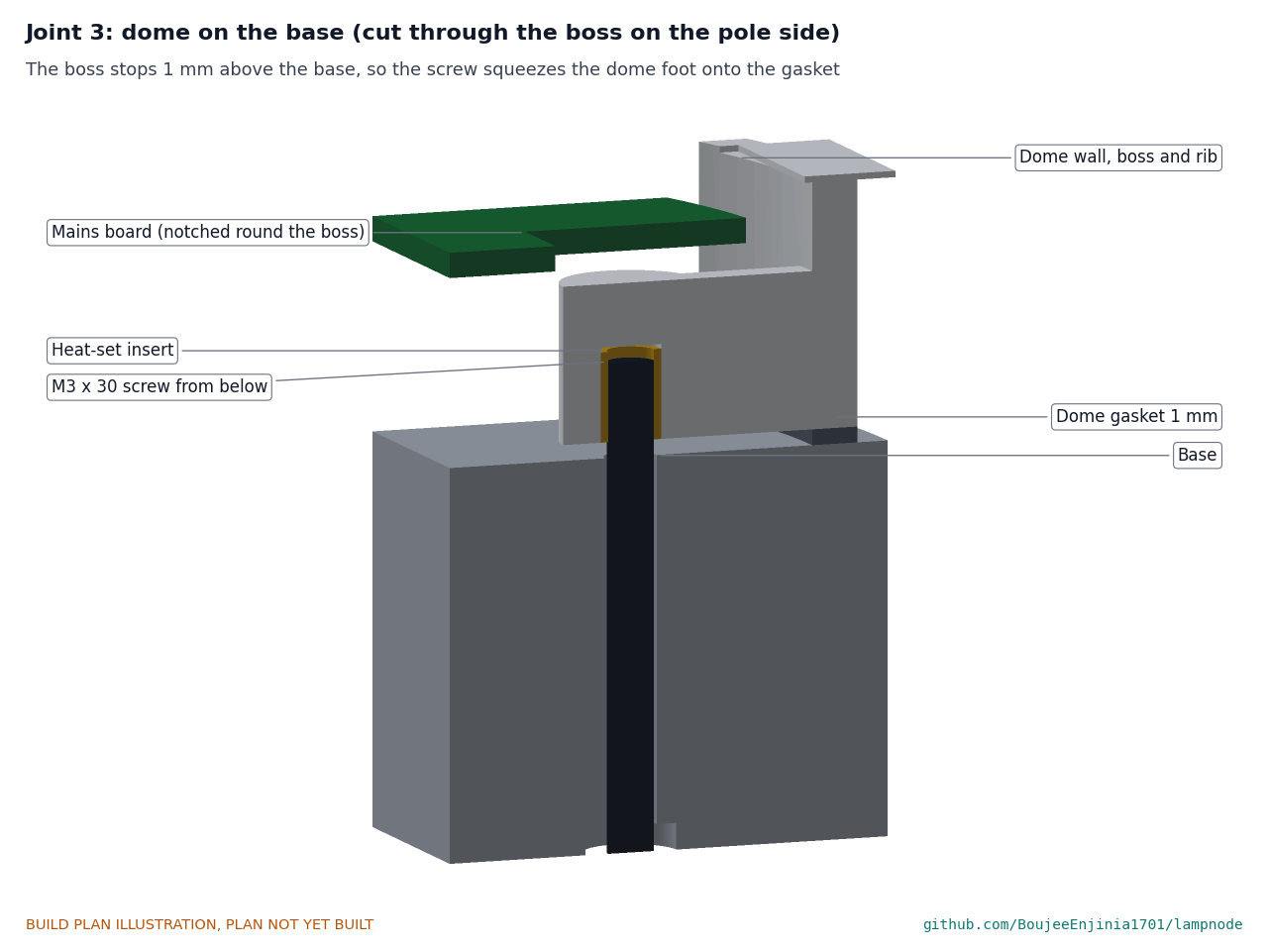
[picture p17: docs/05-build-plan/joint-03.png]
Figure 11. Joint 3: dome on the base


*Figure 11. Each boss stops 1 mm above the base, so the screw squeezes the dome foot onto the rubber ring.*

The dome foot sits on the rubber ring on the top face of the base. Three M3 x 30 countersunk screws come up from under the base into the inserts. The bosses pass through the mains board notches.

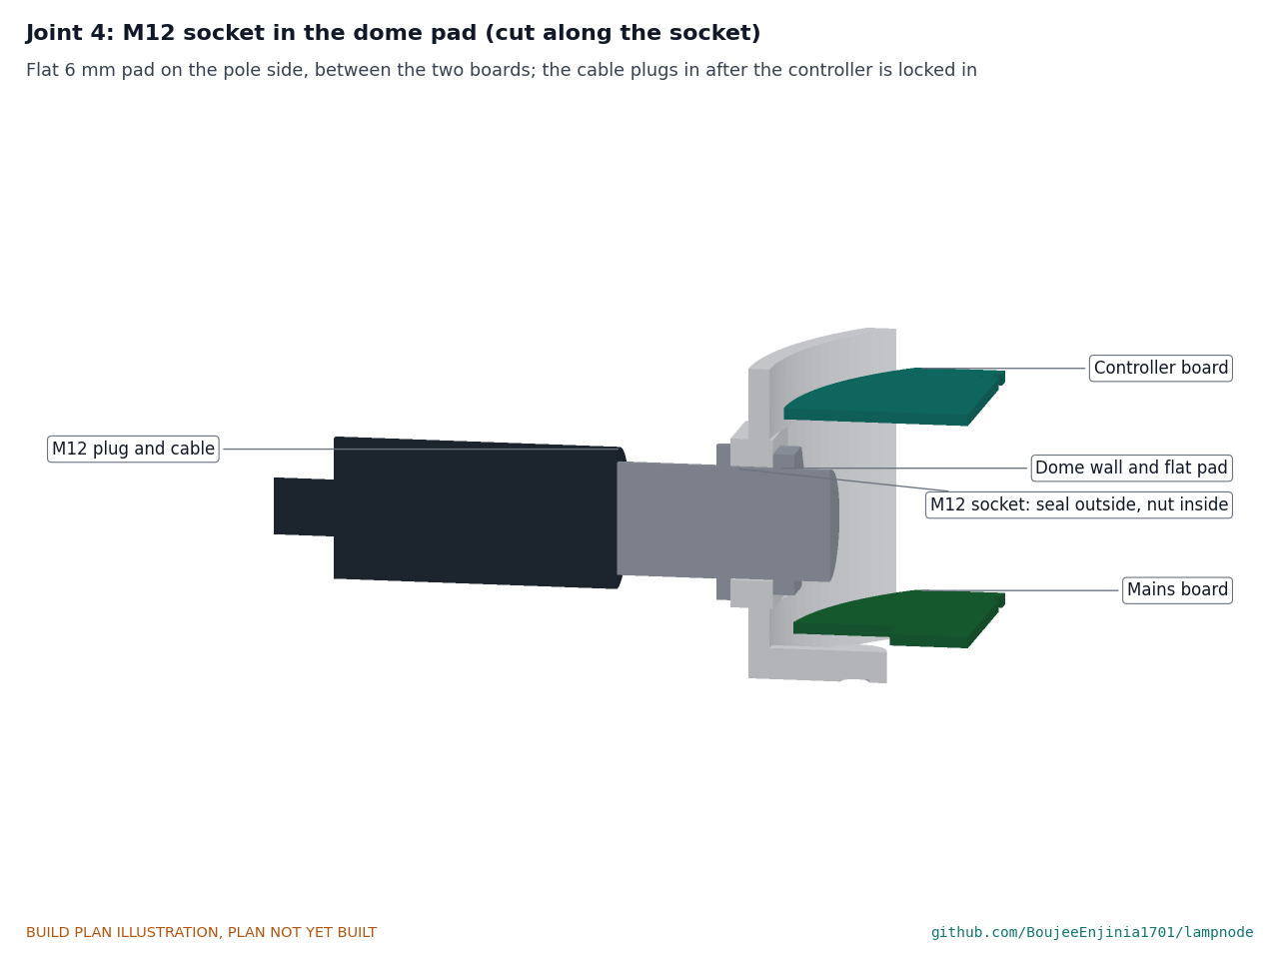
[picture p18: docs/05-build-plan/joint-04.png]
Figure 12. Joint 4: M12 socket in the dome pad


*Figure 12. The flat 6 mm pad on the pole side, with the socket's seal outside and its nut inside.*

The socket sits between the two boards, 3 mm or more from every part on them. The cable plug goes on only after the controller is turned into the receptacle (step 11).

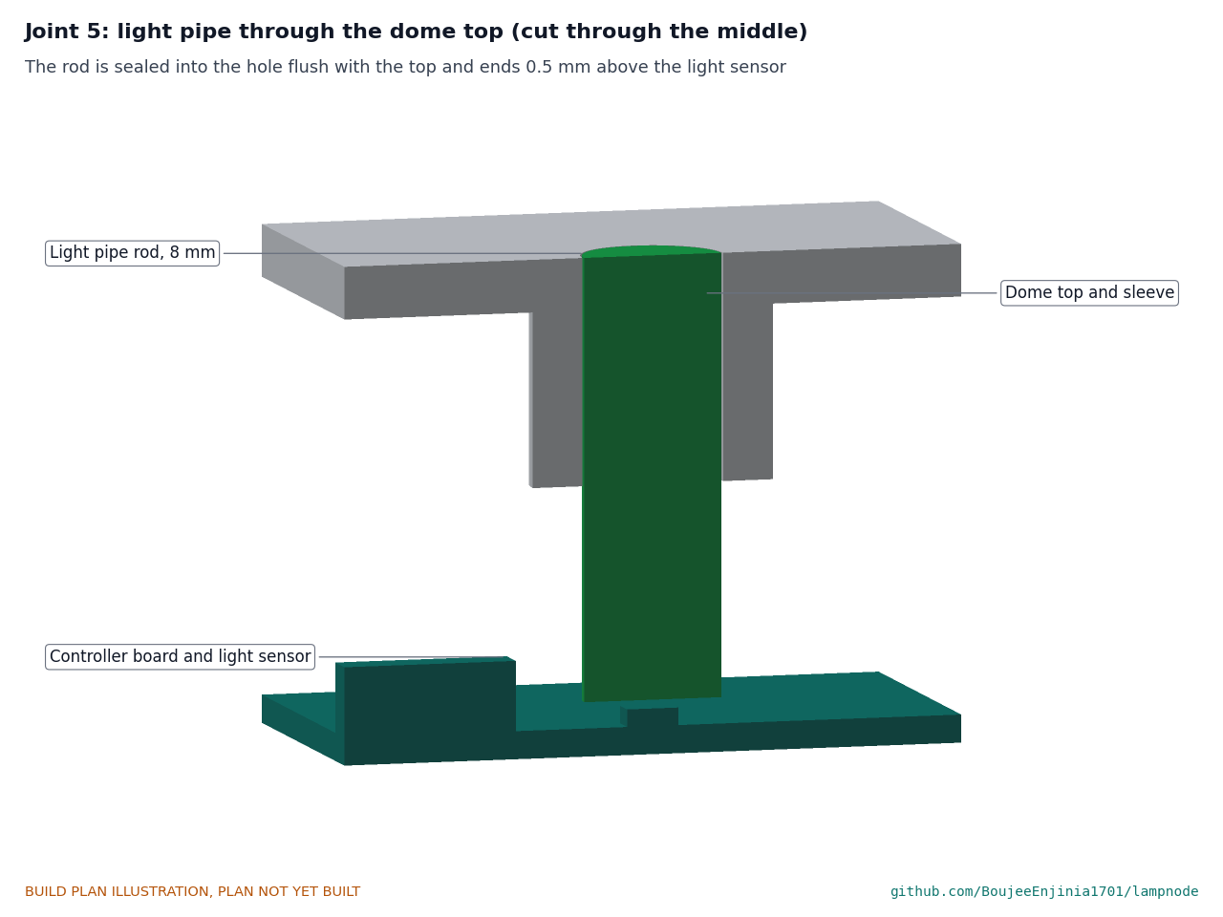
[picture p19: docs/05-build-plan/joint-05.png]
Figure 13. Joint 5: light pipe through the dome top


*Figure 13. The rod is sealed into the dome top and ends 0.5 mm above the light sensor.*

**Check before moving on.** On a trial fit over the board stack the dome foot sits flat on the base all round with no light under it; the rod ends 0.5 mm, give or take 0.3, above the sensor (check with a feeler gauge through the side before the dome is screwed down).

### 3.5 Sensor head box and lid, drilled, with the gland and ports

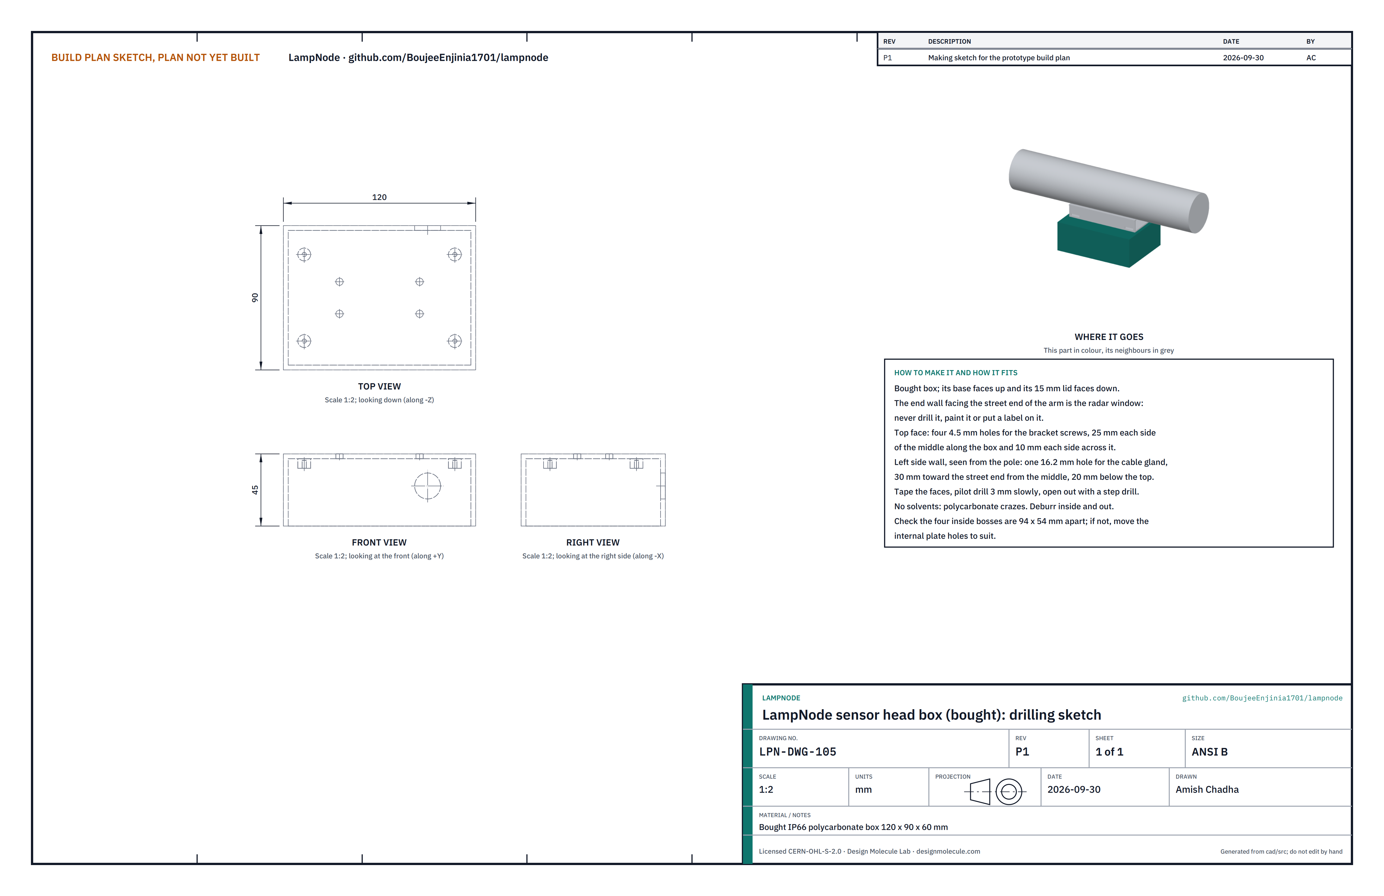
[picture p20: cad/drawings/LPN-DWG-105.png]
Figure 14. Drilling sketch of the sensor head box


*Figure 14. Sensor head box drilling sketch (LPN-DWG-105).*

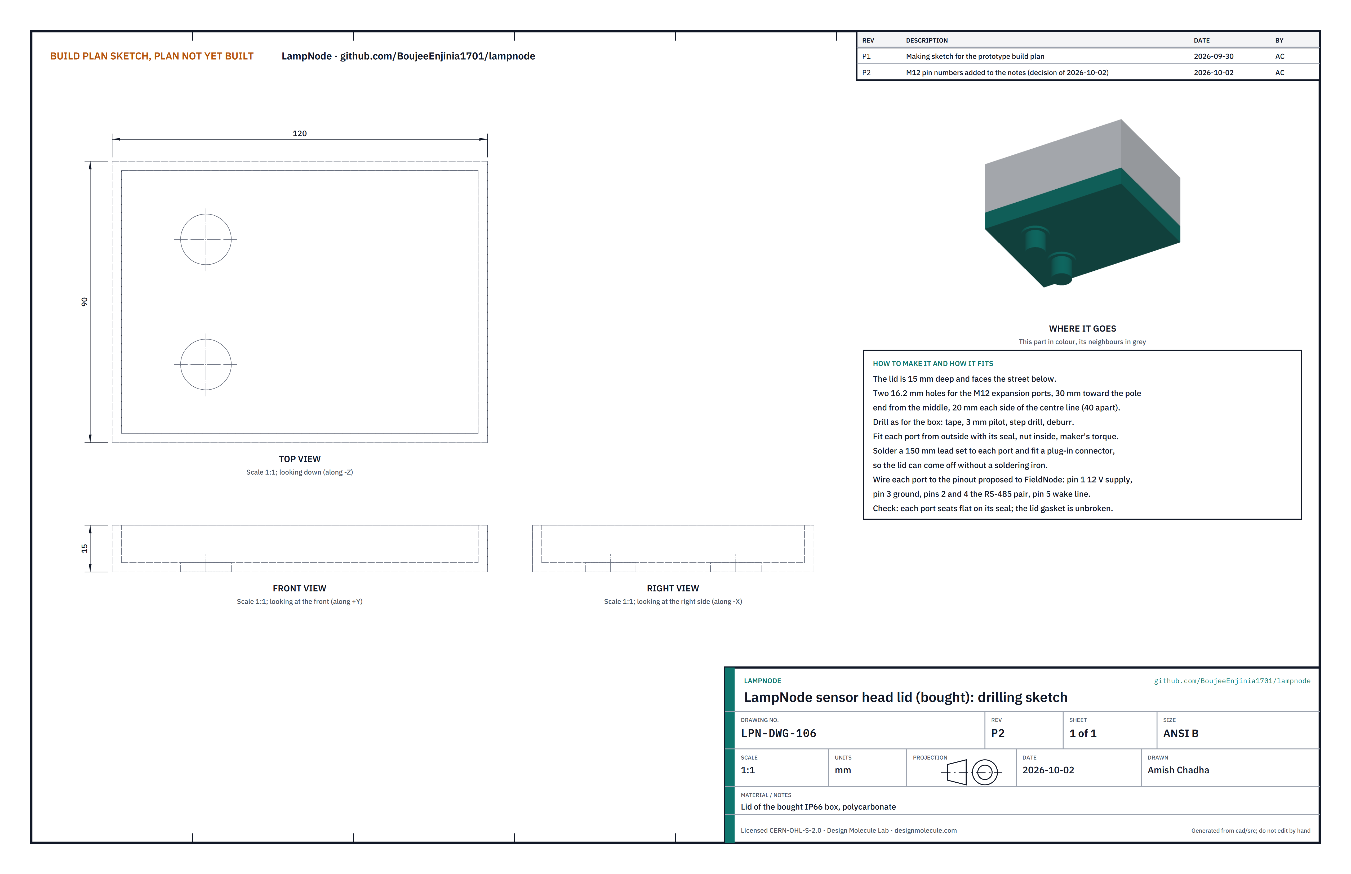
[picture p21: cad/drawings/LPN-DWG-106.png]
Figure 15. Drilling sketch of the sensor head lid


*Figure 15. Sensor head lid drilling sketch (LPN-DWG-106).*

**What it is and what it is made from.** A bought grey polycarbonate box 120 long, 90 wide and 60 tall, rated IP66, with a 15 mm deep gasketed lid and four moulded bosses inside its base. It hangs base up, lid down. Its street-side end wall is the radar window.

**How to make it.**

1. Cover the faces to be drilled with masking tape.
2. Top face (the box's base): four 4.5 mm holes, 25 each side of the middle along the box and 10 each side of the centre line across it.
3. Left side wall: one 16.2 mm hole for the cable gland, 30 toward the street end from the middle and 20 below the top face.
4. Lid: two 16.2 mm holes for the expansion ports, 30 toward the pole end from the middle and 20 each side of the centre line.
5. Pilot drill every hole 3 mm at low speed with wood behind, open out with a step drill, light pressure, and deburr inside and out. Clean with water and mild soap only; solvents craze polycarbonate.
6. Never drill, paint or label the street-side end wall.
7. Fit the gland in the side wall and the two ports in the lid, each from outside with its seal, nut inside, to the maker's torque. Solder a 150 mm lead set to each port with a plug for the head board, keeping to the M12 pin numbers under Figure 8 (pin 1 supply, pin 3 ground, pins 2 and 4 data, pin 5 wake).

**How it fits the parts next to it.** The bracket screws onto the top face (Figure 20); the internal plate screws onto the bosses (Figure 17); the lid closes on its own gasket with its captive screws.

**Check before moving on.** Each gland and port seats flat on its seal; no crack runs from any hole under a bright lamp; the bosses are 94 by 54 apart (if not, move the internal plate holes to suit before printing it).

### 3.6 Head internal plate with the radar and head board

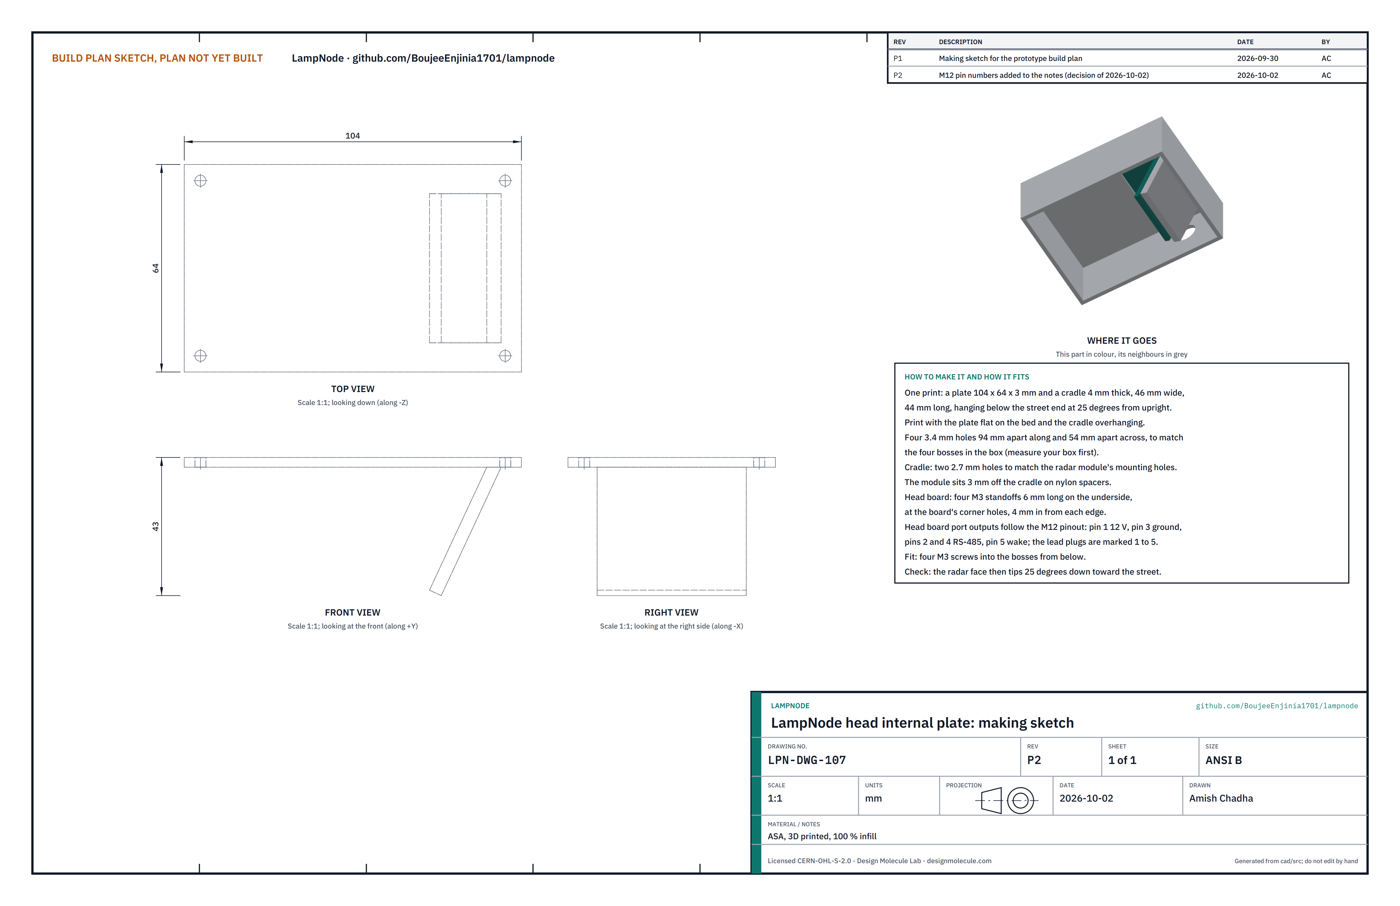
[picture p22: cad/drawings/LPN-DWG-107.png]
Figure 16. Making sketch of the head internal plate


*Figure 16. Head internal plate making sketch (LPN-DWG-107).*

**What it is and what it is made from.** One printed part in ASA, 100 % infill: a plate 104 x 64 x 3 that screws to the box's bosses, with a cradle at its street end that holds the radar module 25° down from upright, looking along the street.

**How to make it.**

1. Print it with the plate flat on the bed; the cradle overhangs at 25° and needs no support.
2. Check the four holes against the box's bosses (94 x 54 apart) and the two cradle holes against your radar module; drill them out to 3.4 and 2.7 if the print closed them up.
3. Fit four M3 standoffs 6 long under the plate for the head board.
4. Fit the radar module to the cradle on two M2.5 screws with 3 mm nylon spacers, its face toward the street end.
5. Fit the head board (65 x 56, prototype board with the microcontroller, regulator and port switch modules) on the standoffs with four M3 screws.
6. Mark the port outputs on the board as they are wired: the two port plugs follow the M12 pin numbers under Figure 8 (pin 1 supply, pin 3 ground, pins 2 and 4 data, pin 5 wake).

**How it fits the parts next to it.**

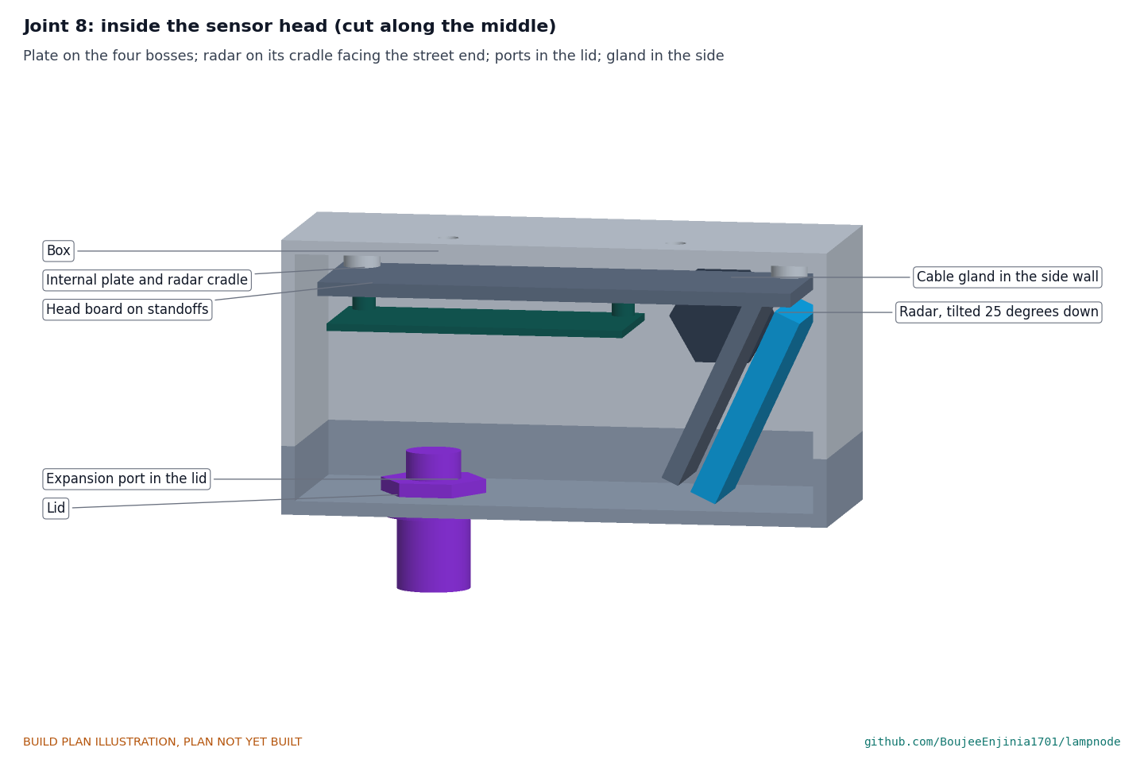
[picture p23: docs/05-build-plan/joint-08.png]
Figure 17. Joint 8: inside the sensor head


*Figure 17. The plate sits on the four bosses; the radar faces the street end wall 1.6 mm or more clear of the box and lid; the ports come through the lid and the gland through the side.*

Four M3 screws hold the plate to the bosses, 6 below the inside of the box top. The radar hangs 1 mm below the plate, clear of the lid by 1.6 mm. The bracket screw nuts sit 1.3 above the plate.

**Check before moving on.** Laid on a flat surface the plate does not rock; the radar face tips 25° (give or take 2°) from upright, checked with an angle finder.

### 3.7 Bracket and rubber strips

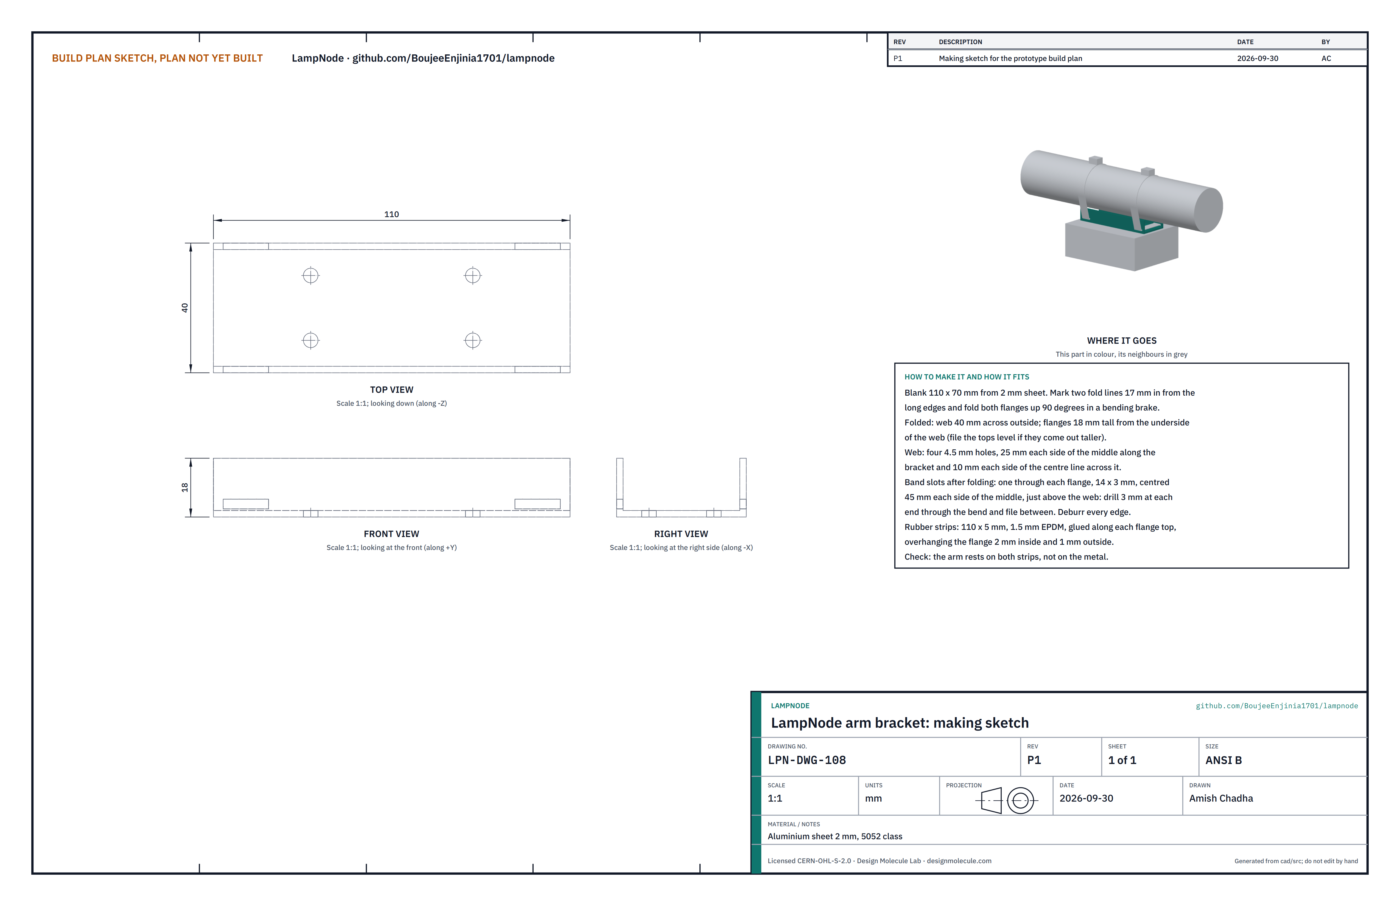
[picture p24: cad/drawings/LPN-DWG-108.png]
Figure 18. Making sketch of the bracket


*Figure 18. Bracket making sketch (LPN-DWG-108).*

**What it is and what it is made from.** A channel folded from 2 mm aluminium sheet, 5052 class, that the box screws to and the lamp arm rests on, with two band clamps holding it to the arm. Two strips of 1.5 mm EPDM rubber keep the arm off the metal.

**How to make it.**

1. Cut a blank 110 x 70 and deburr it. Mark two fold lines 17 in from the long edges.
2. Drill the four 4.5 mm screw holes in the web: 25 each side of the middle along the bracket, 10 each side of the centre line across it.
3. Fold both flanges up 90° in a bending brake. Folded, the web is 40 across outside and the flanges stand 18 from the underside of the web; file the flange tops level if they come out taller.
4. Cut the band slots after folding: in each flange, 14 long and 3 tall, centred 45 each side of the middle, just above the web. Drill 3 mm at each end through the bend and file between.
5. Cut two strips of 1.5 mm EPDM 110 x 5 and glue one along each flange top, overhanging the flange 2 inside and 1 outside.

**How it fits the parts next to it.**

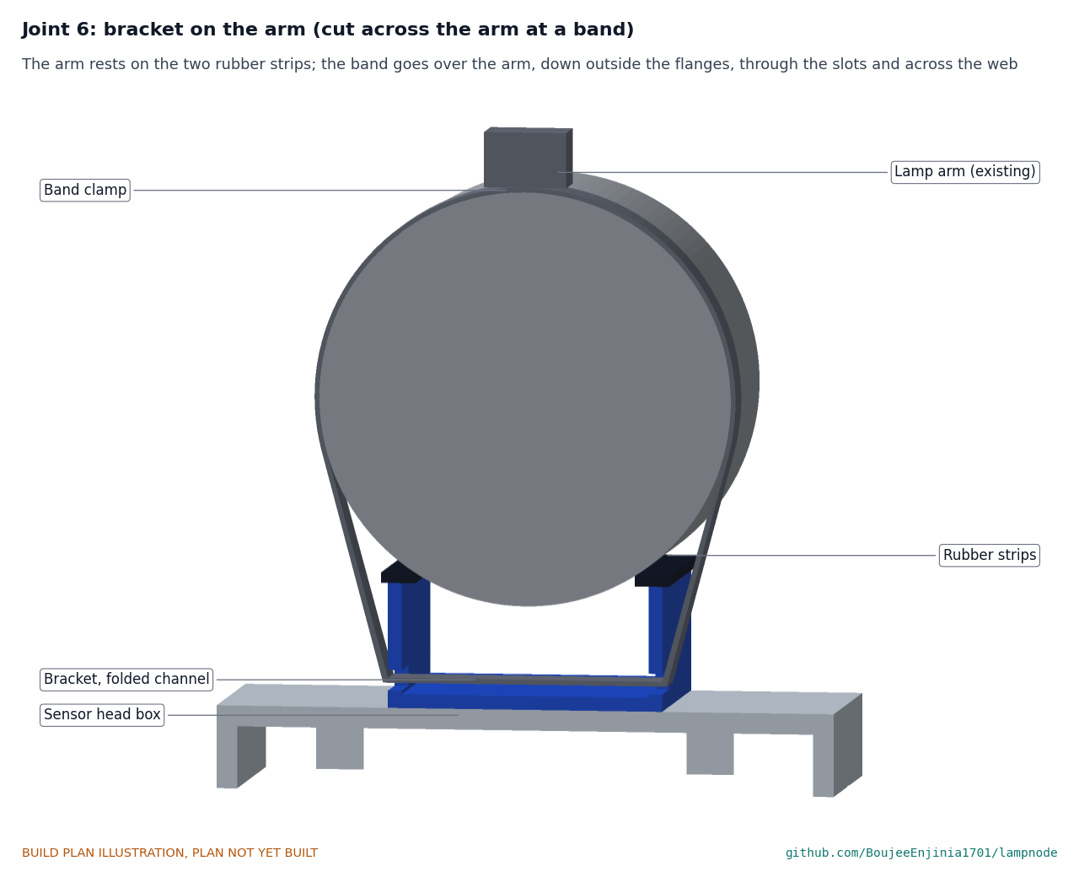
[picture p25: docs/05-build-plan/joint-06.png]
Figure 19. Joint 6: bracket on the arm


*Figure 19. Section across the arm at one band: the arm rests on both rubber strips, and the band goes over the arm, down outside the flanges, through the slots and across the web.*

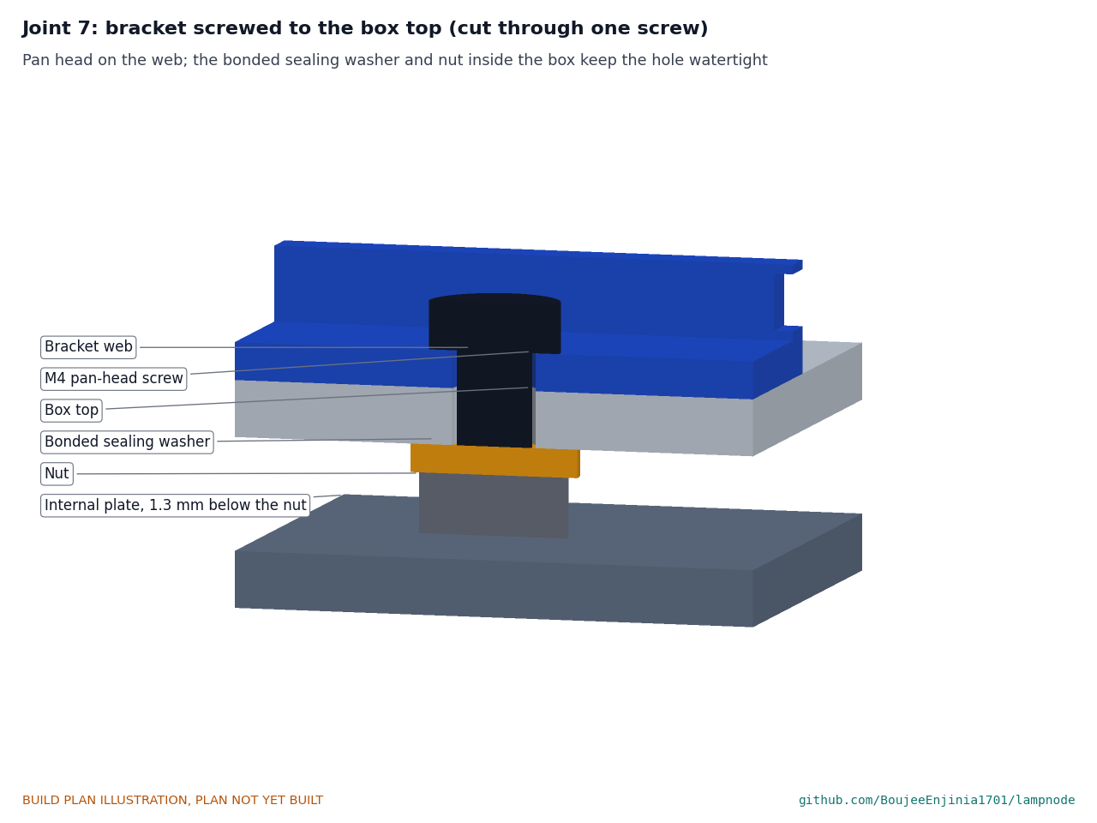
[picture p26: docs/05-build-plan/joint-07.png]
Figure 20. Joint 7: bracket screwed to the box top


*Figure 20. Pan head on the web; bonded sealing washer and nut inside the box.*

The web sits flat on the box top, held by four M4 x 12 pan-head screws with bonded sealing washers and nuts inside the box. A 60 mm arm touches the strips 16 out from the centre line and clears the metal by 2 or more; arms from 50 to 80 mm also sit on both strips. The box top hangs 15 below a 60 mm arm.

**Check before moving on.** Laid on a length of 60 mm tube the bracket does not rock and no metal touches the tube.

### 3.8 Bought components

Buy to specification, not brand. Line numbers are those of the bill of materials.

- **Twist-lock base (line 1).** ANSI C136.41 7-contact photocontrol base kit with gasket, with solid material or bosses at the six screw points (check before drilling).
- **Surge parts, supply, relay and metering (lines 3 to 6) and the controller parts (line 7).** As Table 2.
- **Antenna (line 8).** Flexible sub-GHz antenna about 70 x 10 with an adhesive back and a u.FL lead, for the 915 MHz band of the first partner's region (a US partner, LPN-DEC-001).
- **Light sensor and pipe (line 9).** Ambient light sensor breakout; 8 mm clear acrylic rod.
- **M12 socket and cable (line 10).** 5-pole A-coded M12 panel socket with an M16 thread for walls up to 6 mm; 1 m UV-rated single-ended M12 cordset.
- **Sensor head box (line 11).** As section 3.5, with one M16 nylon cable gland for 4 to 8 mm cable.
- **Radar (line 12).** 24 GHz Doppler module with I/Q output, no larger than 50 x 44, with two mounting holes.
- **Head board parts (line 13).** Small microcontroller board, 12 V to 3.3 V regulator, two fused high-side switch modules, radar signal amplifier.
- **Expansion ports (line 14).** Two 5-pole A-coded M12 panel sockets with caps.
- **Band clamps (line 15).** Two stainless worm-drive clamps with 12 mm band; the loop is about 220 mm for a 60 mm arm (about 190 for 50 mm and 280 for 80 mm).
- **Fixings and boards (lines 16 and 17).** Three 12 mm nylon spacers; three M3 x 30 female-female brass standoffs; three M3 brass heat-set inserts; three M3 x 30 and three M3 x 45 countersunk screws; three M3 x 6 screws; four M4 x 12 pan-head screws with bonded sealing washers and nuts; two 100 x 100 plated-hole prototype boards; 1 mm EPDM sheet; terminal blocks, pluggable headers, wire, ferrules, UV-stable cable ties, desiccant pack.
- **Head plate fixings (line 18).** Four M3 x 6 standoffs, M3 screws, two M2.5 screws with 3 mm nylon spacers.

## 4. Putting it together

In each picture the parts already fitted are grey and the part being fitted is in colour, with an arrow showing the way it goes in. The bench mock-up is a donor ANSI C136.41 receptacle screwed to a board and a 600 mm length of 60 mm steel or aluminium tube held in a vice or clamped to the bench.

### Step 1: board stack onto the base

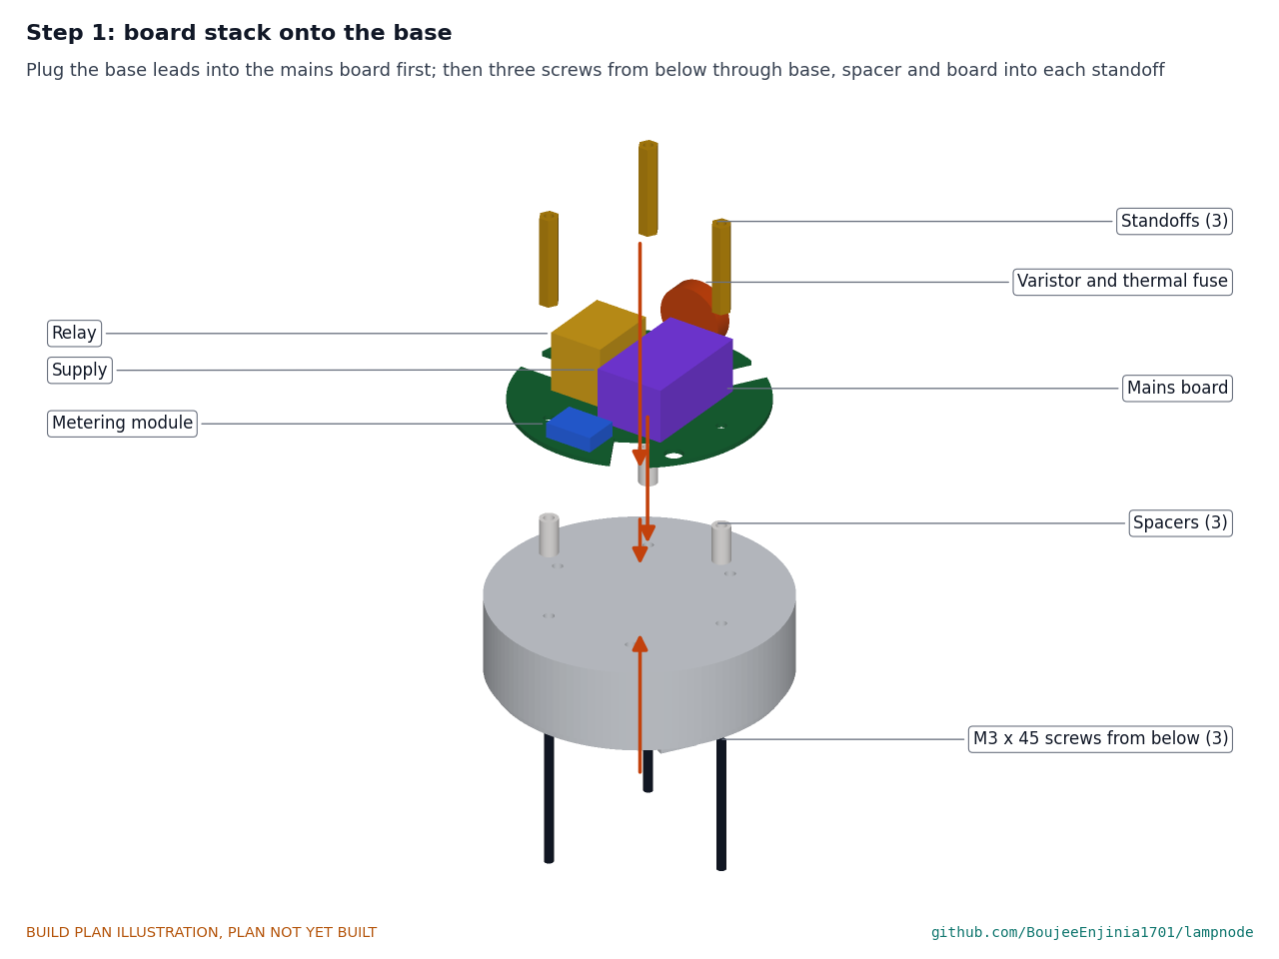
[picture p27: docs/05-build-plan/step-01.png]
Step 1


Plug the base leads into the mains board terminal block and feed the low-voltage leads up through the 6 mm hole. Stand the spacers on the base over the three stack holes, lay the mains board on them, stand a standoff over each hole, and fit three M3 x 45 countersunk screws from under the base, snug. **Hold point:** the unpowered checks of section 3.2.1 pass again.

### Step 2: controller board onto the standoffs

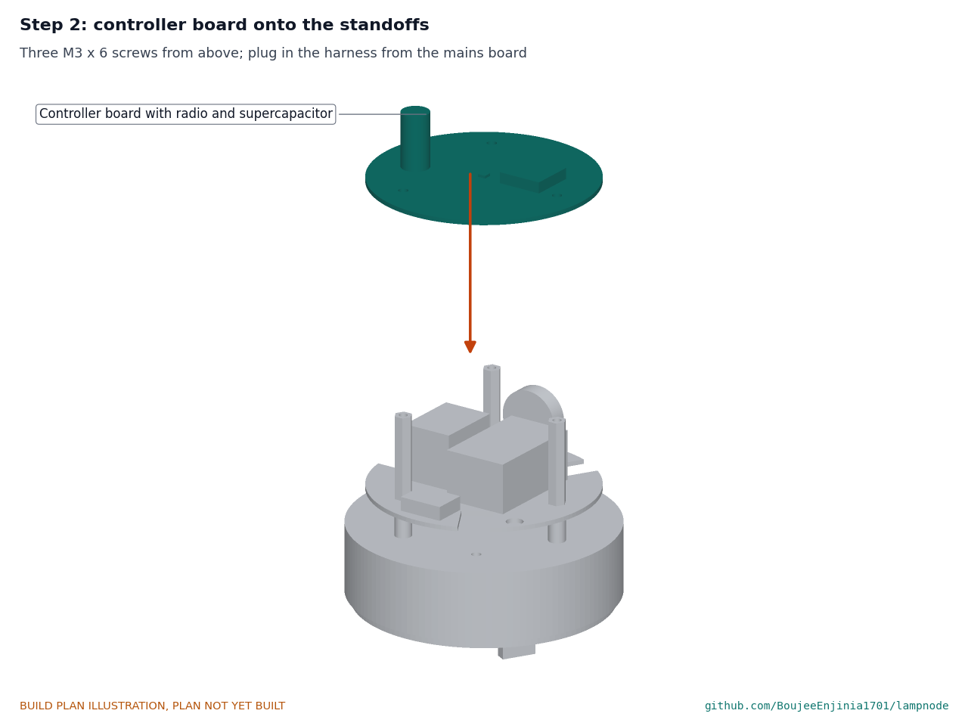
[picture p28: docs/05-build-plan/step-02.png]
Step 2


Plug in the harness from the mains board and connect the low-voltage leads to the dimming output. Fit the board with three M3 x 6 screws.

### Step 3: light pipe, antenna and M12 socket into the dome

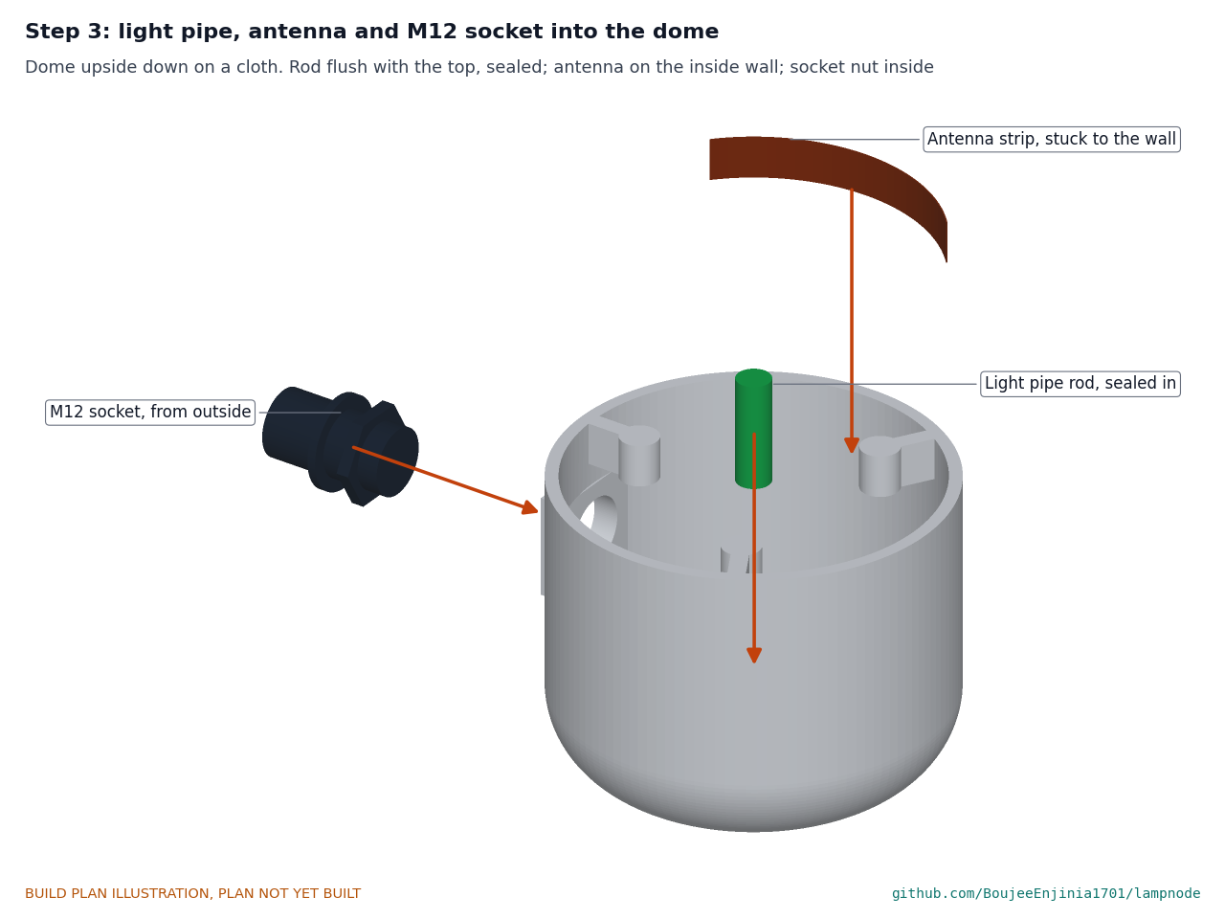
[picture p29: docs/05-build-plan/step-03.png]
Step 3


With the dome upside down on a soft cloth, fit the rod, the antenna and the socket as section 3.4 describes. Let the silicone cure for a day.

### Step 4: dome onto the base

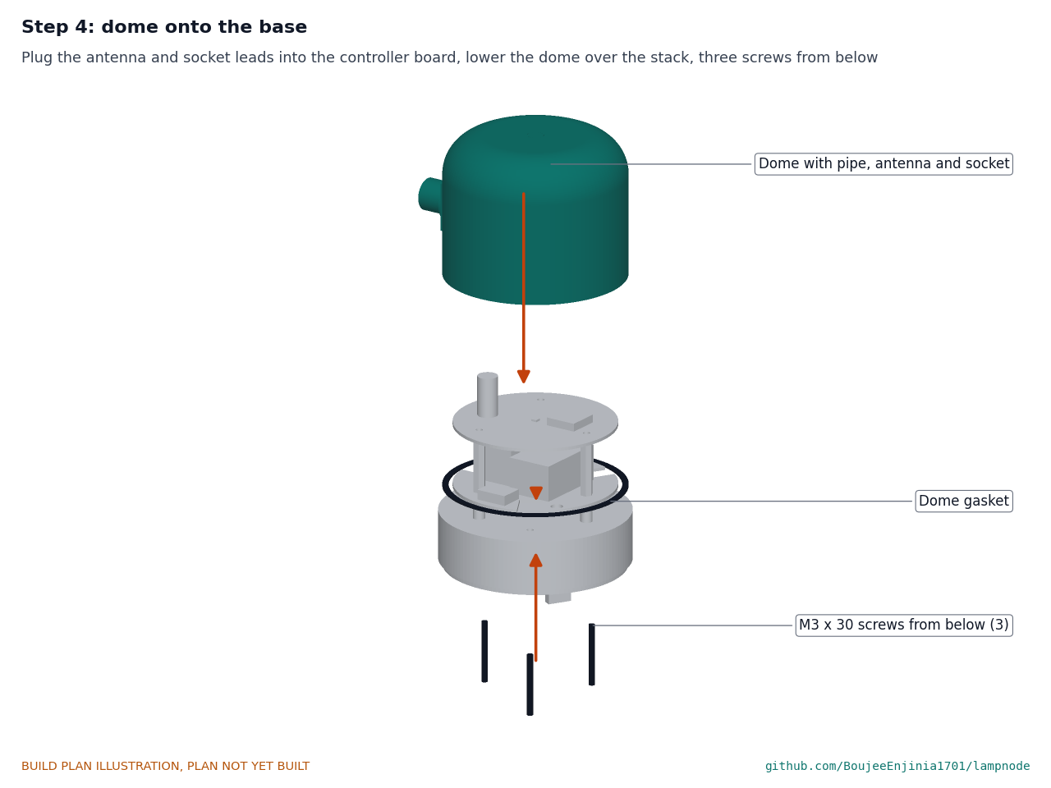
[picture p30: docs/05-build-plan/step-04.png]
Step 4


Plug the antenna lead into the radio and the socket leads into the controller board. Lay the rubber ring on the base, lower the dome over the stack so the bosses pass through the notches, and fit three M3 x 30 countersunk screws from under the base, tightened evenly until the ring is just squeezed. **Hold point:** safety stop S2.

### Step 5: gland into the box, ports into the lid

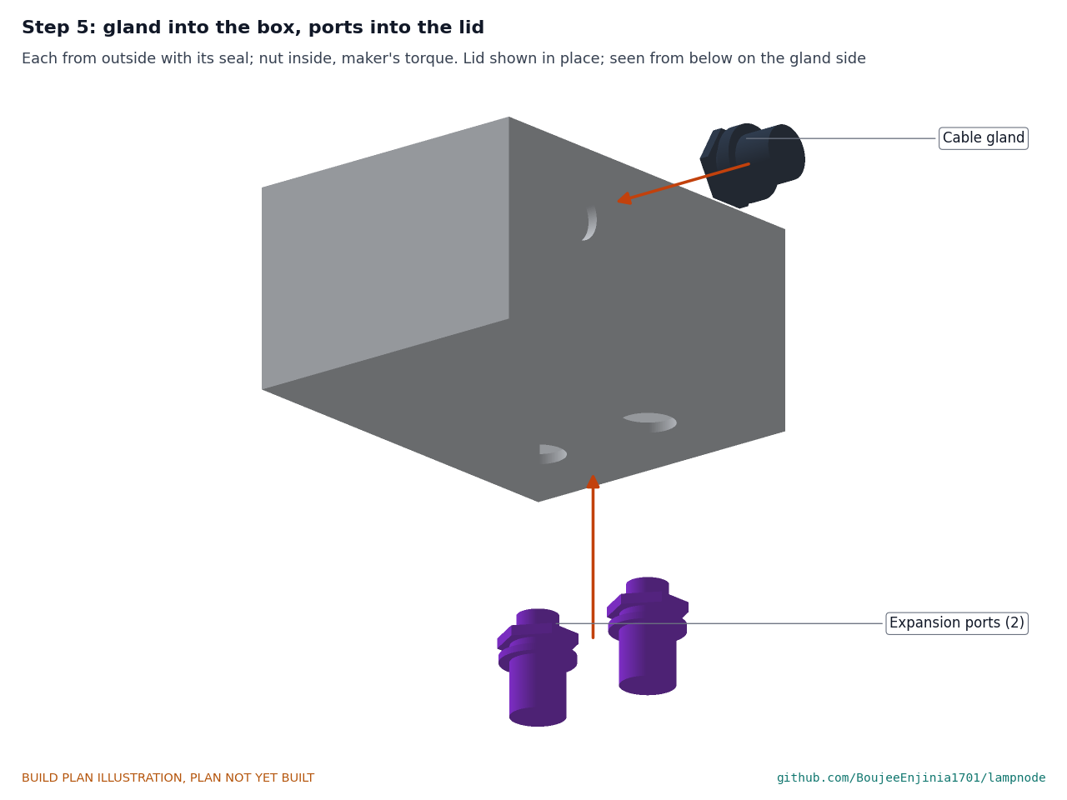
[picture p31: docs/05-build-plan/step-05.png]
Step 5


Fit each from outside with its seal, nut inside, to the maker's torque, as section 3.5.

### Step 6: radar and head board onto the internal plate

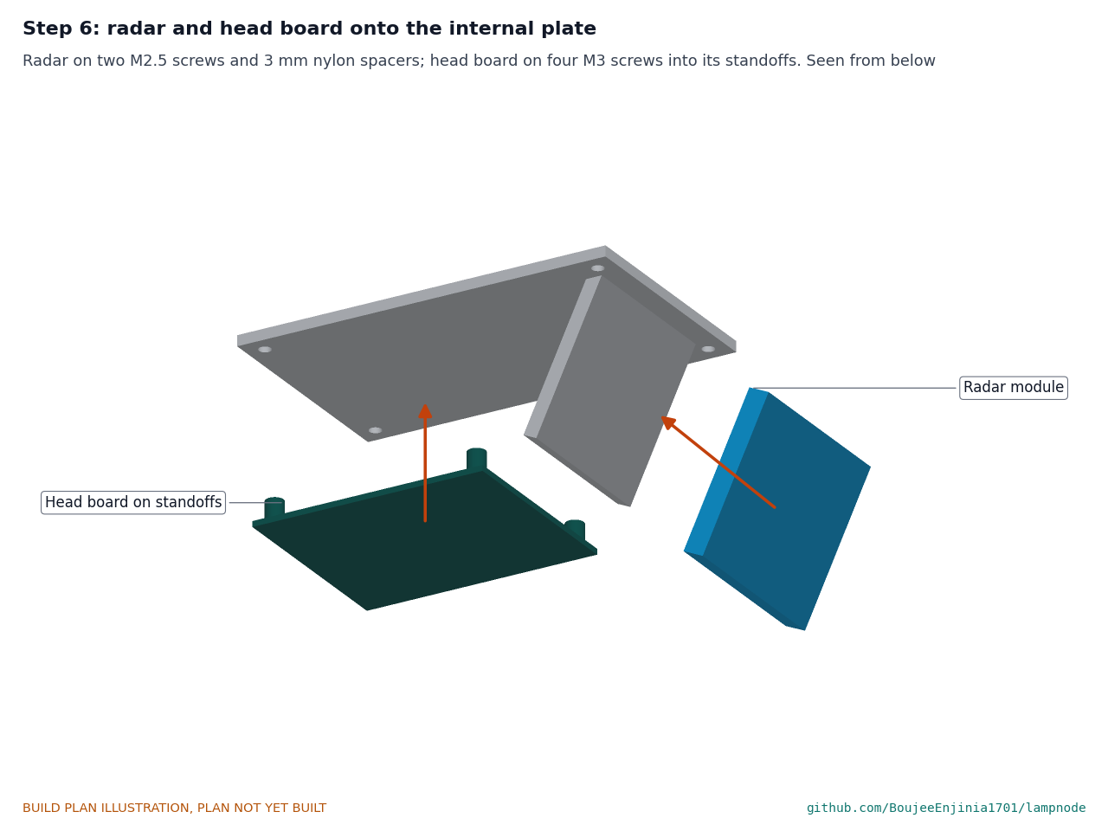
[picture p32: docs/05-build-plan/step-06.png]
Step 6


Radar on two M2.5 screws and 3 mm nylon spacers, face toward the street end; head board on four M3 screws into its standoffs.

### Step 7: internal plate into the box

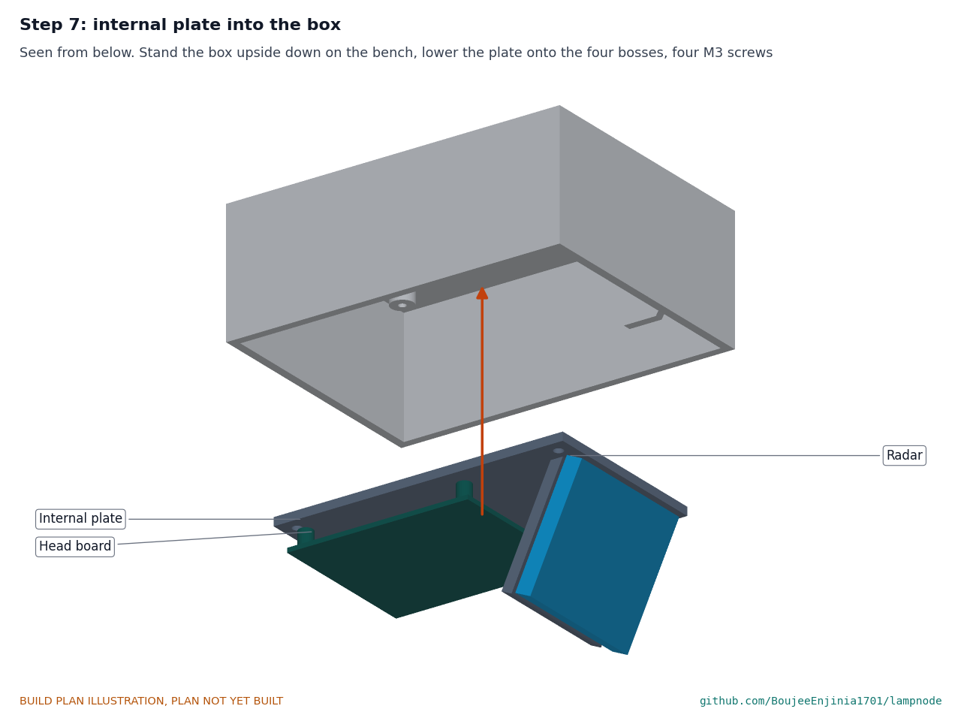
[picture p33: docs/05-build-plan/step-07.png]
Step 7


Box upside down on the bench. Four M3 screws through the plate into the bosses.

### Step 8: bracket onto the box top

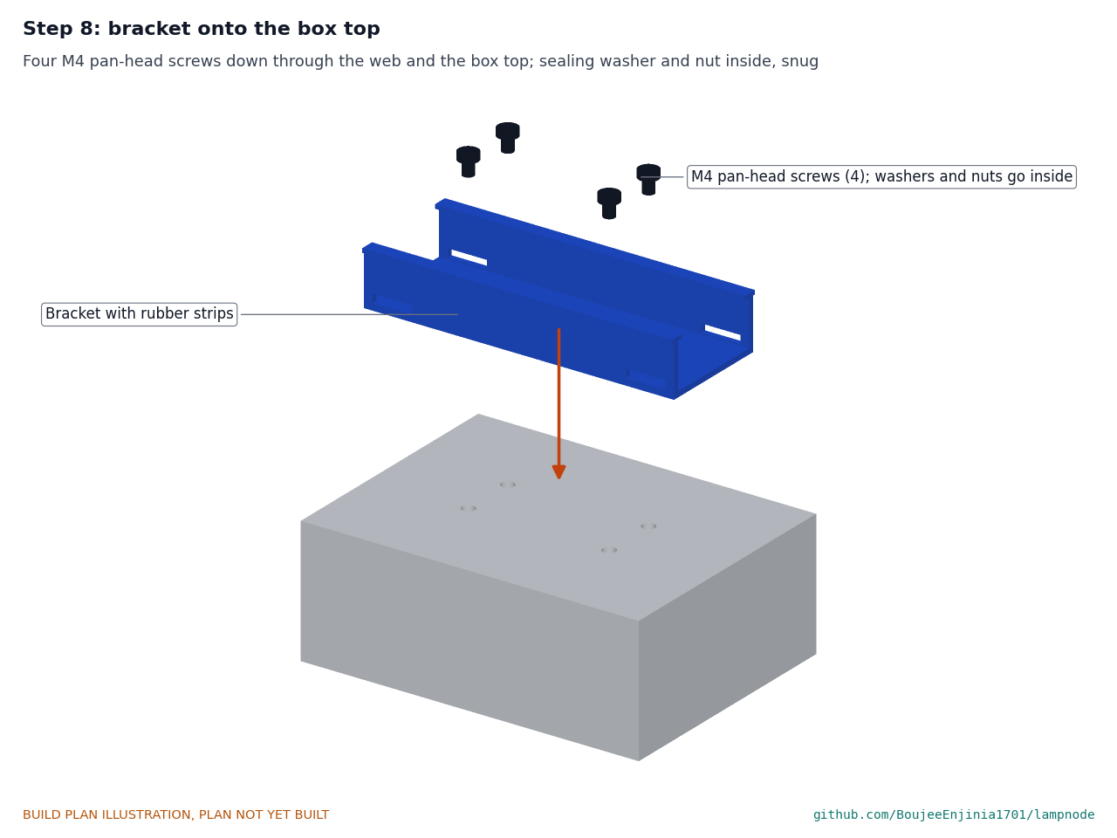
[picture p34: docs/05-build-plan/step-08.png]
Step 8


Four M4 x 12 pan-head screws down through the web and the box top, bonded sealing washer and nut inside, snug: the washer should just bulge.

### Step 9: cable in, leads plugged, lid on

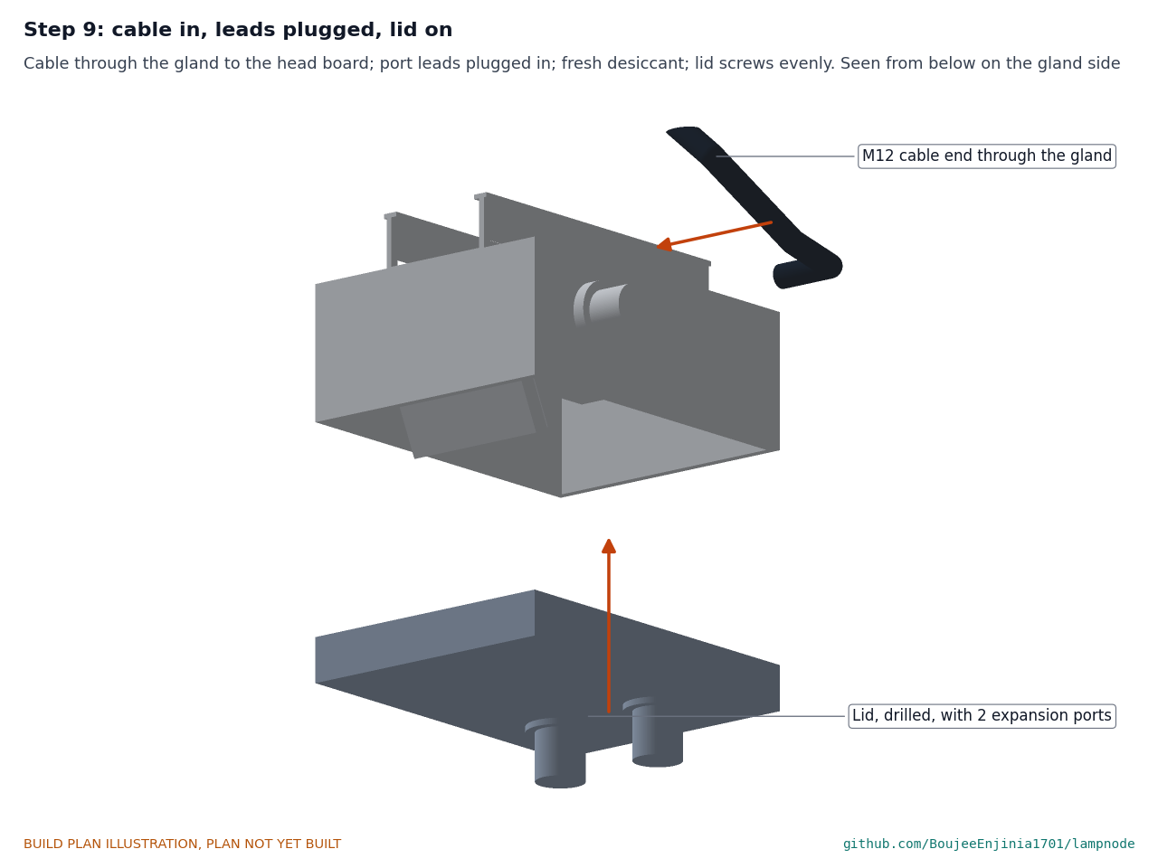
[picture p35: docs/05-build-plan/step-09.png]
Step 9


Pass the open end of the M12 cordset through the gland, connect it to the head board (pin 1 12 V, pin 3 0 V, pins 2 and 4 the two data wires) and tighten the gland. Plug in the port leads, add a fresh desiccant pack, check the lid gasket is clean with no wire across it, and tighten the lid screws evenly in a cross pattern.

### Step 10: sensor head onto the arm

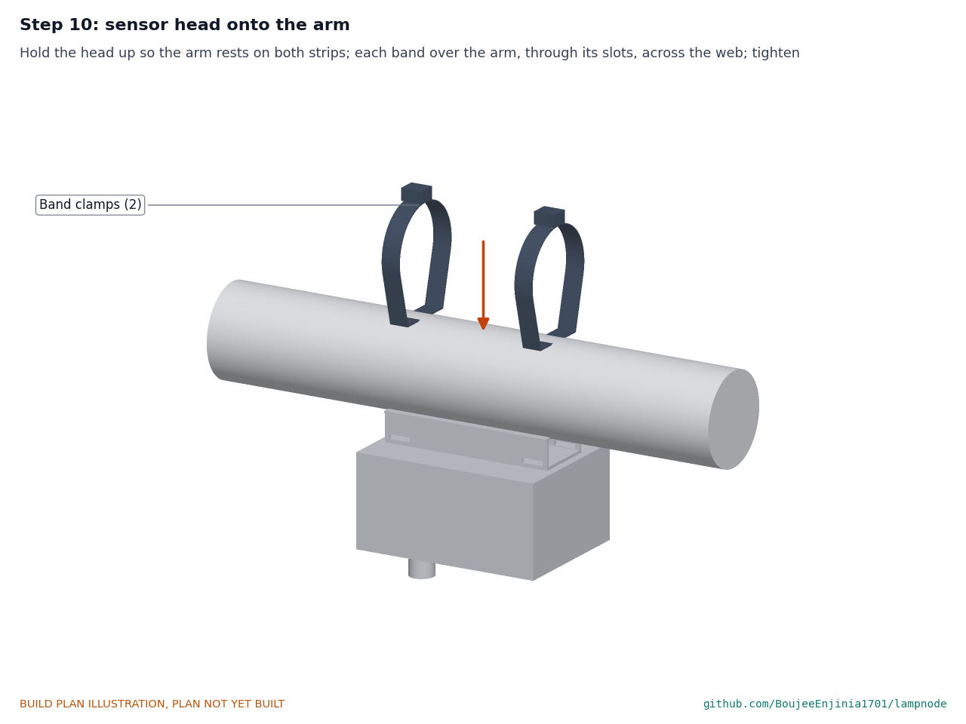
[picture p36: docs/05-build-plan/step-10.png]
Step 10


Hold the head up under the tube so the tube rests on both rubber strips, with the radar end wall toward the street end. Pass each band over the tube, down outside the flanges, through its two slots and across the web, and tighten both to the band maker's torque with the worm housing on top. Check the radar end wall is square to the tube.

### Step 11: controller into the receptacle, cable along the arm

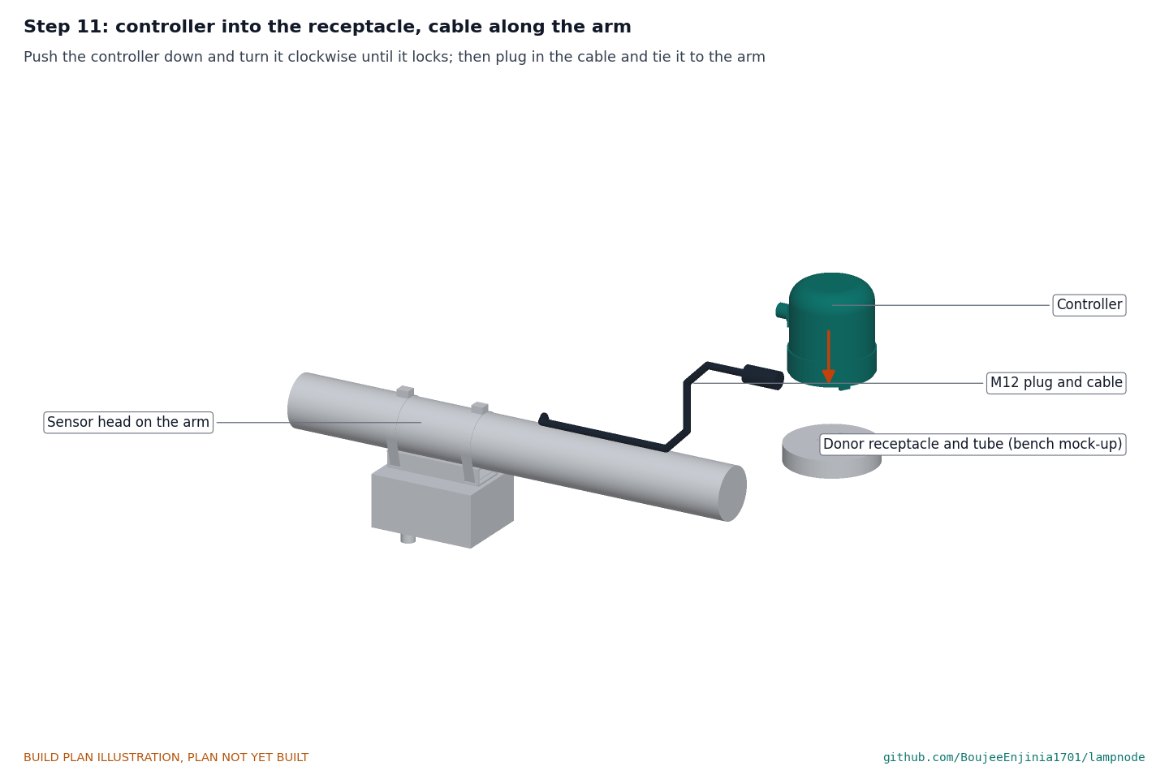
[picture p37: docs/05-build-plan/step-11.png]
Step 11


Push the controller into the receptacle with the M12 pad toward the pole and turn it clockwise until it locks. Then plug the cable into the socket, lead it level past the end of the receptacle, down to the top of the tube and along it to the head, leaving a slack loop at the controller, and tie it to the tube every 150 mm. **Hold point:** safety stop S4 before any power.

## 5. First checks

These are the checks a TRL 4 test report would record; this plan only lists them. Requirement numbers are those of LPN-REQ-001.

*Table 3. First checks.*

| Check | Requirement | How | Pass when |
| --- | --- | --- | --- |
| Fits the socket | R1 | Turn the controller into the donor receptacle and out again, timed | Locks and unlocks by hand; blades and contacts seat; under 5 min with gloves |
| Lamp on when unpowered | R12 | Meter across the base line and load blades, nothing powered | Closed circuit |
| Insulation | R2, R11 | 500 V insulation tester between the joined mains blades and every 12 V point, ports and M12 pins | 10 MΩ or more |
| First power | R2, R10 | Through an isolating transformer and an RCD at the local mains voltage, and at 120 V and 277 V from a variable transformer if one is available; dome on; power meter in the line | 12 V present at the M12 socket; average input power 1.0 W or less with the ports unloaded |
| Relay and dimming | R3, R4, R12 | Resistive dummy load of about 100 W on the load blade; command off, on and dim from a laptop; stop the controller | Load switches at the zero crossing (oscilloscope through an isolated probe); 0 to 10 V output covers 1 to 10 V; load comes back on when the controller stops |
| Light sensor and day logic | R5, R12 | Cover and uncover the light pipe in daylight with the clock set to day, then to night | Lamp off only when both clock and light say day |
| Metering | R8 | Dummy load against a bench power meter at 10, 100 and 400 W | Within 2 % after the one-point calibration |
| Radar presence | R6 | Walk toward the bench mock-up from 20 m with the head 2 m up | Presence event before 15 m; lamp output to full within 1 s |
| Ports | R13 | Switch each port on and off; short a port through a test lead | 12 V when on, 0 V when off; the fuse trips on the short and resets |
| Last message | R9 | Remove power while the radio is joined to a test network | The power-lost message arrives |
| Head on the arm | R6 | Angle finder on the radar end wall; push the head by hand | Radar 25° down, give or take 2°; nothing moves at the bracket |

## 6. Safety stops

Stop at each point. Carry on only when everything listed is true.

- **S1. Before any part at mains voltage is soldered.** The board is unpowered and the iron is the only tool plugged in; the mains layout of Figure 6 is marked on the board with the 6 mm gap shown.
- **S2. Before the dome is screwed down for the first power-up.** The unpowered checks of section 3.2.1 pass; the insulation check of section 5 passes; no bare conductor is closer than 6 mm to the 12 V side; the relay reads closed with the coil unpowered.
- **S3. First power-up.** Only through an isolating transformer and an RCD, with the dome screwed on, the controller in the donor receptacle on the bench, and no one touching it. A competent person in mains bench testing is present. Power is removed before the dome is ever taken off.
- **S4. Before a load is switched.** Only a resistive dummy load or a spare LED driver on the bench, behind the same isolating transformer and RCD. Never a public lighting circuit.
- **S5. Before the radio or radar transmits.** The antenna is connected and matches the region's band; both modules are used within local radio rules.
- **S6. Before the head goes on the tube.** Every bracket screw is tight with its sealing washer; all sharp edges are deburred; the tube is clamped so it cannot roll or tip.
- **S7. Before any installation on a streetlight (outside this plan).** A laid-out, tested board, not the hand-wired prototype; the asset owner's permission; a qualified electrician; a bucket truck or platform, fall protection and traffic management as local rules require.

## 7. Tools, skills and workspace

**Tools.** Bench drill or a drill in a stand; drills 2.5 to 6 mm; step drill to 20 mm; countersink; coping saw and fine files; scriber, steel rule, calipers and a protractor; hand bending brake for 2 mm aluminium 110 mm long (or two lengths of steel angle clamped in a vice); 3D printer with an enclosure that prints ASA, bed at least 110 x 110 mm and 75 mm tall; soldering iron with a heat-set insert tip; ferrule crimper, wire strippers and a blade-lead crimper; multimeter; 500 V insulation tester; isolating transformer and plug-in RCD; bench power meter; oscilloscope with an isolated probe; angle finder; torque screwdriver covering about 0.5 to 5 N·m; feeler gauges; heat gun for heat-shrink.

**Skills.** Basic metalwork (marking out, drilling, filing, folding thin sheet), plastic drilling, 3D printing in ASA, through-hole soldering and crimping. Building and checking the boards unpowered needs no certified trade. Powering them is mains work: the first power-up and every powered check must be done by, or under the direct supervision of, a person competent in mains bench testing, and fitting to a real streetlight needs a qualified electrician.

**Workspace.** A bench about 1.2 x 0.6 m with a mains test corner kept apart, fed through the isolating transformer and RCD; the metalwork corner apart from the electronics; a ventilated place for the printer; a vice or clamps for the tube.

**Personal protective equipment.** Safety glasses for cutting, drilling and soldering; a dust mask when cutting circuit board; cut-resistant gloves for sheet; no gloves near a turning drill.

## 8. Where the numbers come from

- Model and constructability checks: `cad/src/model.py` (`python cad/src/model.py --check`, 80 checks); STEP and STL exports in `cad/step/` and `cad/stl/`.
- Pictures: `cad/src/build_plan_media.py`, using `.kit/build_views.py`; written to `docs/05-build-plan/` and `cad/drawings/LPN-DWG-101` to `LPN-DWG-108`.
- General arrangement: `cad/drawings/LPN-DWG-001.pdf`, Rev P4.
- Calculations: `docs/04-calcs/01-sizing.md` (LPN-CAL-001 v0.3) and `docs/04-calcs/sizing.py`; mass in section 12, cost in section 13.
- Bill of materials: `bom/bom.csv`.
- Decisions: `docs/decisions/0003-design-for-construction.md` (LPN-DDR-003), with LPN-DDR-001 and LPN-DDR-002.
- Requirements: `docs/03-requirements.md` (LPN-REQ-001 v0.5).

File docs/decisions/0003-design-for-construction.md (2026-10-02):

---
doc_id: LPN-DDR-003
title: LampNode design for construction
project: LampNode
doc_type: Design decision record
version: "0.2"
status: Draft
date: '2026-10-02'
author: Amish Chadha
license: CERN-OHL-S-2.0
revisions:
- version: "0.1"
  date: '2026-10-01'
  author: Amish Chadha
  change: Changes that make the concept physically buildable, with the reason for each; made under Amish's 2026-09-30 instruction to make the design physically buildable; open for his review
- version: "0.2"
  date: '2026-10-02'
  author: Amish Chadha
  change: 'Accepted by Amish on 2026-10-02, including the recommendations for A1, on strict bench-only terms, and A2'
---

# 0003: Design for construction

- **Date:** 2026-10-01
- **Status:** accepted. Amish, 2026-10-02: "i approve your recommendations for all 555 open decisions." This covers every change made under Amish's 2026-09-30 instruction to make the design physically buildable and the recommendations for A1 and A2 in Table 3, now decided as recommended and recorded in the design decisions register (LPN-DEC-001).

## Context

On 2026-09-30 Amish asked for every repo to get an illustrated prototype build plan and wrote: "If you are realising that the design cannot be built as per concept - fix the design assumptions to match and be physically feasible as you draw the illustrations." The concept model (`cad/src/model.py` at LPN-DWG-001 Rev P2) showed what LampNode does and where its parts sit, and its clash check passed, but most of the parts inside the controller and the sensor head floated in the air with nothing holding them, the dome and the base had no fixing between them, the light window was an open hole, and the bracket was a solid block fused to two thick rings. Checking the model part by part with build123d (overlaps, contacts, clearances, fixings and assembly order) found the eleven problems in Table 1.

The changes keep what LampNode does: the same twist-lock base and socket, the same dome size and height (97 mm with the base), the same electronics, radar, tilt and ports, the same sensor head box and position under the arm, the same cable link and the same arm range. Nothing here changes the pitch, the requirements or the product's safety case. Every change is in `cad/src/model.py`, which now runs 80 constructability checks (`python cad/src/model.py --check`): parts that must touch do touch, and parts that must stay apart are apart by at least the stated clearance. All 80 pass.

## Decision

*Table 1. Changes made to the model, the BOM and the calculations.*

| # | Problem in the concept | Change made | Why this way |
| --- | --- | --- | --- |
| P1 | The parts inside the controller floated: the supply sat 9 mm above the surge carrier with nothing under it, the relay 1 mm above it, and the controller board hung at 66 mm with no support. | Two 80 mm round boards. The mains board sits on three 12 mm spacers on the base and carries the surge stage, supply, relay and metering module; the controller board sits on three 30 mm standoffs above it. One M3 x 45 countersunk screw from under the base at each of three points clamps base, spacer and mains board into the standoff. The controller board centre moves from 66.0 to 69.4 mm. | A stack on spacers is how small mains controllers are built. One screw per corner holds both levels, and the screws sit inside the base gasket ring so the seal is untouched. |
| P2 | The dome had no fixing to the base and no seal between them. | Three bosses printed inside the dome foot on a 60 mm circle, tied to the wall by ribs, each with an M3 brass heat-set insert. Three M3 x 30 countersunk screws come up from under the base. A 1 mm EPDM ring sits under the dome foot; the bosses stop 1 mm above the base so the screws squeeze the ring. The dome body is 71 mm tall on the 1 mm ring, so the controller is still 97 mm tall. The mains board has three notches that the bosses pass through. | No screw is visible on the outside and none passes through the seal. The dome comes off with three screws from below once the controller is out of the socket. |
| P3 | The M12 socket was fixed to the curved side of the bought base, a 94 mm moulding whose wall and inside are unknown; a 16 mm panel socket cannot seal on that curve. | The socket moves to a flat printed pad on the pole side of the dome, 24 x 24 x 6 mm, its face 0.5 mm outside the base edge, socket centre 53.6 mm above the base underside, between the two boards. | The dome is printed, so the flat seat and hole cost nothing. The socket still faces the pole and the cable still runs down the arm. |
| P4 | The light window was a 16 mm open hole with the top of the light pipe 2 mm below it: rain would get in. | An 8 mm clear acrylic rod sealed into an 8.2 mm hole in the dome top, flush outside, held in a printed 10 mm sleeve, ending 0.5 mm above the light sensor on the controller board. | One part makes both the window and the pipe, and the seal is a short bead of clear sealant. |
| P5 | The antenna was drawn as a rod standing on the controller board, while BOM line 8 is a flexible PCB antenna. | A flexible antenna strip about 70 x 10 mm stuck to the inside of the dome wall on the side away from the pole, between the boards, 3 mm or more from every other part, its lead to the radio. | Matches the part bought; stuck to plastic, above the luminaire's metal body as LPN-PRC-001 intends. |
| P6 | Bought part envelopes did not fit together: a 44 x 30 x 22 mm supply, two 14 mm varistor discs and a thermal fuse lay on a carrier disc. | Supply envelope 23 x 38 x 18 mm, the size of common 5 W encapsulated 12 V modules; one 20 mm class varistor standing on the board with the thermal fuse against it, as BOM line 3 describes. The layout keeps the area under the M12 socket clear. | The concept envelope was a placeholder; real 5 W modules are this size, and the smaller footprint leaves room for the bosses, standoffs and socket. |
| P7 | The base was solid and undrilled, with nothing to fix to. | Six 3.4 mm holes through the bought base on a 60 mm circle between the blades and inside the gasket ring, countersunk from below: three for the dome, three for the board stack. | The only place inside the gasket and clear of the blade pockets and contact wells. |
| P8 | The sensor head box was a closed shell with no lid, and the head board and radar floated inside it. | Box body and 15 mm lid. A printed internal plate on the four moulded bosses in the box's base (which faces up) carries the head board below it on 6 mm standoffs and, at the street end, a cradle that holds the radar 25° down on 3 mm spacers. The radar centre sits 34.2 mm below the box top instead of 30 mm. | Uses the bosses a stock box already has. The radar keeps its 25° tilt and its place behind the radar-transparent end wall; 4 mm lower changes nothing in the radar calculation at 7.7 m height. |
| P9 | The two expansion ports were cylinders hanging under the box with no hole or nut, and the cable had no gland. | Ports through 16.2 mm holes in the lid with nuts inside and plug-in leads to the head board; an M16 cable gland on the side wall facing away from the arm, 30 mm toward the street end. | The lid comes off without unsoldering anything; every penetration has a seal outside and a nut inside. |
| P10 | The bracket was a solid 130 x 30 x 15 mm block, longer than the 120 mm box, fused to two 5 mm thick rings standing in for band clamps; the rings cut into the block. | A bracket folded from 2 mm aluminium: a 40 mm web screwed to the box top by four M4 screws with bonded sealing washers, and two flanges on which the arm rests on 1.5 mm EPDM strips. Each band clamp goes over the arm, down outside the flanges, through a 14 x 3 mm slot in each flange and across the web. The head keeps its 15 mm gap below a 60 mm arm. | A channel on a pipe is self-centring for arms from 50 to 80 mm; the band pulls the arm onto the strips and the bracket onto the arm; nothing is drilled in the arm. |
| P11 | The cable ran from the base through where the luminaire body is, and dipped into the arm on its way to the head. | The cable leaves the dome pad level, passes beyond the luminaire, drops to the top of the arm, runs along it with cable ties and comes round the side of the arm to the gland. Plugged in after the controller is turned into the socket. | Clears the luminaire and the arm; about 0.7 m of the 1 m cordset is used, leaving a slack loop for the quarter turn. |

*Table 2. Knock-on changes.*

| Item | Change | Reason |
| --- | --- | --- |
| BOM | New line 17, controller boards and fixings (USD 7.00): mains board, spacers, standoffs, inserts, screws, dome gasket, harness terminals. New line 18, head internal plate (USD 4.00, printed). Line 15 repriced to USD 7.00 (folded bracket, strips) and line 16 to USD 7.00 (sealing washers, cable ties). Specifications of lines 1 to 4, 6 to 11 and 13 updated to match the model. | Parts added for construction |
| Cost | Value-engineering target: USD 150. Estimated cost of the constructable design: USD 143.00 (USD 7.00 under the target); the concept was USD 130.00. `budget_usd` is unchanged. | Lines 17 and 18 and the repricing above |
| Mass | Controller 0.33 kg (was 0.34 kg); sensor head with clamps and cable 0.42 kg (was 0.45 kg). | Real supply size; folded bracket in place of the solid block; boards and fixings added |
| Calculations | LPN-CAL-001 v0.3: sections 12 and 13 and the R16 row. Energy, power, inrush, radar, metering, surge and thermal results are unchanged: the dome keeps its size, the radar its tilt and near enough its height, and the electronics their power figures. | Follows the model |
| Drawing | LPN-DWG-001 Rev P3; making sketches LPN-DWG-101 to 108 added. | Follows the model |
| Documents | LPN-PRC-001 v0.5 (component table, mass, cost), LPN-REQ-001 v0.5 (R16 against the value-engineering target). No requirement changed status: 0 not met, 4 at risk (R3, R6, R7, R11), 11 met on paper, by design review or under the value-engineering target, 1 not verifiable at TRL 3 (R1). | Follows the model |

*Table 3. Proposed, then accepted by Amish as recommended on 2026-10-02.*

| # | Question | Options | Recommendation |
| --- | --- | --- | --- |
| A1 | The first prototype's mains board is a hand-wired plated prototype board carrying parts at up to 305 V. That is acceptable on a bench behind an isolating transformer and an RCD, but not on a street. | (a) build the first prototype on hand-wired boards for bench work only, and lay out a printed circuit board (TRL 4) before any outdoor or luminaire-powered test; (b) lay out the mains board before building anything. | (a): it tests the mechanics, fixings and fail-on behaviour soonest, and the build plan's safety stops keep it off the street. Accepted 2026-10-02 on strict terms: bench only; powered only through an isolating transformer and an RCD with the dome on; the 6 mm gap between mains and low voltage checked before first power; a laid-out board before any outdoor or luminaire-powered test. |
| A2 | The M12 socket moves from the base to the dome (P3), which changes the controller's look from the pole side. The photoreal renders and `cad/src/product_model.py` still show it on the base. | (a) accept, and update the appearance model and renders on Amish's Mac; (b) look for a bought base with a socket boss. | (a). Accepted 2026-10-02. |

## Consequences

- `design_state: constructable` in `project.yaml`. The build plan LPN-BLD-001 shows every component and step in pictures generated from the model (`cad/src/build_plan_media.py`); open items are in the design decisions register LPN-DEC-001.
- The photoreal renders (`media/render-*.png`), `media/card.png`, `media/social-preview.png` and the appearance model `cad/src/product_model.py` still show the concept: M12 socket on the base, solid bracket and the earlier window. They need updating on Amish's Mac, where Blender is.
- The base kit, the head box, the M12 socket, the supply, relay and radar module are chosen at TRL 4; the sizes this record assumes for them are listed as items to confirm in LPN-DEC-001.

> **Safety:** The controller carries mains voltage (up to 277 V AC nominal, 305 V maximum). None of the changes above alters the fail-on relay, the surge stage or the isolation between the mains and 12 V sides; the board layout keeps 6 mm of bare board between them. The hand-wired mains board of the first prototype is for bench work only (A1, accepted 2026-10-02): it is powered only through an isolating transformer and an RCD with the dome on, after the 6 mm gap has been checked, and a laid-out board is made before any outdoor or luminaire-powered test (build plan safety stops S2, S3 and S7).

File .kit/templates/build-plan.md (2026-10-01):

---
doc_id: PRJ-BLD-001
title: Project prototype build plan
project: Project name
doc_type: Build plan
version: "0.1"
status: Draft
date: YYYY-MM-DD
author: Amish Chadha
license: CERN-OHL-S-2.0
revisions:
  - version: "0.1"
    date: YYYY-MM-DD
    author: Amish Chadha
    change: First build plan; design made constructable
---

# Project prototype build plan

**Plan, not yet built.** How to build the first proof-of-concept prototype, component by component. Building and testing to it is TRL 4 work. Decisions still to be made are kept in the design decisions register (`docs/06-design-decisions.md`), not here.

## 1. What you are building

Every component, pulled apart and numbered in build order

One short paragraph: what the prototype is, how many components, which are made and which are bought, and the main ways they are made.

## 2. What changed to make it buildable

| Component | The concept had | The buildable design has | Why |
| --- | --- | --- | --- |

## 3. Making the components

### 3.1 Component name

Making sketch

**What it is and what it is made from.**

**How to make it.**

1. Mark out ...
2. Cut ...

**How it fits the parts next to it.**

Close-up of the joint

**Check before moving on.**

## 4. Putting it together

### Step 1: ...

Step 1

## 5. First checks

| Check | Requirement | How | Pass when |
| --- | --- | --- | --- |

## 6. Safety stops

## 7. Tools, skills and workspace

## 8. Where the numbers come from

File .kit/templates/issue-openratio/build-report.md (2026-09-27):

---
name: Build report
about: Tell us what happened when you built, printed or tested part of this design
title: "Build report: "
labels: build-report
---

This is a research and educational prototype, not a medical device. It is a TRL 3 concept and is not released for fabrication. If you build any part of it, you do so at your own risk. Reports help everyone.

**What you built** (part, sub-assembly or test)

**Materials, tools and settings**

**What worked**

**What did not work, with photos or measurements if you have them**

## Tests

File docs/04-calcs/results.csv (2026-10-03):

key | value | unit
night hours per year at 40 N, sunset to sunrise | 4323 | h
mean night length | 11.84 | h
longest night / shortest night | 14.68 / 8.99 | h
photocell, full power | 432.3 | kWh/yr
schedule only (50 % from 23:00 to 05:00) | 324.4 | kWh/yr
schedule saving | 24.97 | %
presence profile, dimmed hours per year | 2745 | h
dimmed hours per night, mean | 7.52 | h
presence profile, luminaire only | 269 | kWh/yr
controller energy per year | 5.946 | kWh/yr
presence profile with controller | 274.9 | kWh/yr
R7 saving, ideal driver | 36.4 | %
margin over the 35 % target, ideal driver | 1.403 | points
presence profile, luminaire only, dimmed driver model | 278.8 | kWh/yr
presence profile with controller, dimmed driver model | 284.7 | kWh/yr
R7 saving, dimmed driver model (K0 = 0.06) | 34.14 | %
shortfall against the 35 % target, dimmed driver model | 0.8636 | points
energy saved per year, dimmed driver model | 147.6 | kWh
TRL 2 method, presence luminaire energy (check) | 235.7 | kWh/yr
time from detection at 15 m to about 3 m from the pole | 8.571 | s
duration of one isolated pedestrian event | 69.57 | s
isolated events per hour equal to 15 % boost | 7.762 | per h
R7 saving at 30 events per hour, dimmed driver | 22.02 | %
60 N: night hours per year | 4277 | h
60 N: photocell energy | 427.7 | kWh/yr
60 N: saving, dimmed driver model | 31.83 | %
night fraction of the year | 0.4935
relay coil average (0.40 W, day only) | 0.2026 | W
radar and head board average (night only) | 0.1135 | W
12 V side subtotal | 0.4161 | W
shunt loss, reference lamp at 120 V, averaged | 0.8461 | mW
R10 average from the mains | 0.6788 | W
12 V load, day, ports at 3 W | 3.5 | W
12 V load, night, ports at 3 W | 3.33 | W
12 V peak with radio transmit | 3.9 | W
supply loading at 25 to 50 C | 78 | %
steady current, 400 W at 100 V and PF 0.90 | 4.444 | A
steady current, reference 100 W at 120 V | 0.9259 | A
reference driver inrush at 277 V, random closing | 72.26 | A
four 100 W drivers on one relay, random closing | 289 | A
zero-cross closing, one driver, 50 Hz, 0.5 ms error | 17.09 | A
zero-cross closing, one driver, 60 Hz, 0.5 ms error | 20.48 | A
switching cycles over 20 years at 2 per day | 14600 | cycles
12-bit PWM step on 0 to 10 V | 2.441 | mV
1 % dimming step | 100 | mV
drivers per output at 2 mA control current, 10 mA sink | 5 | drivers
sink transistor dissipation at 10 mA, 10 V | 0.1 | W
32 kHz crystal (+-20 ppm) held at 25 C, 30 days | 51.84 | s
32 kHz crystal (+-20 ppm) held at -10 C, 30 days | 159.8 | s
32 kHz crystal (+-20 ppm) held at -30 C, 30 days | 318.4 | s
32 kHz crystal (+-20 ppm) held at 70 C, 30 days | 230.3 | s
TCXO RTC (+-3.5 ppm, -40 to 85 C), 30 days | 9.072 | s
radar height above the road (model) | 7.725 | m
beam center reaches the road at | 16.57 | m
pedestrian at 15 m: depression angle | 24.15 | deg
car or cyclist at 25 m: depression angle | 15.7 | deg
pedestrian coverage inside the half-power beam, near | 7.469 | m
pedestrian coverage inside the half-power beam, far | 47.85 | m
slant range to pedestrian at 15 m | 16.44 | m
received power, pedestrian at 15 m | -92.73 | dBm
noise floor (10 Hz, 35 dB effective noise figure) | -129 | dBm
SNR, pedestrian at 15 m | 36.27 | dB
slant range at 15 dB SNR, pedestrian on boresight | 55.93 | m
same with 6 dB two-way beam-edge loss | 39.6 | m
Doppler, pedestrian 1.4 m/s approaching | 205.5 | Hz
Doppler, cyclist 5 m/s approaching | 774.2 | Hz
Doppler, car 50 km/h approaching | 2151 | Hz
Doppler, drizzle 2 m/s falling (receding) | 135.9 | Hz
Doppler, heavy rain 7 m/s falling (receding) | 475.8 | Hz
detection to full output (two 128 ms frames, link, driver 0.3 s) | 0.626 | s
warning before a pedestrian at 15 m reaches the pole | 10.71 | s
current range, 10 W at 305 V PF 0.5 to 400 W at 100 V | 66 mA to 4.44 A
shunt signal at minimum current (2 mOhm) | 0.1311 | mV
ratio of full scale to minimum signal | 168.7 | :1
shunt dissipation at 4.44 A | 0.03951 | W
metering IC over 1000:1 | 0.5 | %
shunt tempco 50 ppm/K over 50 K | 0.25 | %
divider tempco | 0.1 | %
phase error 0.1 deg at PF 0.5 | 0.3023 | %
bench reference for one-point calibration | 0.5 | %
error with one-point calibration, RSS | 0.8148 | %
error with one-point calibration, worst-case sum | 1.652 | %
worst-case sum without calibration (1 % shunt, 0.2 % divider) | 2.352 | %
24-byte status at SF7: time on air | 82.18 | ms
96 per day at SF7 | 7.889 | s/day
24-byte status at SF8: time on air | 143.9 | ms
96 per day at SF8 | 13.81 | s/day
24-byte status at SF9: time on air | 267.3 | ms
96 per day at SF9 | 25.66 | s/day
24-byte status at SF10: time on air | 493.6 | ms
96 per day at SF10 | 47.38 | s/day
US915 DR0 (SF10, 125 kHz): largest payload inside the 400 ms dwell limit | 11 | bytes
US915 DR1 (SF9, 125 kHz): largest payload inside the 400 ms dwell limit | 53 | bytes
US915 DR2 (SF8, 125 kHz): largest payload inside the 400 ms dwell limit | 125 | bytes
US915 DR3 (SF7, 125 kHz): largest payload inside the 400 ms dwell limit | 242 | bytes
US915 SF9 or faster needed for the 24-byte status (SF10 time on air over 400 ms) | 93.57 | ms over
6-byte fault message at SF9 | 185.3 | ms
6-byte fault message at SF10 (DR0) | 329.7 | ms
last-gasp energy at SF10, 22 dBm | 0.1441 | J
0.22 F supercapacitor, 5.0 to 3.6 V, usable | 1.324 | J
last-gasp margin | 9.191 | x
supercapacitor charge time at 20 mA | 55 | s
8/20 us wave: charge per ampere of peak | 23.54 | us
MOV energy at 5 kA, clamping about 1000 V (385 V class) | 117.7 | J
MOV energy at 10 kA, clamping about 1150 V (385 V class) | 270.7 | J
MOV continuous rating over 305 V maximum, 320 V class | 4.918 | %
MOV continuous rating over 305 V maximum, 385 V class | 26.23 | %
projected area in sun at 60 deg elevation | 98.74 | cm2
solar gain, absorptance 0.35 | 3.456 | W
outer area | 337.9 | cm2
film coefficient, still air plus radiation | 12.41 | W/(m2 K)
internal dissipation, day, ports unloaded | 0.7944 | W
internal dissipation, day, ports at 3 W | 1.544 | W
shell rise over 45 C ambient, ports unloaded | 13.32 | K
interior (shell + 5 K), ports unloaded | 63.32 | C
interior (shell + 5 K), ports at 3 W | 64.53 | C
supply capacity at that interior temperature (derating assumption) | 3.547 | W
12 V peak demand, ports at 3 W (no limit) | 3.9 | W
interior (shell + 5 K), ports limited to 2.5 W | 64.33 | C
supply capacity at that interior temperature | 3.567 | W
12 V peak demand with the port limit | 3.4 | W
margin with the port limit | 0.1671 | W
one port at 3 W, 10 m of 0.34 mm2 cable: drop | 0.2529 | V
as a share of 12 V | 2.108 | %
controller to head cable current | 0.2692 | A
drop over 1 m | 0.02723 | V
controller: dome, ASA | 0.07681 | kg
controller: base, PC at 35 % of the solid envelope, brass blades | 0.09221 | kg
controller: power supply module | 0.03 | kg
controller: relay | 0.02 | kg
controller: surge stage and fuse | 0.02 | kg
controller: controller board and supercapacitor | 0.03 | kg
controller: antenna and light pipe | 0.01 | kg
controller: mains board (FR4), spacers, standoffs, inserts, screws, gasket | 0.03326 | kg
controller: wiring, potting | 0.02 | kg
head: enclosure, PC | 0.1559 | kg
head: radar | 0.02 | kg
head: head board | 0.02 | kg
head: two M12 ports | 0.03 | kg
head: internal plate and cradle, ASA at 60 % infill | 0.0178 | kg
head: bracket (aluminium), rubber strips, two band clamps | 0.08381 | kg
head: M12 socket, plug and 1 m cable, gland | 0.09 | kg
controller mass | 0.3323 | kg
sensor head with clamps and cable | 0.4176 | kg
BOM lines | 18
controller parts (items 1 to 9 and 17) | 75 | USD
sensor head, cable and ports (items 10 to 15 and 18) | 61 | USD
hardware and consumables (item 16) | 7 | USD
BOM total | 143 | USD
value-engineering target (budget_usd, project.yaml) | 150 | USD
under the value-engineering target by | 7 | USD
payback on parts at $0.10/kWh | 9.691 | years
payback on parts at $0.25/kWh | 3.876 | years
requirement | title | result | status
R1 | Fit the socket | Representative ANSI C136.41 base in the model; fit and 5 min change not checkable on paper | Not verifiable at TRL 3
R2 | Mains range | Supply 85 to 305 V; 385 V class MOV; 120 to 277 V scope (DDR item 9) | Met (design review)
R3 | Switch the luminaire | 4.44 A steady at 400 W; inrush 72 A per 100 W driver, 289 A for four; about 20 A with zero-cross closing | At risk
R4 | Dim the luminaire | 2.4 mV steps; 10 mA sink = 5 drivers at 2 mA; D4i is a later variant (DDR item 5) | Met (design review)
R5 | Schedule without the network | Crystal: 160 s at -10 C, 318 s at -30 C per 30 days (not met); TCXO clock: 9 s | Met on paper with the TCXO clock
R6 | Detect presence | Beam covers 7.5 to 48 m; SNR 36 dB at 15 m; 0.63 s to full; clutter and rain unverified | At risk
R7 | Save energy | 36.4 % ideal driver, 34.1 % dimmed driver model, target 35 % | At risk
R8 | Measure energy | 1.65 % worst case with one-point calibration (2.35 % without) | Met on paper (calibration required)
R9 | Report faults | Last gasp 0.144 J against 1.32 J stored; 15 min status | Met (design review)
R10 | Self-consumption | 0.68 W average | Met on paper
R11 | Environment | Interior 63 to 65 C at 45 C in sun (70 C rating); MOV 118 J at 5 kA; IP66 and surge need tests | At risk
R12 | Fail safe | NC relay, open 0 to 10 V = full, coil needs a toggling drive, day decision needs clock AND light sensor | Met (design review)
R13 | Host other sensors | 0.25 V drop at 10 m; ports limited to 2.5 W above 50 C inside (DDR-002): 3.40 W peak against 3.57 W at 64 C (3.90 W against 3.55 W without the limit) | Met on paper (firmware port limit)
R14 | Privacy | Doppler radar, no image; presence counts only | Met (design review)
R15 | Secure and open | LoRaWAN 1.0.4, US915, open payload; 25.7 s/day at SF9, inside the 400 ms dwell limit; TALQ in CityTwin (DDR item 10) | Met (design review)
R16 | Affordable | USD 143.00 against the USD 150 value-engineering target | Under the target by USD 7.00

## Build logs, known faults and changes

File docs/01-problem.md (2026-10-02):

---
doc_id: LPN-PRB-001
title: LampNode problem statement
project: LampNode
doc_type: Problem statement
version: "0.5"
status: Draft
date: '2026-10-02'
author: Amish Chadha
license: CERN-OHL-S-2.0
revisions:
- version: "0.1"
  date: '2026-09-25'
  author: Amish Chadha
  change: Initial scaffold
- version: "0.2"
  date: '2026-09-25'
  author: Amish Chadha
  change: Problem, users, operating environment, constraints, prior work and open questions for TRL 2
- version: "0.3"
  date: '2026-09-25'
  author: Amish Chadha
  change: Open questions updated for the choices adopted for TRL 3 under Amish's 2026-09-25 instruction, open for his review (LPN-DDR-001); out-of-scope items and sibling interfaces aligned
- version: "0.4"
  date: '2026-09-25'
  author: Amish Chadha
  change: Recommendations accepted by Amish (DDR-002)
- version: "0.5"
  date: '2026-10-02'
  author: Amish Chadha
  change: 'First partner and port pinout stated as decided on 2026-10-02 (LPN-DEC-001)'
---

# LampNode problem statement

Most streetlights run at full power from dusk to dawn whether anyone is on the street or not, nobody knows a lamp has failed until someone complains, and the controllers that could fix both tie a city to one vendor's network and software. LampNode is an open controller that plugs into the standard socket on top of an LED streetlight to dim it by schedule and presence, report faults by itself and power other city sensors on the same pole.

## The problem

**Energy is spent on empty streets.** A photocell switches a luminaire fully on at dusk and fully off at dawn. On a residential street most of the hours between about 23:00 and 05:00 see little traffic, yet the lamp draws its full rated power. A study of 14 LED-lit roads in Sweden found that a dimming schedule alone could save about 49 % of the energy ([Jägerbrand, 2016](https://www.mdpi.com/1996-1073/9/5/357)).

**Light at night keeps growing.** Citizen observations of star visibility from 2011 to 2022 are consistent with the night sky brightening by 7 to 10 % per year ([Kyba et al., 2023, via GFZ](https://www.gfz.de/en/press/news/details/citizen-scientists-report-global-rapid-reductions-in-the-visibility-of-stars-from-2011-to-2022)). Street lighting is only one source, but dimming it when streets are empty is one of the few changes a city controls directly.

**Faults are found by residents.** New York City's Department of Transportation maintains nearly 400,000 streetlights and asks residents to call 311 to report a problem ([NYC DOT](https://www.nyc.gov/html/dot/html/infrastructure/streetlights.shtml)). A lamp that fails on a quiet street can stay dark until someone notices and bothers to report it; a lamp burning in daylight is rarely reported at all.

**Energy use is not even measured.** The US Energy Information Administration states that it has no estimate of electricity use specifically for public street and highway lighting ([EIA](https://www.eia.gov/tools/faqs/faq.php?id=99&t=3)). Many streetlights are billed on flat rates, so a city cannot see what a dimming policy saves.

**Controllers lock cities in.** Networked controllers exist, but the controller, the radio network and the central software usually come from one supplier. The TALQ Consortium defined its Smart City Protocol specifically to help "avoid vendor-lock-in" between central software and outdoor device networks ([TALQ](https://www.talq-consortium.org/)), which shows the problem is recognized but not solved at the device level.

## Users and context

| User | Need |
| --- | --- |
| Municipal street lighting and public works teams | Lower energy bills, fewer night patrols, a fault list that tells crews where to go, and freedom to change suppliers |
| Electric utilities that own streetlights | Measured energy per lamp, day-burner detection, remote switching during grid events |
| Road owners and lighting designers | Dimming that stays within the lighting class they set for each road |
| Residents and road users | Streets that are lit when people are on them, and fewer dark spots after faults |
| Smart city sensing projects (AirStreet, NoiseMap, CurbCount and others in this lab) | A powered, networked mounting point on existing poles |
| Community, campus and private-road operators (campuses, ports, car parks, housing associations) | The same functions at small scale without a city-wide contract |

### Operating environment

- Mounted on top of a cobra-head or post-top LED luminaire, typically 6 to 12 m above the road, in full sun, rain, ice and wind.
- Ambient temperature at the luminaire top from about -30 °C in winter to above 60 °C under summer sun (estimate; to be set per region).
- Supplied from the luminaire's mains feed, nominally 120 to 277 V AC at 50 or 60 Hz, with lightning and switching surges on long overhead or buried feeders.
- On some networks the feeder is switched at a cabinet, so the pole is unpowered in daytime; on others it is live 24 h.
- Radio path to a LoRaWAN gateway, often a TwinKit gateway or a public network, typically within 2 to 5 km in a city (estimate).
- Installed and replaced from a bucket truck by lighting crews, usually at the same time as other maintenance.

## Constraints

- Garage-buildable prototype for about $150 USD in parts (`project.yaml`), for the controller and one sensor head.
- Must plug into an existing standard receptacle with no rewiring of the luminaire.
- Must fail safe: if the controller or network fails at night, the lamp stays on.
- Must not reduce lighting below the level the road owner sets; LampNode implements a lighting policy, it does not choose one.
- Privacy: presence only. No images, audio or personal identifiers leave the device.
- Open interfaces: works with any LoRaWAN network server; payload format published.
- Mains work is done by qualified electricians; pole work by trained crews with the asset owner's permission.

## Out of scope

- Choosing lighting classes or light levels for roads; these belong to the road owner and local standards.
- Revenue-grade metering for billing; LampNode reports indicative energy, not a certified meter reading.
- Cameras, audio capture or identification of people or vehicles.
- A replacement for the luminaire's own surge protection or driver.
- 347 V and 480 V circuits in the first design; a later variant if a partner needs it (LPN-REQ-001 R2, LPN-DDR-001 D9).
- DALI-2 D4i dimming in the first design; a later variant if a partner's stock needs it (LPN-DDR-001 D5).
- A TALQ bridge; interoperability with central software belongs to CityTwin (LPN-DDR-001 D10).

## Prior work

- **Socket standards.** ANSI C136.41 defines the twist-lock photocontrol receptacle widely used on roadway luminaires in North America, including versions with extra contacts for dimming. Zhaga Book 18 defines "a standardized interface between an outdoor LED luminaire and a sensing/communication module that sits on the outside of the luminaire" ([Zhaga](https://www.zhagastandard.org/books/book18/)).
- **D4i drivers.** D4i LED drivers carry an intra-luminaire DALI bus with bus power for control devices, an optional 24 V auxiliary supply for higher-power devices such as radios, and data on energy, diagnostics and asset information (DALI Parts 251 to 253). D4i is compatible with both ANSI C136.41 and Zhaga Book 18 sockets ([DALI Alliance](https://www.dali-alliance.org/d4i/)).
- **Central software interoperability.** The TALQ Smart City Protocol links central management software with device networks from different vendors ([TALQ](https://www.talq-consortium.org/)).
- **Adaptive lighting evidence.** Dimming schedules can save more energy than lowering a road's lighting class ([Jägerbrand, 2016](https://www.mdpi.com/1996-1073/9/5/357)).
- **Commercial controllers.** Networked streetlight controllers are sold by many lighting and utility suppliers, generally as part of a proprietary network. A survey of open-hardware controllers has not yet been done (open question 1).
- **Lab siblings.** LampNode uses the same STM32WL-class LoRaWAN radio as FieldNode and the same 5-pole M12 sensor ports (LampNode proposed a pinout to FieldNode on 2026-10-02; FieldNode has still to agree it), and reports to TwinKit and CityTwin.

## Open questions

1. Are there open-hardware streetlight controllers to learn from or join, rather than start anew?
2. Socket: ANSI C136.41 7-contact first, Zhaga Book 18 later, was decided by Amish on 2026-09-25 (LPN-DDR-001 D1, LPN-DDR-002).
3. How common are cabinet-switched feeders in the first partner city? Hosted sensors there need their own storage (LPN-REQ-001 R13). The first partner is to be a US partner on the 915 MHz band; the first candidate to approach is a university campus or municipal utility in the Dallas-Fort Worth area (decided 2026-10-02, LPN-DEC-001).
4. Will a lighting authority accept presence dimming on the roads chosen, and what floor level and hold time will it set?
5. Which 0 to 10 V and D4i drivers are in the partner's luminaire stock, and how do they behave when the control line is open?
6. What surge levels and certification does the asset owner require before a device is plugged into its network?

## User research and co-design

This design is for communities the author is not part of, so requirements come from the people who will use it.

- [ ] Identify a local partner organization (Helpful Engineering network, NGO or university)
- [ ] Run co-design sessions with intended users; record who, where and what was learned
- [ ] Validate load, distance, terrain and cost assumptions in the field
- [ ] Revise requirements (REQ) from findings before freezing the design

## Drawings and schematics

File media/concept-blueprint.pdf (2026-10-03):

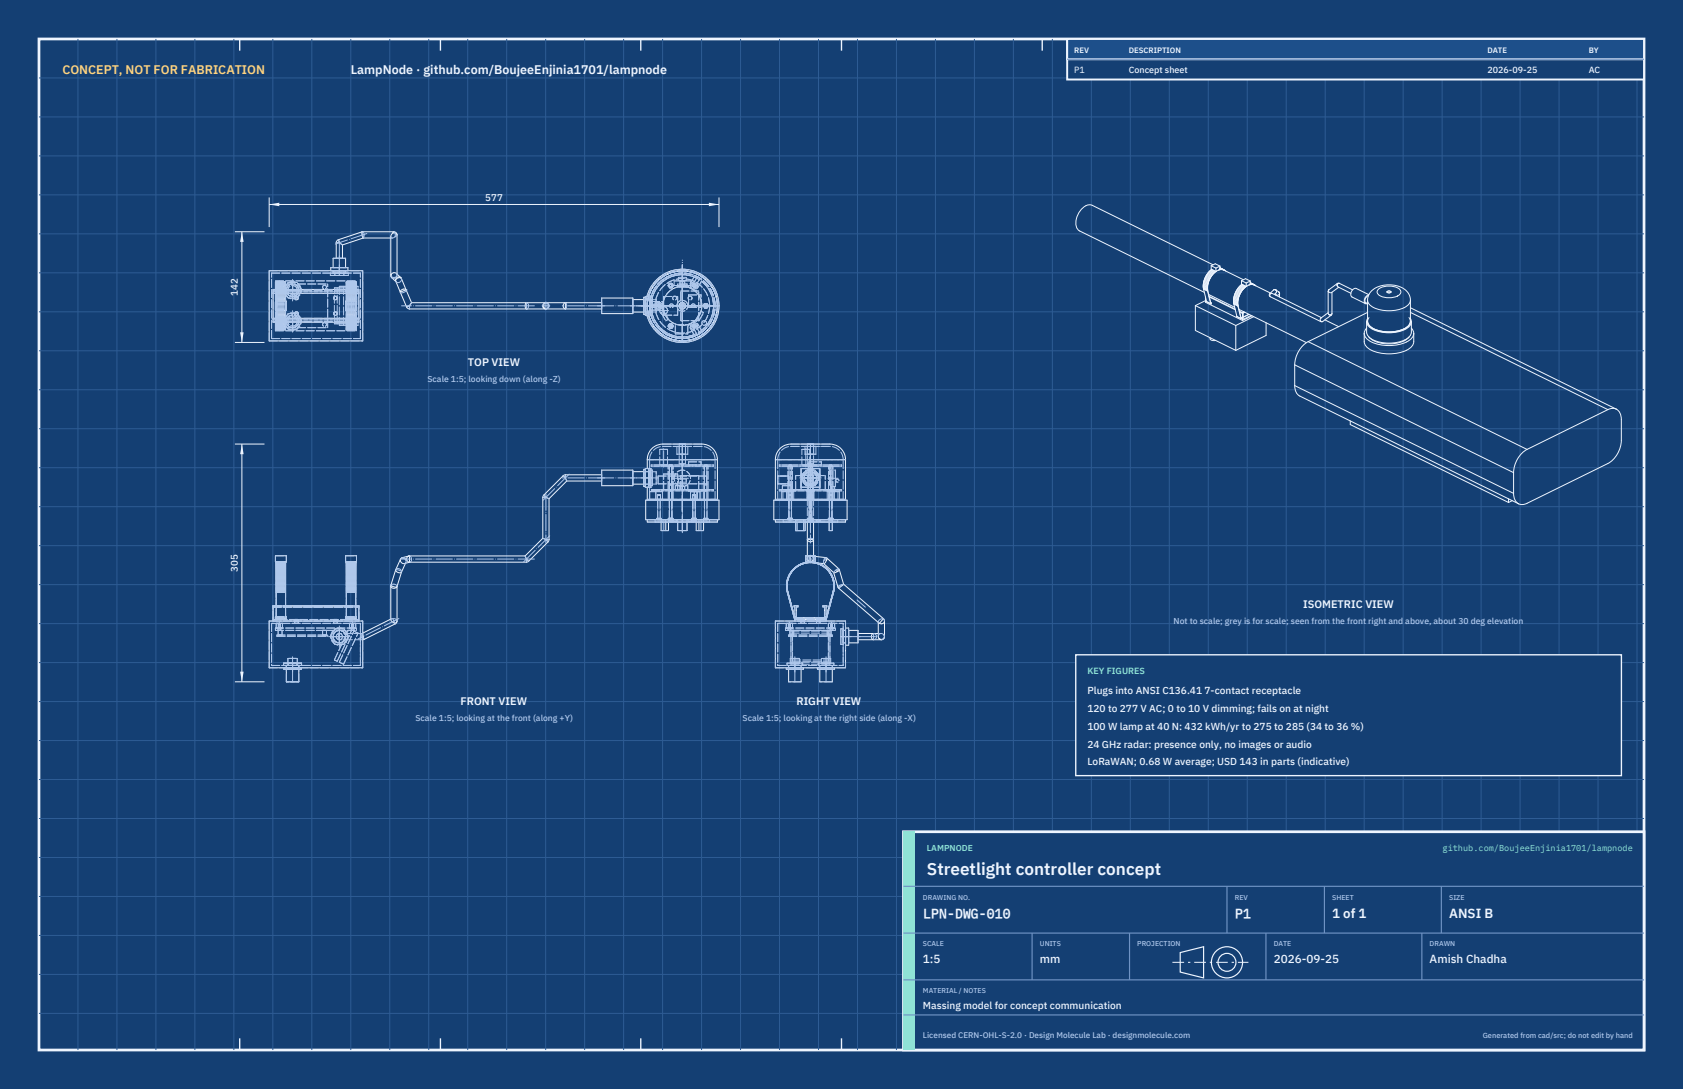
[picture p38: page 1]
CONCEPT, NOT FOR FABRICATION; LampNode · github.com/BoujeeEnjinia1701/lampnode; FRONT VIEW; TOP VIEW; RIGHT VIEW; ISOMETRIC VIEW; REV; DESCRIPTION; DATE; Concept sheet; LAMPNODE; github.com/BoujeeEnjinia1701/lampnode; DRAWING NO. LPN-DWG-010; REV P1; SHEET 1 of 1; SIZE ANSI B; SCALE 1:5; UNITS mm; PROJECTION; DRAWN Amish Chadha; Licensed CERN-OHL-S-2.0 · Design Molecule Lab · designmolecule.com; Generated from cad/src; do not edit by hand

Scale 1:5; looking down (along -Z)

Not to scale; grey is for scale; seen from the front right and above, about 30 deg elevation

KEY FIGURES
Plugs into ANSI C136.41 7-contact receptacle
120 to 277 V AC; 0 to 10 V dimming; fails on at night
100 W lamp at 40 N: 432 kWh/yr to 275 to 285 (34 to 36 %)
24 GHz radar: presence only, no images or audio
LoRaWAN; 0.68 W average; USD 143 in parts (indicative)

Scale 1:5; looking at the front (along +Y)

Scale 1:5; looking at the right side (along -X)

Streetlight controller concept

MATERIAL / NOTES
Massing model for concept communication

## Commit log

2026-09-25 Initial scaffold: standard open hardware layout, CERN-OHL-S v2 + MIT licenses
    Claude-Session: https://claude.ai/code/session_01XuhhSU4W6fYhgCfURbrkut
    [bom.csv]
2026-09-26 Populate to TRL 2: problem, requirements, precis, concept media, BOM and README use cases
    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
    [bom.csv]
2026-09-26 Advance to TRL 3: DDR-001, CAL-001 sizing, parametric model with STEP/STL, GA drawing, priced BOM; TRL 4 on hold
    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
    [bom.csv, lampnode-assembly.step, lampnode-assembly.stl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]
2026-09-26 Accept all recommendations (DDR-002), switch footer to designmolecule.com, add README write-up with new inspiration point
    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
    [lampnode-assembly.step, lampnode-controller.step, lampnode-installed-reference.step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]
2026-09-27 Product appearance model and photoreal renders
    Adds cad/src/product_model.py (appearance model for renders only, all main
    dimensions from model.py) and Blender renders in media/render-*.png,
    captioned with the project, repository and viewing direction. README leads
    with the product render; trl stays 3.
    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
2026-10-01 Image quality pass: legible exploded views, flow diagrams and drawing sheets
    Kit 1.6.1 image layout: the parts list sits in its own column, number bubbles sit on visible parts and never overlap, small parts get a leader, pictures are cropped to the subject, flow labels keep numbers with their units, and sheet captions and the revision table no longer overprint. Concept images, blueprint and general arrangement sheet regenerated; repo-specific labels moved clear of other text and lines.
2026-10-01 Kit 1.7.0: constructable design, illustrated build plan and design decisions register
    The design is now constructable: every part can be made and fits its neighbours, with each change recorded in a Design for construction decision record (made under Amish's 2026-09-30 instruction; ope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
    FlexHand also credits Dr. Geeti Chadha as a contribut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
    [bom.csv, lampnode-assembly.step, lampnode-assembly.stl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]
2026-10-02 Record Amish's approval of the open-decision recommendations
    Amish approved the recommendation on every open decision in the design decisions register ("i approve your recommendations for all 555 open decisions.", 2026-10-02). Each decision is moved to Decisio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
2026-10-03 Carry approved follow-ups into the design and redo photoreal renders
    Amish approved the follow-up actions from the open-decision sign-off ("APPROVED CHANGES, COMPLETE THESE", 2026-10-02), the design-for-construction change tables in ten repos, the last wave's open dec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
    [bom.csv, lampnode-assembly.step, lampnode-controller.step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]

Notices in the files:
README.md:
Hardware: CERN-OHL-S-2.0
